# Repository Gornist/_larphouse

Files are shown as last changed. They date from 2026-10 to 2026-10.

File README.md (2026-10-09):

# Модульные игровые дома

Сборно-разборные деревянные дома для ролевых игр (LARP).

- **`step/6/`** — актуальная версия: модульная система на сетке 3,1 м, дома
  3×3, 3×6, 3×9, 6×6. Документация — [`step/6/README.md`](step/6/README.md),
  всё одним файлом для печати — [`step/6/Модульные_дома.pdf`](step/6/Модульные_дома.pdf).
- `step/5/` — предыдущая версия (одиночный дом 3×3), смета с источниками цен —
  `step/5/СТОИМОСТЬ.md`.

## Инструменты

- `tools/grid_house.py` — параметрическая модель v6: STEP, спецификация, смета, инструкция по сборке
- `tools/grid_draw.py` — картинки домов и деталей
- `tools/make_pdf.py` — сборка документации в PDF (pandoc + Chromium)
- `tools/v5_house.py`, `tools/v5_draw.py` — модель и картинки v5 (v6 использует их детали)
- `tools/step_io.py` — запись STEP с русскими названиями

```
pip install build123d scipy pillow
python tools/grid_house.py 6х6 step/6/6х6 step/6/блоки
python tools/grid_draw.py 6х6 step/6/6х6/img
python tools/make_pdf.py step/6 step/6/Модульные_дома.pdf
```

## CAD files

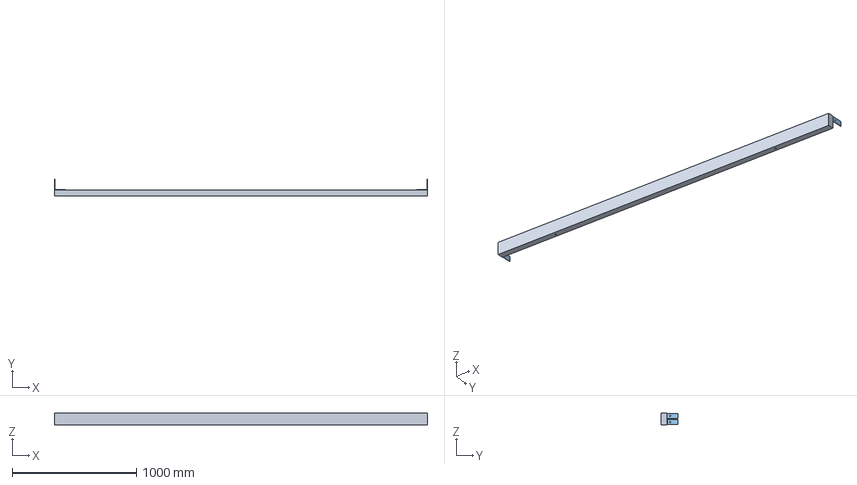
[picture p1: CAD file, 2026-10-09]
step/5/блоки/обвязка_фронтонная.step
3000.0 x 140.0 x 100.0 mm
обвязка_верхняя_ фронтонная_50х100х2996
футорка_М10 x 2
уголок_90х90х40 x 2

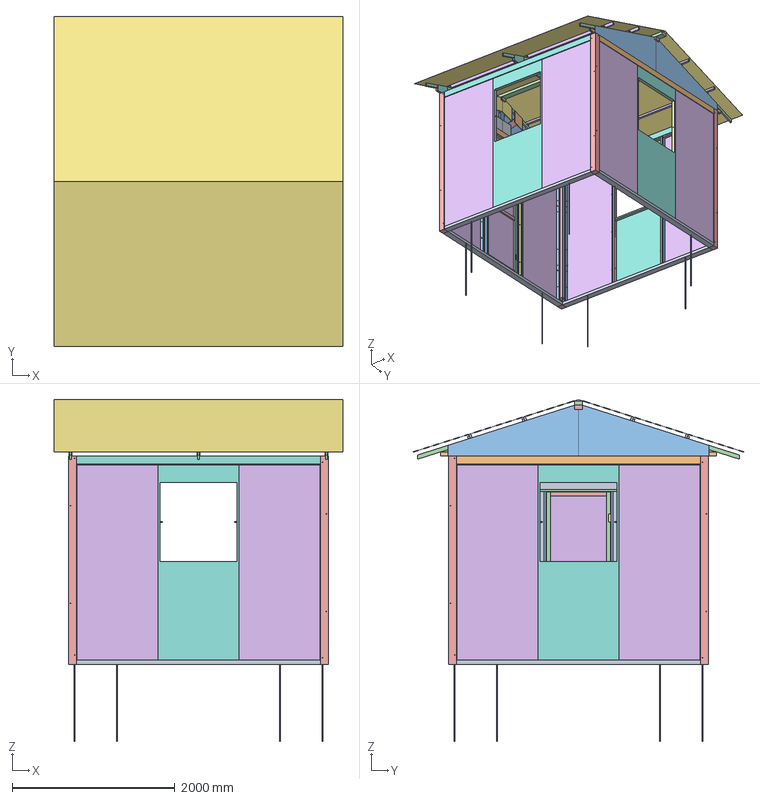
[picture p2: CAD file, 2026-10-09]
step/5/дом_v5_3х3.step
3550.0 x 4060.0 x 4206.2 mm
лежень_50х100х2996 x 4
арматура_12х1000 x 8
уголок_90х90х40 x 16
стойка_угловая_ 100х100х2560 x 4
футорка_М10 x 14
болт_М10х130 x 19
обвязка_верхняя_ карнизная_50х100х2996 x 2
обвязка_верхняя_ фронтонная_50х100х2996 x 2
стойка_щита_25х50х2400 x 24
перемычка_25х50х947 x 31
обшивка_фанера_3мм_ 997х2400 x 12
болт_М10х80 x 38
болт_М10х150 x 16
стойка_двери_25х50х2050 x 2
полотно_стойка_25х50х2040 x 2
полотно_перемычка_ 25х50х690.0 x 3
полотно_фанера_790х2040
петля_100 x 2
ручка
затяжка_25х50х1700 x 6
стойка_фермы_25х50х576 x 6
стропило_25х50х2025 x 6
подкос_25х50х538 x 6
лапка_прогона_25х25х30 x 12
косынка_вершина_ фанера_9 x 8
косынка_пята_фанера_ 9 x 8
косынка_низ_подкоса_ фанера_9 x 8
косынка_верх_ подкоса_фанера_9 x 8
обшивка_фронтона_ фанера_3 x 4
конёк_50х100х3500
бобышка_конька_25х50х100 x 6
прогон_25х50х3500 x 4
тент x 2

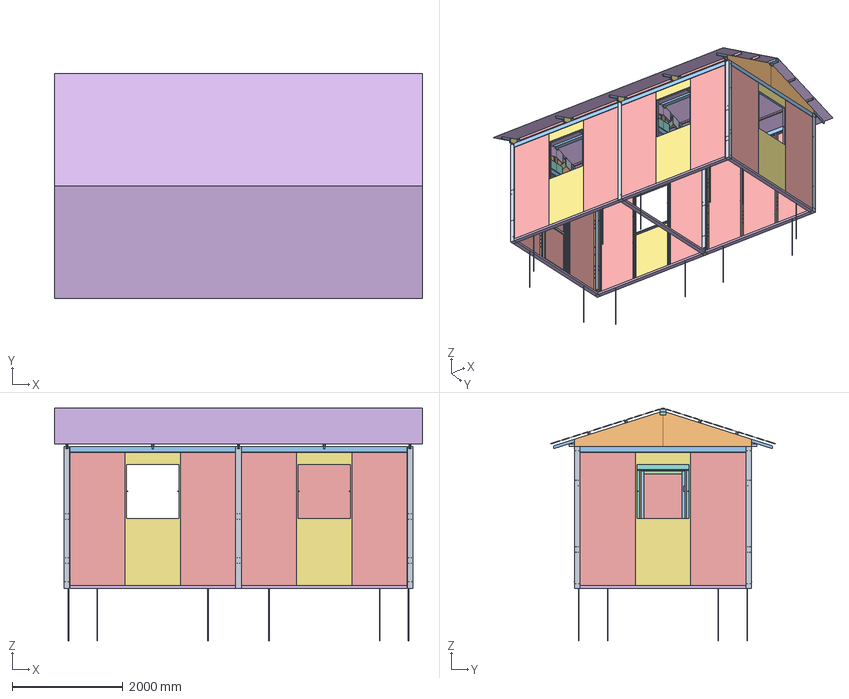
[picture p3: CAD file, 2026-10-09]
step/6/3х6/дом_3х6.step
6650.0 x 4060.0 x 4206.2 mm
стойка_100х100х2560 x 6
футорка_М10 x 48
обвязка_50х100х2996 x 7
уголок_90х90х40 x 28
болт_М10х130 x 29
лежень_50х100х2996 x 7
арматура_12х1000 x 12
стойка_щита_25х50х2400 x 36
перемычка_25х50х947 x 45
обшивка_фанера_3мм_ 997х2400 x 18
болт_М10х80 x 58
болт_М10х150 x 24
стойка_двери_25х50х2050 x 2
полотно_стойка_25х50х2040 x 2
полотно_перемычка_ 25х50х690.0 x 3
полотно_фанера_790х2040
петля_100 x 2
ручка
затяжка_25х50х1700 x 10
стойка_фермы_25х50х576 x 10
стропило_25х50х2025 x 10
подкос_25х50х538 x 10
лапка_прогона_25х25х30 x 20
косынка_фанера_9 x 64
обшивка_фронтона_ ФСФ_3 x 4
конёк_50х100х3300 x 2
бобышка_конька_25х50х100 x 10
прогон_25х50х3300 x 8
тент x 2

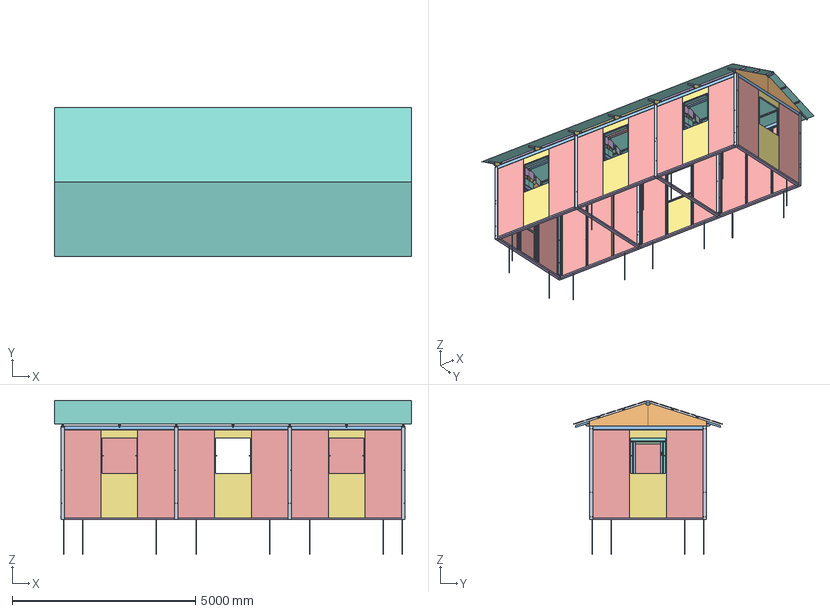
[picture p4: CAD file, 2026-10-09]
step/6/3х9/дом_3х9.step
9750.0 x 4060.0 x 4206.2 mm
стойка_100х100х2560 x 8
футорка_М10 x 68
обвязка_50х100х2996 x 10
уголок_90х90х40 x 40
болт_М10х130 x 39
лежень_50х100х2996 x 10
арматура_12х1000 x 16
стойка_щита_25х50х2400 x 48
перемычка_25х50х947 x 59
обшивка_фанера_3мм_ 997х2400 x 24
болт_М10х80 x 78
болт_М10х150 x 32
стойка_двери_25х50х2050 x 2
полотно_стойка_25х50х2040 x 2
полотно_перемычка_ 25х50х690.0 x 3
полотно_фанера_790х2040
петля_100 x 2
ручка
затяжка_25х50х1700 x 14
стойка_фермы_25х50х576 x 14
стропило_25х50х2025 x 14
подкос_25х50х538 x 14
лапка_прогона_25х25х30 x 28
косынка_фанера_9 x 96
обшивка_фронтона_ ФСФ_3 x 4
конёк_50х100х3300 x 2
бобышка_конька_25х50х100 x 14
конёк_50х100х3100
прогон_25х50х3300 x 8
прогон_25х50х3100 x 4
тент x 2

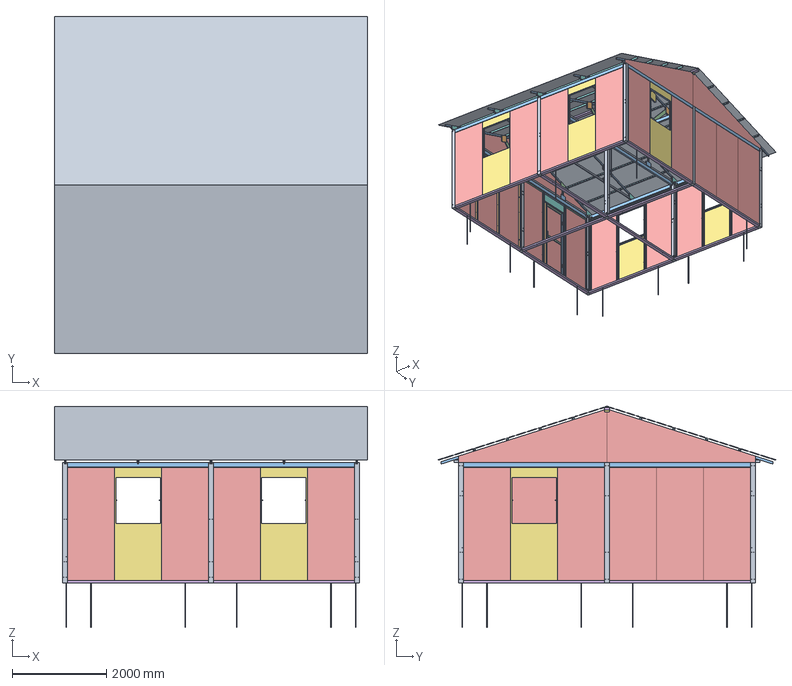
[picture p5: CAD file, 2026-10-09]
step/6/6х6/дом_6х6.step
6650.0 x 7160.0 x 4697.9 mm
стойка_100х100х2560 x 9
футорка_М10 x 81
обвязка_50х100х2996 x 12
уголок_90х90х40 x 48
болт_М10х130 x 41
лежень_50х100х2996 x 12
арматура_12х1000 x 16
стойка_щита_25х50х2400 x 48
перемычка_25х50х947 x 59
обшивка_фанера_3мм_ 997х2400 x 24
болт_М10х80 x 74
болт_М10х150 x 32
стойка_двери_25х50х2050 x 2
полотно_стойка_25х50х2040 x 2
полотно_перемычка_ 25х50х690.0 x 3
полотно_фанера_790х2040
петля_100 x 2
ручка
затяжка_25х50х3250 x 10
стойка_фермы_25х50х1068 x 10
стропило_25х50х3651 x 10
подкос_25х50х1066 x 10
бабка_25х50х420 x 10
лапка_прогона_25х25х30 x 40
косынка_фанера_9 x 96
обшивка_фронтона_ ФСФ_3 x 4
конёк_50х100х3300 x 2
бобышка_конька_25х50х100 x 10
прогон_25х50х3300 x 16
тент x 2

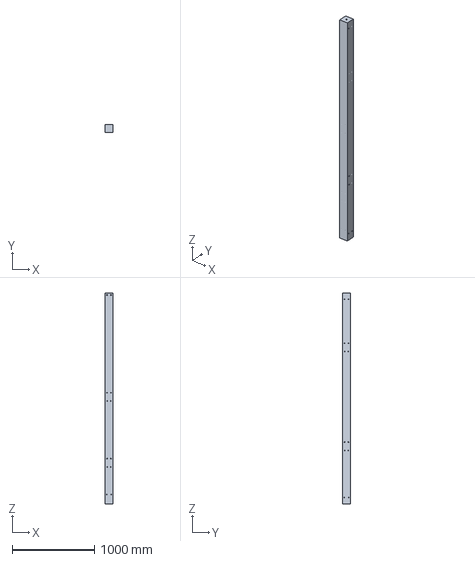
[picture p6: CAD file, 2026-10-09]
step/6/блоки/стойка.step
100.0 x 100.0 x 2560.0 mm
стойка_100х100х2560
футорка_М10

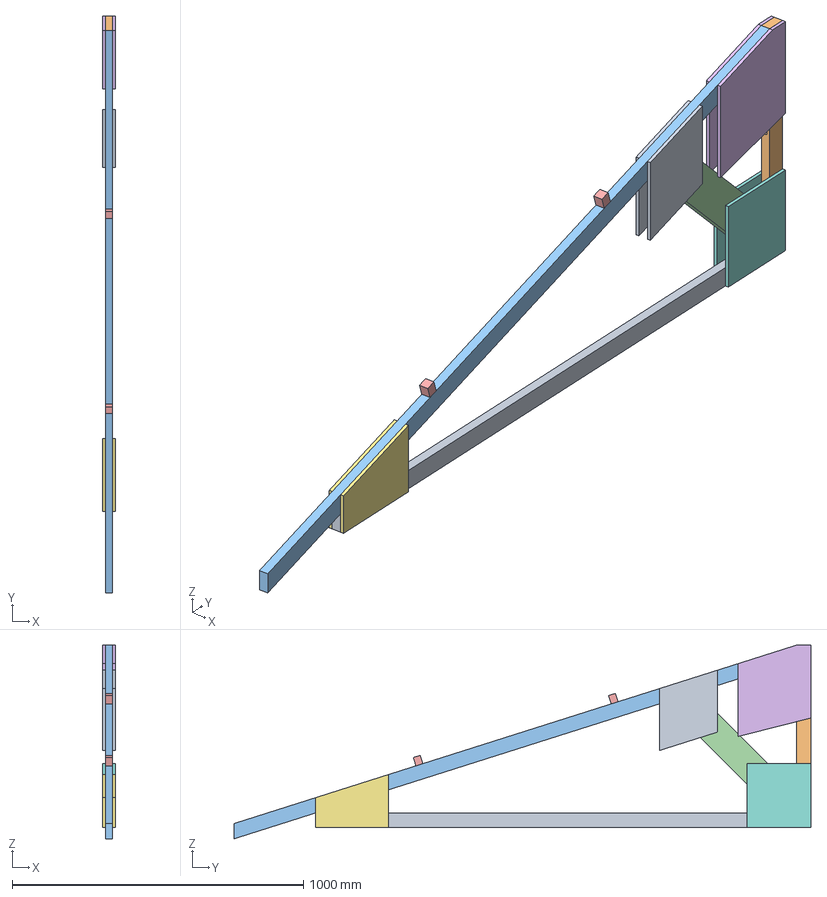
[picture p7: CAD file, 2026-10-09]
step/5/блоки/полуферма_средняя.step
43.0 x 1980.0 x 664.7 mm
затяжка_25х50х1700
стойка_фермы_25х50х576
стропило_25х50х2025
подкос_25х50х538
лапка_прогона_25х25х30 x 2
косынка_вершина_ фанера_9 x 2
косынка_пята_фанера_ 9 x 2
косынка_низ_подкоса_ фанера_9 x 2
косынка_верх_ подкоса_фанера_9 x 2

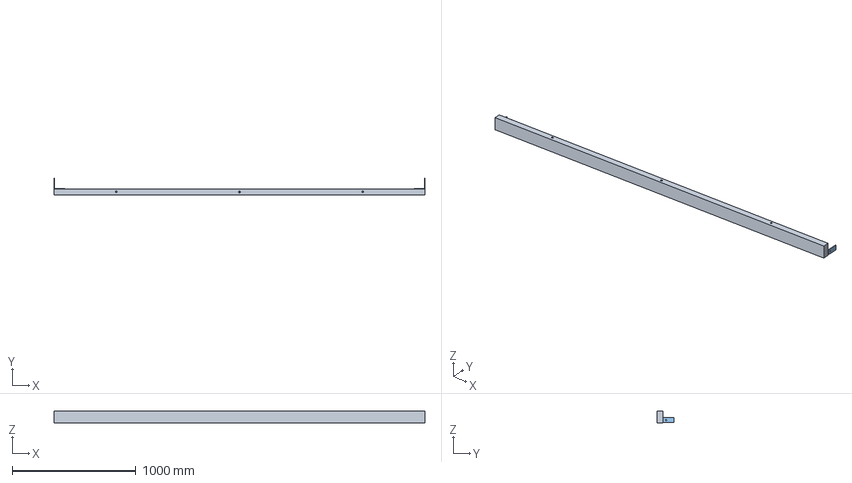
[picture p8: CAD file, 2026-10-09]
step/6/блоки/обвязка.step
3000.0 x 140.0 x 100.0 mm
обвязка_50х100х2996
футорка_М10 x 6
уголок_90х90х40 x 2

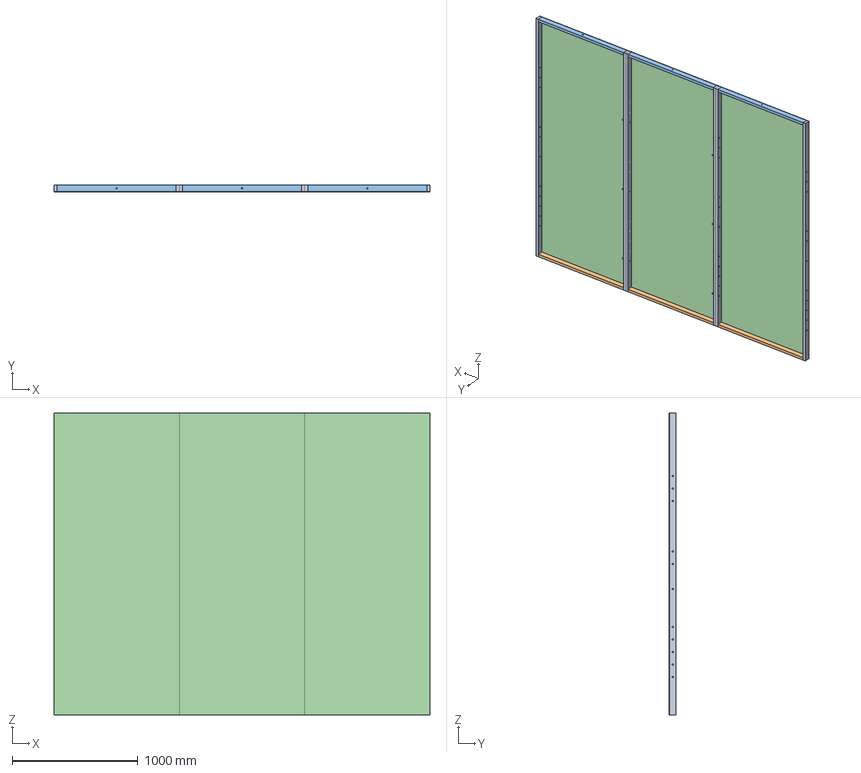
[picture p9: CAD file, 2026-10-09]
step/6/блоки/пролёт_глухой.step
2991.0 x 53.0 x 2400.0 mm
стойка_щита_25х50х2400 x 6
перемычка_25х50х947 x 6
обшивка_фанера_3мм_ 997х2400 x 3
болт_М10х80 x 6

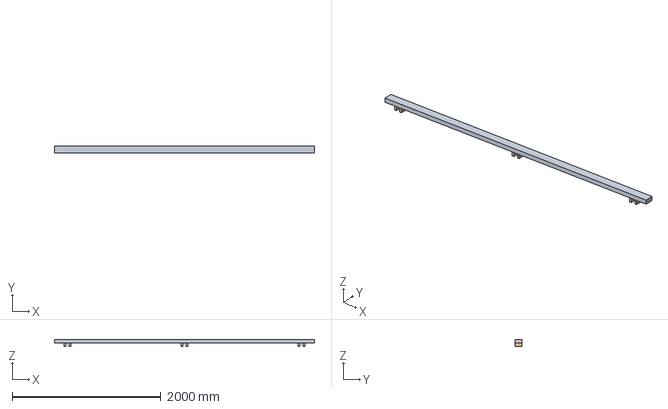
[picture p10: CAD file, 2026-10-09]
step/5/блоки/конёк.step
3500.0 x 100.0 x 100.0 mm
конёк_50х100х3500
бобышка_конька_25х50х100 x 6

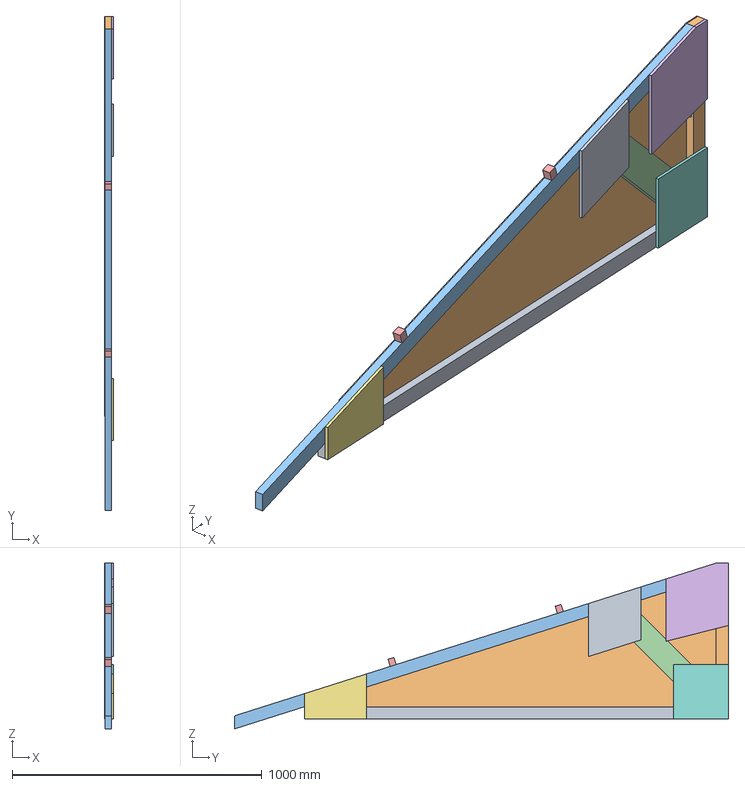
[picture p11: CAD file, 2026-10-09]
step/6/блоки/полуферма_М_фронтон_0.step
37.0 x 1980.0 x 664.7 mm
затяжка_25х50х1700
стойка_фермы_25х50х576
стропило_25х50х2025
подкос_25х50х538
лапка_прогона_25х25х30 x 2
косынка_фанера_9 x 4
обшивка_фронтона_ ФСФ_3

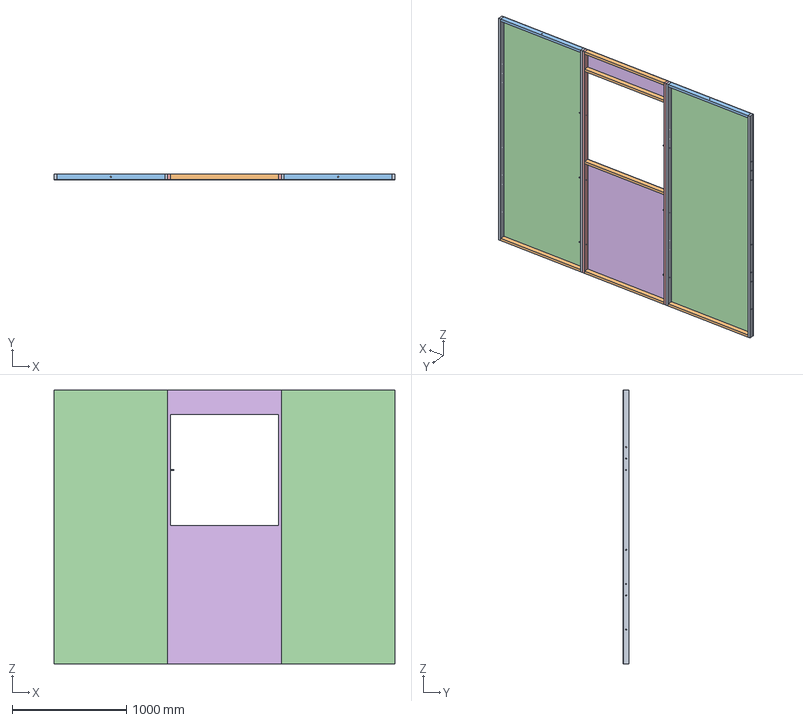
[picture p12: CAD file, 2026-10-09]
step/5/блоки/пролёт_окно.step
2991.0 x 53.0 x 2400.0 mm
стойка_щита_25х50х2400 x 6
перемычка_25х50х947 x 8
обшивка_фанера_3мм_ 997х2400 x 3
болт_М10х80 x 6

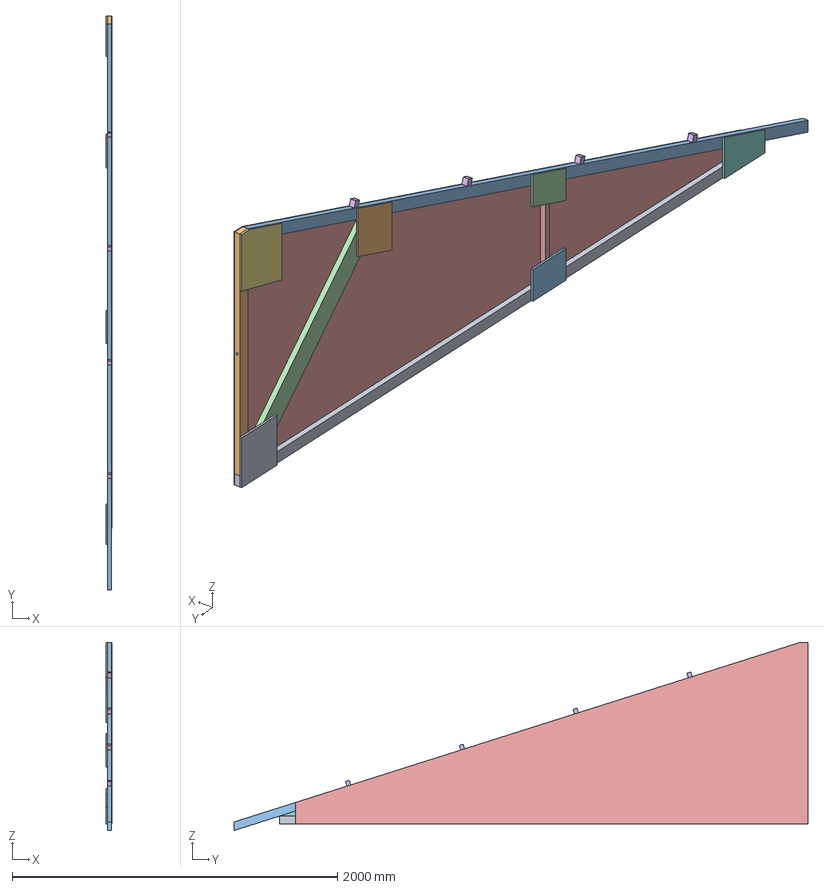
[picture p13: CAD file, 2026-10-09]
step/6/блоки/полуферма_Б_фронтон_25.step
37.0 x 3530.0 x 1156.4 mm
затяжка_25х50х3250
стойка_фермы_25х50х1068
стропило_25х50х3651
подкос_25х50х1066
бабка_25х50х420
лапка_прогона_25х25х30 x 4
косынка_фанера_9 x 6
обшивка_фронтона_ ФСФ_3

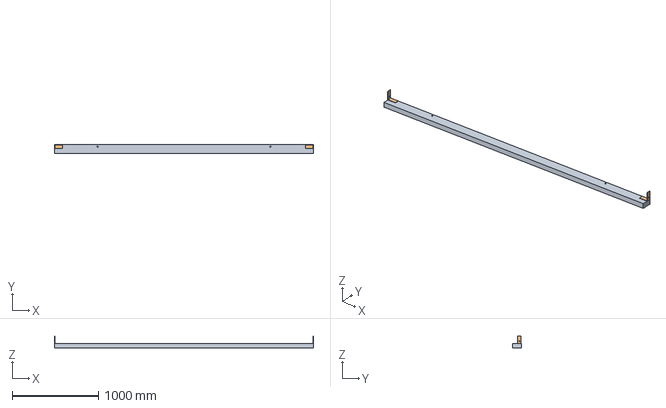
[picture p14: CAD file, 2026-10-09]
step/6/блоки/лежень.step
3000.0 x 100.0 x 140.0 mm
лежень_50х100х2996
уголок_90х90х40 x 2

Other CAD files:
step/6/3х3/дом_3х3.step
step/5/блоки/стойка_угловая.step
step/5/блоки/полуферма_фронтон_25.step
step/5/блоки/полуферма_фронтон_0.step
step/5/блоки/лежень.step
step/5/блоки/обвязка_карнизная.step
step/5/блоки/прогон.step
step/5/блоки/пролёт_дверь.step
step/5/блоки/ригель_карнизный.step
step/5/блоки/ригель_фронтонный.step
step/5/блоки/щит_глухой.step
step/5/блоки/щит_дверь.step
step/5/блоки/щит_окно.step
step/6/блоки/полуферма_Б_средняя.step
step/6/блоки/полуферма_Б_фронтон_0.step
step/6/блоки/полуферма_М_средняя.step
step/6/блоки/полуферма_М_фронтон_25.step
step/6/блоки/пролёт_дверь.step
step/6/блоки/пролёт_окно.step

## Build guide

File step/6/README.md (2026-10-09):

# Модульные игровые дома — документация

Сборно-разборные деревянные дома для ролевых игр. Один набор деталей —
дома любого размера, кратного клетке **3,1 м**. Детали делаются в
мастерской один раз и не разбираются; на площадке всё соединяется
**болтами М10** (большинство — барашками, руками).

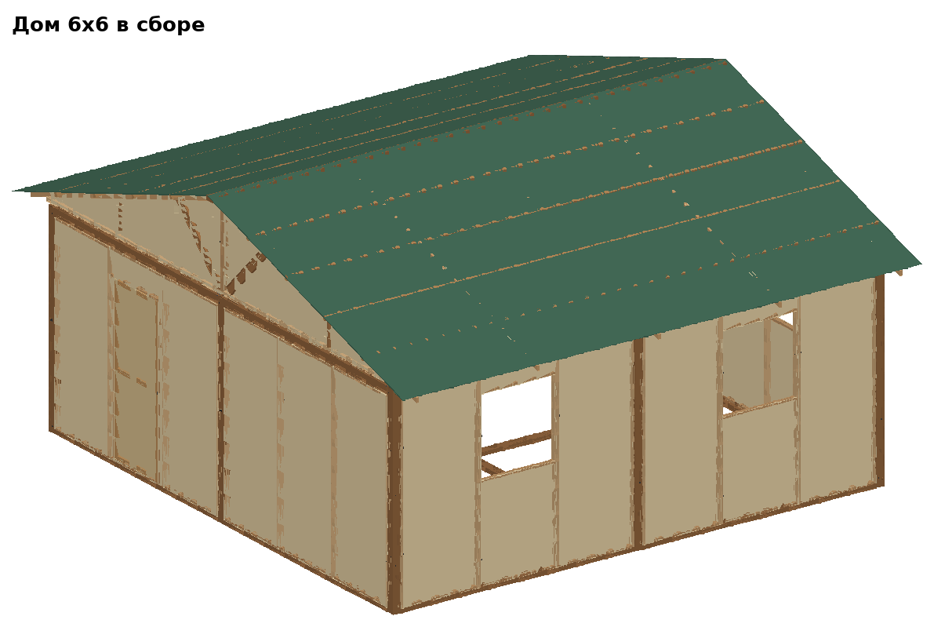
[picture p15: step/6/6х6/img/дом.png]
Дом 6×6


## Документы

| Документ | Что внутри |
|---|---|
| [ДЕТАЛИ.md](ДЕТАЛИ.md) | **Мастерская**: как сделать каждую деталь — щиты, пролёты, стойки, лежни, обвязки, полуфермы, конёк, прогоны |
| [МОНТАЖ.md](МОНТАЖ.md) | **Площадка**: общие правила сборки любого дома, крепёж, инструмент, разборка, перевозка |
| [ЗАКУПКА.md](ЗАКУПКА.md) | Что купить, где, сколько стоит — сводка по всем домам |
| [3х3/СБОРКА.md](3х3/СБОРКА.md) | Сборка дома **3×3** — план, комплект, порядок, болты, время |
| [3х6/СБОРКА.md](3х6/СБОРКА.md) | Сборка дома **3×6** |
| [3х9/СБОРКА.md](3х9/СБОРКА.md) | Сборка дома **3×9** |
| [6х6/СБОРКА.md](6х6/СБОРКА.md) | Сборка дома **6×6** |
| `*/СПЕЦИФИКАЦИЯ_И_СМЕТА.md` | Раскрой, крепёж и смета конкретного дома |
| `*/дом_*.step`, [блоки/](блоки/) | 3D-модели (STEP) — открываются в Fusion 360, FreeCAD, SolidWorks |

## Дома

| Дом | Каркас, м | Высота до конька | Пролётов | Ферм | Масса | Смета* | Монтаж вдвоём** |
|---|---|---|---|---|---|---|---|
| [3×3](3х3/СБОРКА.md) | 3,2 × 3,2 | 3,24 | 4 | 3 малых | 285 кг | ≈ 46 тыс. ₽ | ≈ 1,9 ч |
| [3×6](3х6/СБОРКА.md) | 6,3 × 3,2 | 3,24 | 6 | 5 малых | 450 кг | ≈ 72 тыс. ₽ | ≈ 2,9 ч |
| [3×9](3х9/СБОРКА.md) | 9,4 × 3,2 | 3,24 | 8 | 7 малых | 620 кг | ≈ 98 тыс. ₽ | ≈ 4 ч |
| [6×6](6х6/СБОРКА.md) | 6,3 × 6,3 | 3,73 | 8 | 5 больших | 690 кг | ≈ 108 тыс. ₽ | ≈ 4,1 ч |

\* материалы, средние цены строймагов РФ (октябрь 2026), без запаса;
с запасом 10 % — на 10 % больше. \*\* оценка, вживую не проверена; втроём —
примерно на треть быстрее.

## Как устроена система

```
  ■────────■────────■
  │ пролёт │ пролёт │        ■ — стойка 100×100 в каждом узле сетки
  │        │        │        ─ — лежень внизу + обвязка вверху
  ■────────●────────■        ● — внутренняя стойка
  │        │        │        пролёт — стена из 3 щитов
  │        │        │
  ■────────■────────■        шаг сетки 3100 = стойка 100 + проём 3000
```

1. **Каркас.** В каждом узле сетки — **стойка**, соседние клетки делят
   общие стойки. Между любыми двумя соседними стойками внизу — **лежень**,
   вверху — **обвязка**, оба на стальных уголках и болтах.
2. **Стены.** В проём каркаса по периметру ставится **пролёт** — три
   **щита**, стянутых болтами. Пролёты бывают глухие, с окном, с дверью и
   встают в любой проём. Внутренние проёмы открыты.
3. **Крыша.** Двускатная, конёк вдоль длинной стороны. **Фермы** (каждая из
   двух полуферм) стоят на обвязке через 1,55 м; сверху — **конёк**,
   **прогоны** и **тент**.
   * Дом шириной в 1 клетку (3×3, 3×6, 3×9 …) — **малые** полуфермы.
   * Шириной в 2 клетки (6×6, 6×9 …) — **большие** полуфермы, конёк держит
     средняя линия стоек (в зале — столб).

Стойки, лежни, обвязки, щиты, пролёты и полуфермы **одинаковые для любого
дома**. Например, из двух комплектов 3×3 собирается 3×6: остаются лишними
2 стойки, лежень, обвязка, 2 пролёта и 2 фронтонные фермы, не хватает одной
средней фермы. Конёк и прогоны у длинных домов режутся кусками по клетке
(3300/3100 мм), у 3×3 — один кусок 3500.

## Словарик

| Слово | Что это |
|---|---|
| **Щит** | Рама 997 × 2400 из бруска 25×50 на ребро, снаружи — фанера ФСФ 3 мм. Глухой, с окном, с дверью. |
| **Пролёт** | Три щита на болтах — стена 2991 × 2400 × 53 между двумя стойками. |
| **Стойка** | Брус 100×100×2560 в узле сетки. Все стойки одинаковые. |
| **Лежень** | Брус 50×100×2996 на земле между двумя стойками, на него ставится пролёт. |
| **Обвязка** | Брус 50×100×2996 на ребро между верхами двух стоек, на неё встают фермы. Одна деталь на все места; поперёк конька её ставят перевёрнутой. |
| **Уголок** | Стальной крепёжный уголок KUU 90×90×40 — держит лежень и обвязку на стойке. |
| **Ферма / полуферма** | Треугольник под крышу. Ферма = 2 полуфермы на одном болте. Крайние фермы (фронтонные) зашиты фанерой. |
| **Конёк, прогон** | Брус 50×100 по верху ферм и рейки 25×50 поперёк ферм — под тент. |
| **Косынка** | Фанерная накладка 9 мм на узле фермы (клей + саморезы). |
| **Футорка** | Врезная гайка М10 — втулка с резьбой, вкручивается в дерево. |
| **Барашек** | Гайка М10 с «ушками», крутится рукой. |
| **Клетка** | Квадрат сетки 3,1 × 3,1 м между четырьмя стойками. |

## Модели и генератор

Всё — модели, раскрой, сметы, инструкции по сборке и картинки —
генерируется скриптами из одной параметрической модели:

```
pip install build123d scipy pillow
python tools/grid_house.py 6х6 step/6/6х6 step/6/блоки   # STEP, смета, СБОРКА.md
python tools/grid_draw.py 6х6 step/6/6х6/img              # картинки дома
python tools/grid_draw.py детали step/6/img_детали        # картинки деталей
```

Новый размер — одна строка в `CONFIGS` (`tools/grid_house.py`): число клеток
по X (вдоль конька, любое) и по Y (1 или 2) и что стоит в каждом проёме
периметра. Модели проверены на пересечения деталей и на то, что каждый болт
проходит через нужные детали с запасом под гайку.

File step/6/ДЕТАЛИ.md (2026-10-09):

# Детали — изготовление в мастерской

Все детали делаются один раз и **не разбираются**. Сколько каких деталей
нужно для конкретного дома — в его `СБОРКА.md` и `СПЕЦИФИКАЦИЯ_И_СМЕТА.md`.

## Общие правила

* **Материалы**: брусок 25×50 сухой строганый, брус 100×100, доска/брус
  50×100, фанера **ФСФ 3 мм** 1220×2440 (обшивка) и **ФК 9 мм** (косынки).
* **Соединения внутри деталей** — клей ПВА D3 + саморезы: узлы рам и ферм —
  5×70, косынки и уголки — 4×40, фанера обшивки — 3,5×25 через 150 мм.
* **Отверстия под болты М10 — сверло 11 мм**, под футорки — 14 мм.
  Одинаковые детали сверлить **по кондуктору** (шаблон из доски с
  просверленными отверстиями), иначе детали не будут подходить к любому месту.
* Футорка М10 вкручивается шестигранником (или забивается — усовая).
* **Антисептик** — на все деревянные детали до сборки, особенно лежни и
  торцы. Фанеру ФСФ можно покрасить фасадной краской — не обязательно.
* **Маркировка** краской на каждой детали: тип, «верх», «наружу».

Размеры в мм. Высоты отверстий — **от низа детали**, если не сказано иное.

---

## 1. Щиты

| Глухой | С окном | С дверью |
|---|---|---|
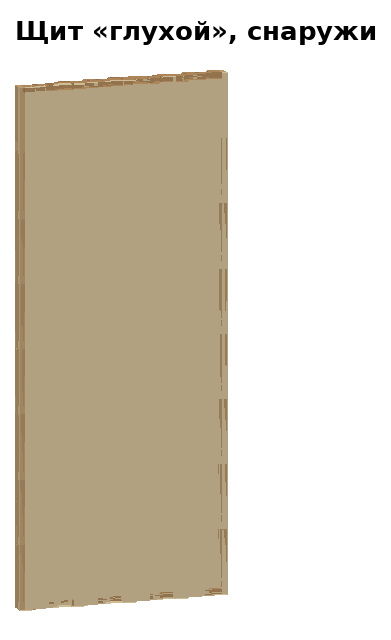
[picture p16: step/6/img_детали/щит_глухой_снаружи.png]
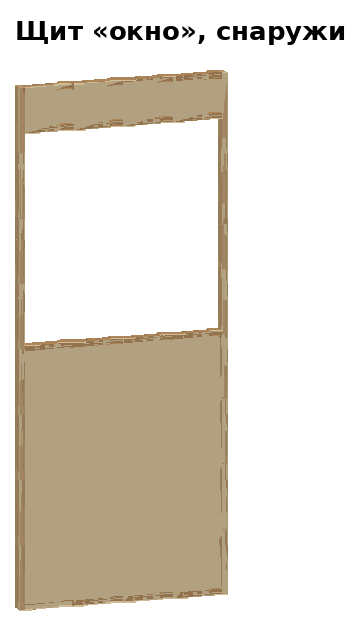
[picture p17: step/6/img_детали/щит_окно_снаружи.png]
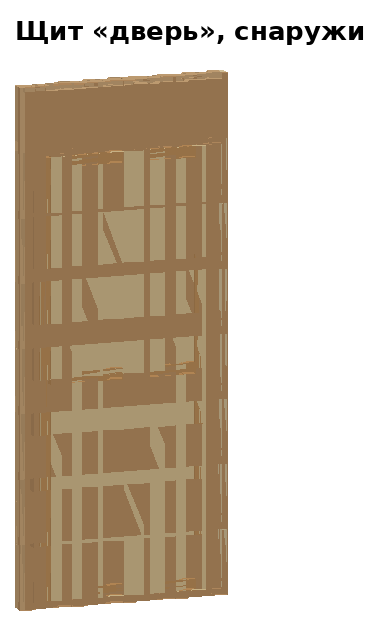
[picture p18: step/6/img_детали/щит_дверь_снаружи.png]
|  |  |  |
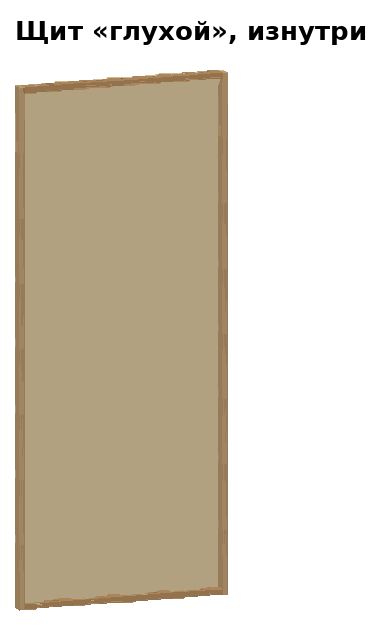
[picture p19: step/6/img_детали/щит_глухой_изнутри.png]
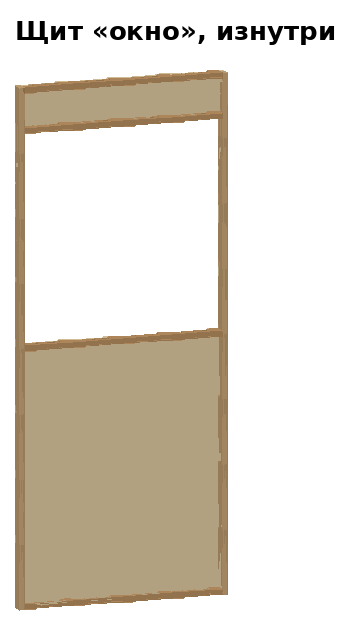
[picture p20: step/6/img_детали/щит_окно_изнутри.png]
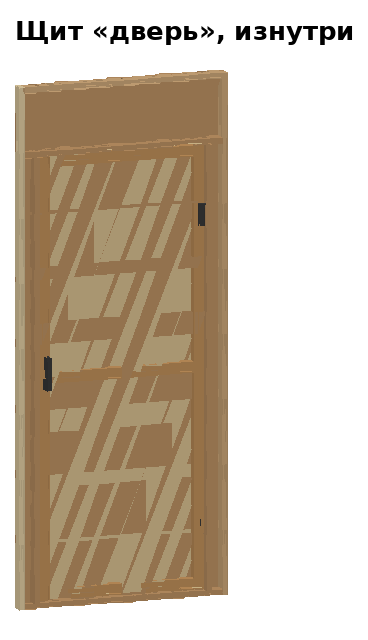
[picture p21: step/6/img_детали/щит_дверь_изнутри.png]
|  |  |  |

**Общее для всех щитов** (997 × 2400 × 50 + фанера 3 мм):
1. Рама: 2 стойки 25×50×2400 + 2 перемычки 25×50×947 (низ и верх),
   брусок **на ребро** (толщина рамы 50). Углы — клей + 2 самореза 5×70.
2. Отверстия 11 мм поперёк обеих стоек, посередине толщины, на высоте
   **300, 1000, 1700** — стяжка щитов в пролёт.
3. Обшивка снаружи — лист ФСФ 3 мм 1220×2440, обрезанный до 997×2400, на
   клей и саморезы 3,5×25 через 150 мм. Фанера держит щит от перекоса —
   диагонали не нужны.

**Глухой** (идёт по краям каждого пролёта) — дополнительно:
* в обеих стойках ещё отверстия на **400, 500, 600, 700, 1200, 1300, 1800,
  1900** — болты к стойкам каркаса (используется 2 из 8, в зависимости от
  места пролёта — поэтому любой пролёт встаёт в любой проём);
* в верхней перемычке посередине — вертикальное отверстие 11 мм (болт к
  обвязке).

**С окном**: ещё 2 перемычки 947 — низ на 1187,5 и 2187,5. Вырез в фанере
947 × 975 (проём от 1212,5 до 2187,5).

**С дверью**: 2 стойки 25×50×2050 (в 73,5 и 898,5 от левого края, от
нижней перемычки), перемычка 947 на высоте 2075. Проём **800 × 2050**,
порог 25. Полотно 790 × 2040: рамка из бруска 25×50 плашмя (2 × 2040 +
3 × 690) + ФСФ 3 мм; 2 петли 100 мм на левую стойку, ручка-скоба, шпингалет.

## 2. Пролёты

| Окно | Глухой | Дверь |
|---|---|---|
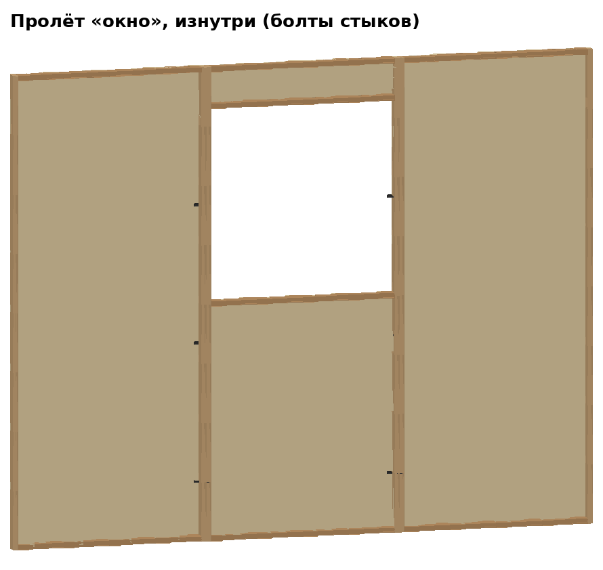
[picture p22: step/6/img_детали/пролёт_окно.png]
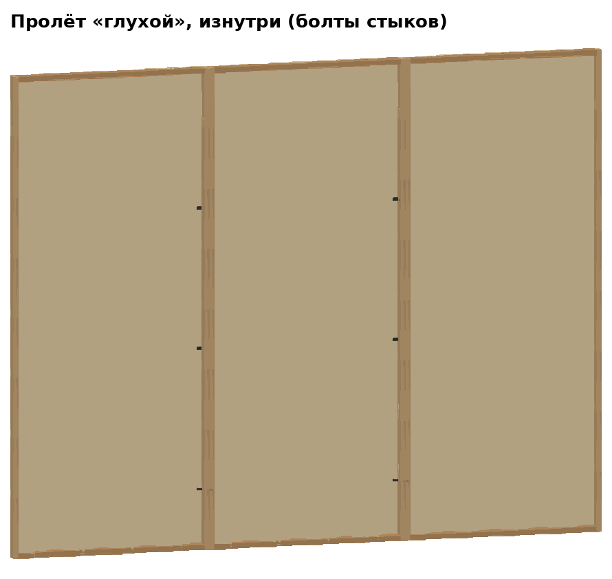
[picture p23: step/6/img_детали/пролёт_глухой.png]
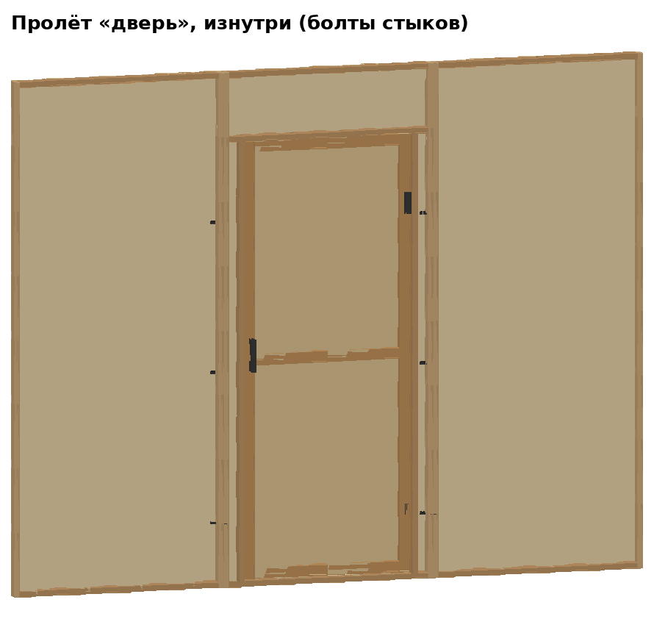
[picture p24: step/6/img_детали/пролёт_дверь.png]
|  |  |  |

Пролёт = **глухой щит + средний щит + глухой щит**, стойки вплотную:

| Пролёт | Средний щит |
|---|---|
| «окно» | с окном |
| «глухой» | глухой |
| «дверь» | с дверью |

На каждом стыке — **3 болта М10×80 с гайкой и шайбами** (высота 300, 1000,
1700), всего 6 на пролёт. Готовый пролёт 2991 × 2400 × 53, масса 25–34 кг.
Если пролёт не влезает в транспорт — везти щитами и стягивать на месте.

## 3. Стойка

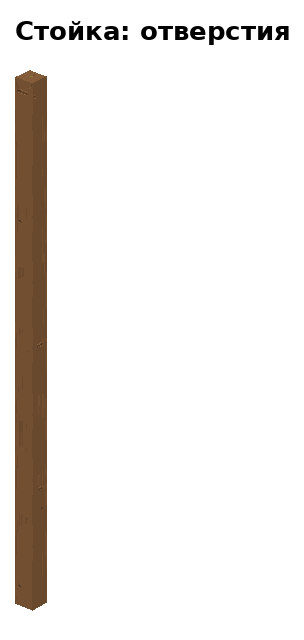
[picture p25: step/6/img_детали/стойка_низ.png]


**Брус 100×100×2560**, все стойки одинаковые — угловые, в середине стены и
в центре. Стойки не поворачиваются: «X» — направление вдоль конька, «Y» —
поперёк; стойку ставят меткой «X» вдоль конька.

Сквозные отверстия 11 мм. Каждое — **парой**, симметрично относительно
середины стойки (на указанном расстоянии от одной грани и от противоположной):

| Назначение | Направление X: высота / от грани | Направление Y: высота / от грани |
|---|---|---|
| Уголок лежня | 80 / 23 и 77 | 115 / 23 и 77 |
| Пролёт, левый край | 650 и 1850 / 28 и 72 | 450 и 1250 / 28 и 72 |
| Пролёт, правый край | 750 и 1950 / 28 и 72 | 550 и 1350 / 28 и 72 |
| Уголок обвязки | 2485 / 25 и 75 | 2535 / 25 и 75 |

Итого 24 отверстия (12 в каждом направлении); разные высоты для X и Y — чтобы
отверстия не пересекались внутри стойки. **Сверлить по кондуктору**: короб из
досок, надеваемый на стойку, с отверстиями-направляющими.

Сверху по центру — отверстие 14 мм глубиной 36, футорка М10 (пята фермы).

## 4. Лежень

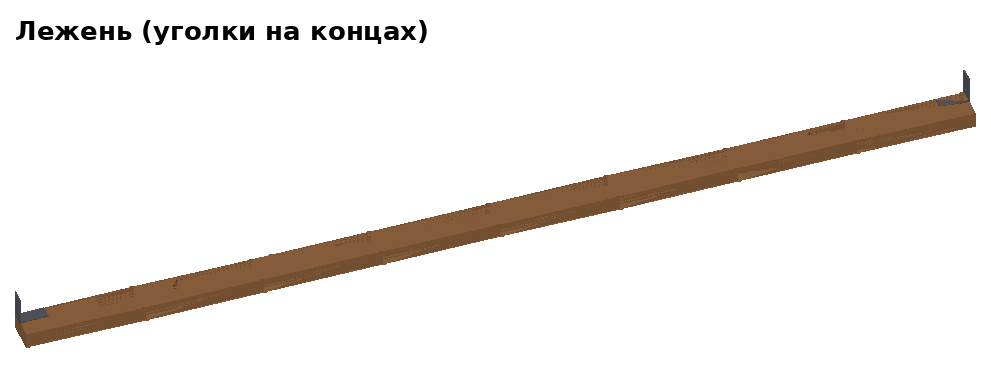
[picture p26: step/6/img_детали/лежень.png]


**Брус 50×100×2996**, кладётся плашмя. Все лежни одинаковые.
* На обоих концах сверху — **уголок KUU 90×90×40**: вертикальная полка
  вровень с торцом лежня (смотрит на стойку), полка по ширине — от 57 до 97
  мм от наружной кромки. Саморезы 4×40.
* В вертикальной полке уголка нужны отверстия на высоте **30 и 65 мм** над
  лежнем (у KUU отверстия есть; если не совпали — досверлить 11 мм).
  Лежень вдоль конька крепится через нижнее (30), поперёк — через верхнее
  (65): так все лежни одинаковые.
* 2 отверстия 14 мм под колья — в 498 мм от концов, в 77 мм от наружной
  кромки (используются у лежней по периметру).

## 5. Обвязка

| Вдоль конька | Поперёк конька (перевёрнута) |
|---|---|
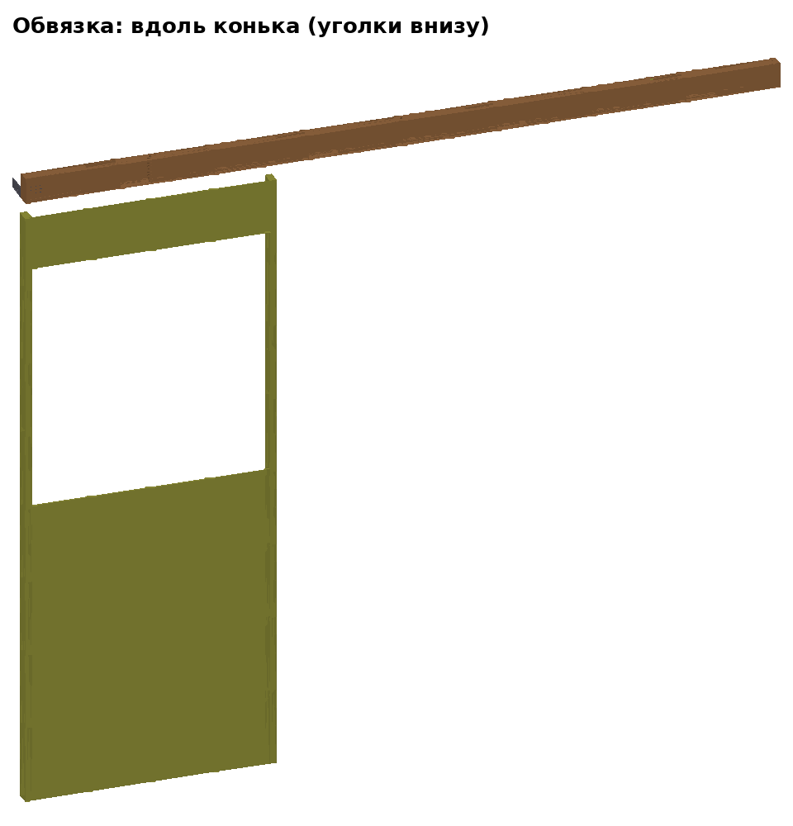
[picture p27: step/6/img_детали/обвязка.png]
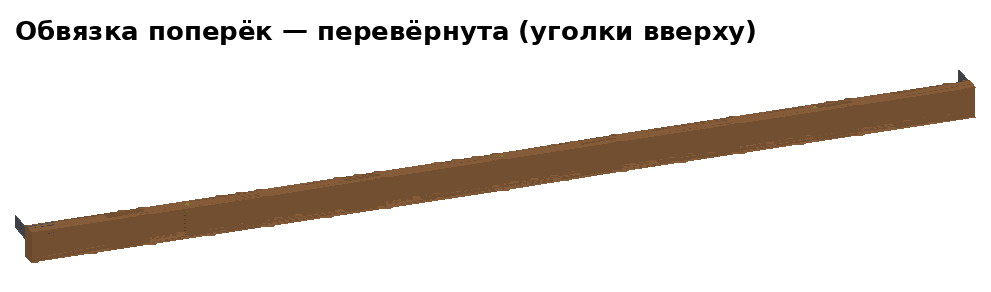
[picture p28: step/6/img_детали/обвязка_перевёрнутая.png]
|  |  |

**Брус 50×100×2996 на ребро**, одна деталь на все места.
* На обоих концах на внутренней грани — **уголок KUU 90×90×40**:
  вертикальная полка вровень с торцом, по высоте — от 5 до 45 мм от нижней
  грани; отверстие уголка — на 25 мм от низа.
* **6 футорок М10**: по три на нижней и верхней грани — в 501, 1498 и 2495
  мм от конца, в 28 мм (крайние) и 25 мм (средняя) от наружной грани.
  Нижние — под болты пролёта, верхняя средняя — под пяту фермы.
* **Вдоль конька** обвязка ставится уголками вниз. **Поперёк конька** —
  переворачивается (уголками вверх): уголки оказываются на высоте 75 мм от
  низа — как раз под отверстия «Y» в стойке, футорки меняются местами.

## 6. Полуфермы

Брусок 25×50 **на ребро**, все детали в одной плоскости. Узлы — **фанерные
косынки 9 мм** на клей и саморезы 4×40: у средних полуферм — с двух сторон,
у фронтонных — с внутренней. На стропиле — **лапки** 25×25×30 под прогоны.

### 6.1 Малые (дома шириной 3 м: 3×3, 3×6, 3×9)

| Средняя | Фронтонная А | Фронтонная Б |
|---|---|---|
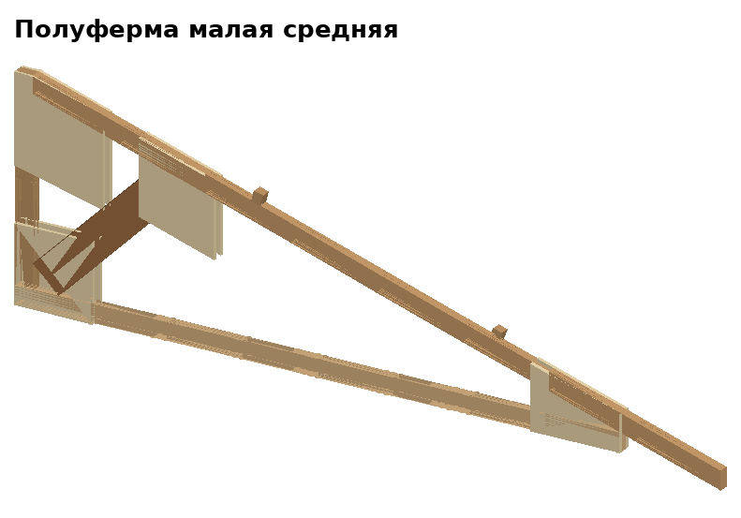
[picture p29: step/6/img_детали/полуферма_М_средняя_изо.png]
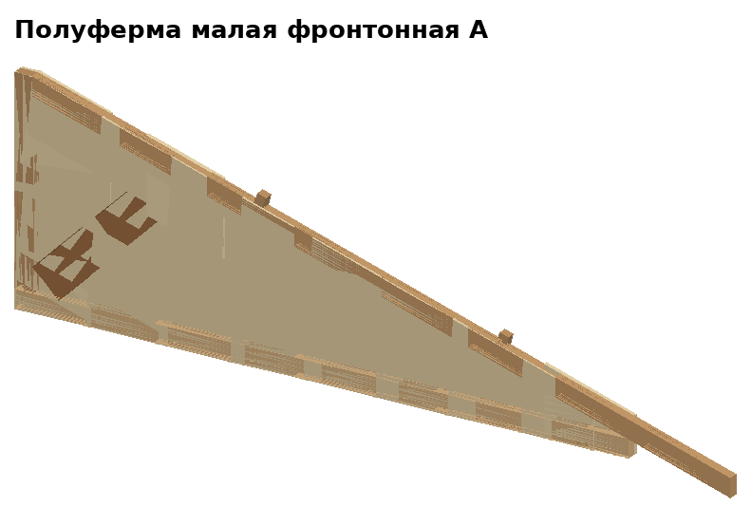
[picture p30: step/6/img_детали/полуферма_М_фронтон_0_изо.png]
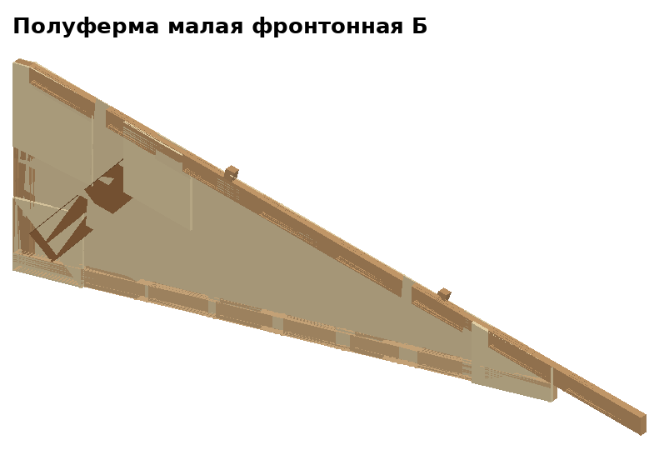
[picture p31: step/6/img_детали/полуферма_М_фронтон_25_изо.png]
|  |  |  |

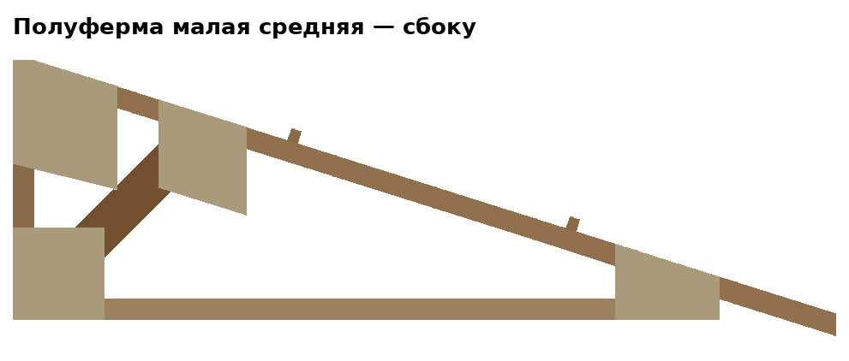
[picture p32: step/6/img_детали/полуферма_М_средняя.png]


| Деталь | Длина | Как стоит |
|---|---|---|
| Затяжка | 1700 | горизонтально |
| Стойка | 576 | вертикально на коньковом конце затяжки |
| Стропило | 2025 | верх — вертикальный рез в стойку; низ — вертикальный рез, свес ≈ 380 за стену |
| Подкос | 538 | из угла затяжка/стойка под 45° до стропила |

* Отверстия 11 мм: в затяжке — вертикальные на **1550 и 1575** от
  конькового конца (пята на стойке / на обвязке); в стойке — поперёк
  посередине (болт пары).
* Лапки — на 650 и 1320 от конька.

### 6.2 Большие (дома шириной 6 м: 6×6, 6×9)

| Средняя | Фронтонная А | Фронтонная Б |
|---|---|---|
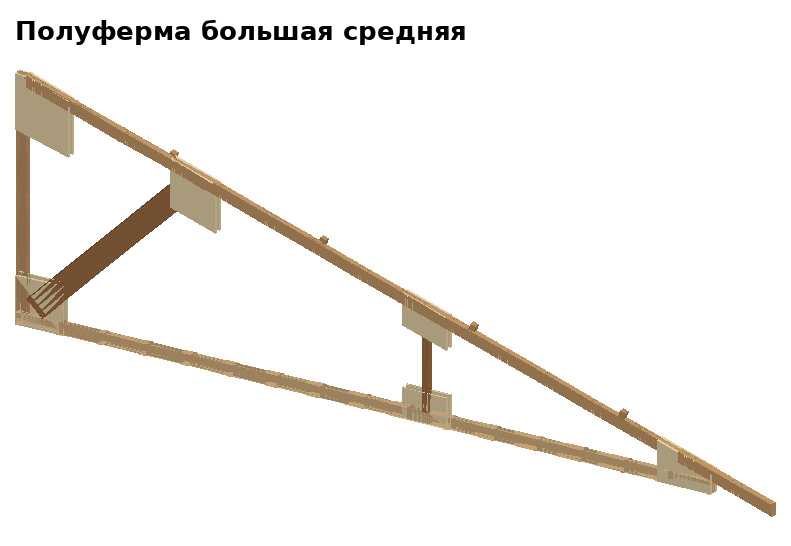
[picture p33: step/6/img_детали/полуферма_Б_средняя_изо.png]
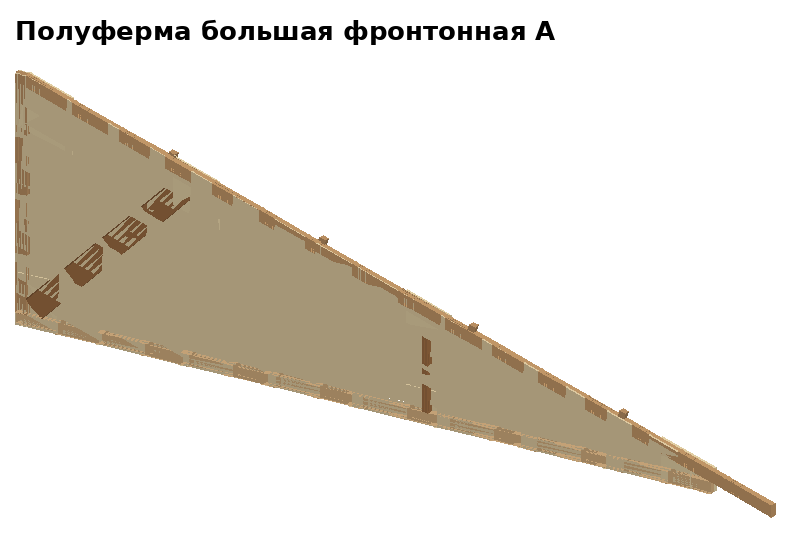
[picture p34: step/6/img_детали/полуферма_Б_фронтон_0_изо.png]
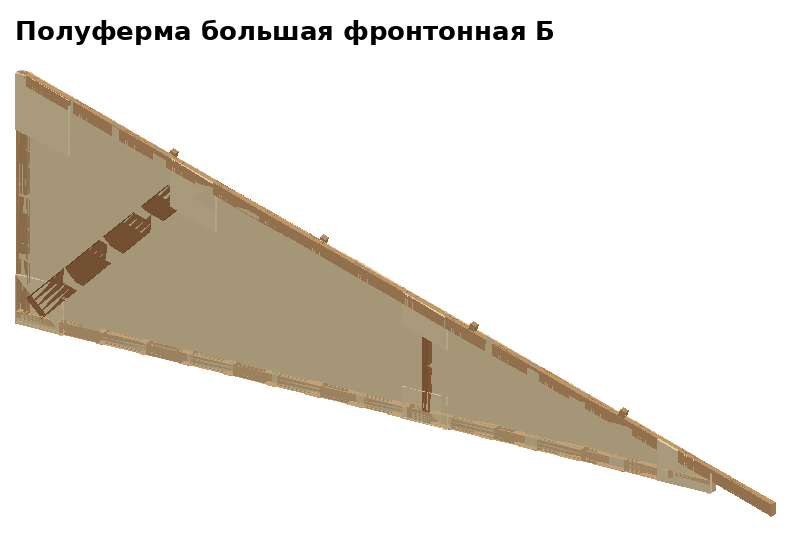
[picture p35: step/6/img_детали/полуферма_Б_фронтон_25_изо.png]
|  |  |  |

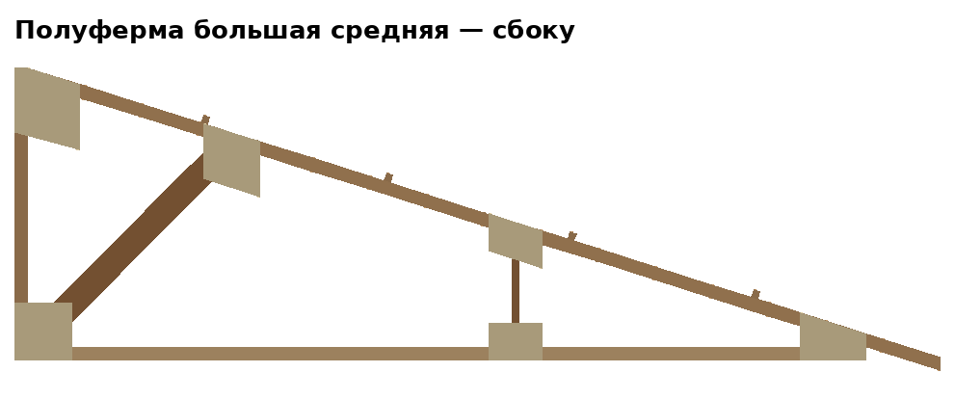
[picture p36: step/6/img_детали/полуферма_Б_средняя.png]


| Деталь | Длина | Как стоит |
|---|---|---|
| Затяжка | 3250 | горизонтально |
| Стойка | 1068 | вертикально на коньковом конце |
| Стропило | 3651 | как у малой, свес ≈ 380 |
| Подкос | 1066 | из угла под 45° до стропила |
| Бабка | 420 | вертикальная распорка на 1900 от конька |

* Отверстия 11 мм в затяжке — на **3100 и 3125** от конькового конца;
  в стойке — поперёк посередине.
* Лапки — на 700, 1400, 2100, 2800 от конька.

### Фронтонные А и Б

Крайние фермы дома **зашиты снаружи фанерой ФСФ 3 мм** (треугольник до
наружной грани стены) — это фронтоны. А и Б — зеркальные: фанера на разных
сторонах. В ферме фронтона всегда пара **А + Б**, фанерой наружу дома.

## 7. Конёк и прогоны

* **Конёк** — брус 50×100 плашмя: у дома 3×3 — один кусок 3500, у длинных —
  кусками по клетке (крайние 3300, средние 3100), стыки — над фермами на
  линиях стоек.
* Снизу у конька — **бобышки** 25×50×100 по обе стороны от каждой фермы
  (просвет 45 мм): конёк ложится на фермы и не сползает.
* **Прогоны** — брусок 25×50 на ребро, такими же кусками; ложатся в лапки
  стропил. 2 на скат у малых ферм, 4 — у больших.

## 8. Кондукторы (сделать один раз)

| Кондуктор | Для чего |
|---|---|
| Короб на стойку 100×100 | 24 отверстия стойки |
| Планка на стойку щита | отверстия 300/1000/1700 (+ 400…1900 у глухих) |
| Планка на обвязку | 6 футорок |
| Шаблон полуфермы на полу (обрезки, прибитые к щиту) | одинаковые полуфермы |

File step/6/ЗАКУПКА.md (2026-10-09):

# Закупка и стоимость

Средние розничные цены строймагов РФ (Лемана ПРО / Леруа, Петрович, Сдвор,
ОБИ, Максидом, Бауцентр, ВсеИнструменты), октябрь 2026, по поисковой выдаче
из разных городов. Источники — в [../5/СТОИМОСТЬ.md](../5/СТОИМОСТЬ.md).
Подробная смета каждого дома — в его `СПЕЦИФИКАЦИЯ_И_СМЕТА.md`.

## Сводка, ₽

| | 3×3 | 3×6 | 3×9 | 6×6 |
|---|---|---|---|---|
| Пиломатериалы | 22 300 | 35 300 | 48 200 | 55 300 |
| Фанера (ФСФ 3 мм + ФК 9 мм) | 6 400 | 9 500 | 12 600 | 13 400 |
| Крепёж (болты, гайки, шайбы, футорки, уголки) | 6 700 | 10 500 | 14 300 | 15 300 |
| Прочее (тент, ремни, колья, саморезы, клей, антисептик, дверь) | 10 200 | 16 400 | 22 600 | 24 000 |
| **Итого** | **≈ 46 000** | **≈ 72 000** | **≈ 98 000** | **≈ 108 000** |
| С запасом 10 % | ≈ 50 000 | ≈ 79 000 | ≈ 108 000 | ≈ 119 000 |
| За м² каркаса | ≈ 4 500 | ≈ 3 600 | ≈ 3 300 | ≈ 2 700 |

Чем больше дом, тем дешевле квадратный метр: стойки и стены по периметру
растут медленнее площади. Самая выгодная по площади — **6×6**.

## Основные позиции

| | 3×3 | 3×6 | 3×9 | 6×6 |
|---|---|---|---|---|
| Брусок 25×50 (3–4 м) | 50 шт | 59 шт | 79 шт | 94 шт |
| Брус/доска 50×100×6000 | 5 | 9 | 13 | 14 |
| Брус 100×100×3000 | 4 | 6 | 8 | 9 |
| Фанера ФСФ 3 мм 1220×2440 | 15 | 21 | 27 | 29 |
| Болты М10 ×80 / ×130 / ×150 (с запасом 10 %) | 42 / 21 / 18 | 64 / 32 / 27 | 86 / 43 / 36 | 82 / 46 / 36 |
| Тент тарпаулин | 4×5 | ≥ 7×5 | ≥ 10×5 | ≥ 7×8 |

Точные количества (в т. ч. болтов, уголков, футорок) — в смете каждого дома.

## Где брать

| Что | Где | Комментарий |
|---|---|---|
| Брусок 25×50 сухой строганый | лесобазы, Петрович/Сдвор (аналоги 20×45, 30×50) | в сетях мало; на лесобазе в ~2 раза дешевле |
| Брус 100×100, доска 50×100 | Петрович, Сдвор, лесобазы | у Леманы дороже в 1,5–2 раза; 6-метровые выгоднее |
| **Фанера ФСФ 3 мм 1220×2440** | **фанерные базы** (Пиломаркет, Доски-Строй и т. п.) | в сетях почти нет; 4/4 — 350–390 ₽; если нет 3 мм — ФСФ 4 мм |
| Фанера ФК 9 мм 1525×1525 | любой строймаг | на косынки ферм |
| Болты, гайки, барашки, шайбы М10 | ВсеИнструменты, ОБИ, Петрович — **упаковками** | поштучно в 2–3 раза дороже |
| Футорки М10 вкручиваемые | крепёжные магазины, ВсеИнструменты | в сетях редко |
| Уголки KUU 90×90×40 | любой строймаг | маркировка «KUU», не «KUL» |
| Арматура Ø12 | строймаг (прутки 2,92 или 5,85 м) | режется на колья по 1 м |
| Тент тарпаулин 180 г/м² | Лемана, автомагазины | для больших домов — 8×10 и подвернуть |

## Экономия

* **Лес с лесобазы** — минус 25–40 % от сметы (пиломатериалы — самая
  большая статья).
* **Крепёж упаковками** по 50–100 шт.
* **Брус 100×100 по 6 м** (2 стойки из одного) — дешевле, чем по 3 м.
* Если делать сразу несколько домов — общий набор кондукторов и оптовая
  закупка фанеры.

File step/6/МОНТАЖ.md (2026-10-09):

# Монтаж — общие правила для любого дома

Порядок одинаковый для всех домов системы. Конкретный дом — план, сколько
чего и сколько болтов — в его `СБОРКА.md`:
[3×3](3х3/СБОРКА.md) · [3×6](3х6/СБОРКА.md) · [3×9](3х9/СБОРКА.md) · [6×6](6х6/СБОРКА.md).

## Люди и инструмент

* **2 человека** (дом 6×6 и большие фермы — лучше 3).
* Ключ на 17 (рожковый + накидной), стремянка 1,5–2 м (2 шт. для ферм),
  кувалда (колья), уровень, рулетка 5 м, шнур.
* Барашки затягиваются рукой; ключ нужен только для болтов в футорки и
  гаек в пролётах.

## Крепёж — все болты М10

| Болт | Где на площадке |
|---|---|
| **М10×130 + барашек** | уголки лежней и обвязок к стойкам (сквозь стойку); пара полуферм в ферму |
| **М10×150 + барашек** | пролёт к стойкам (сквозь стойку в крайнюю стойку пролёта) |
| **М10×80** | пролёт к обвязке (изнутри снизу в футорку); пяты ферм (в футорку стойки или обвязки) |

На каждый болт — увеличенная шайба под головку и под гайку/барашек.
Головка болта — снаружи дома, барашек — внутри.
**Болт в середине стены и в центре** проходит сквозь стойку и держит уголки
с обеих сторон сразу.

## Порядок сборки

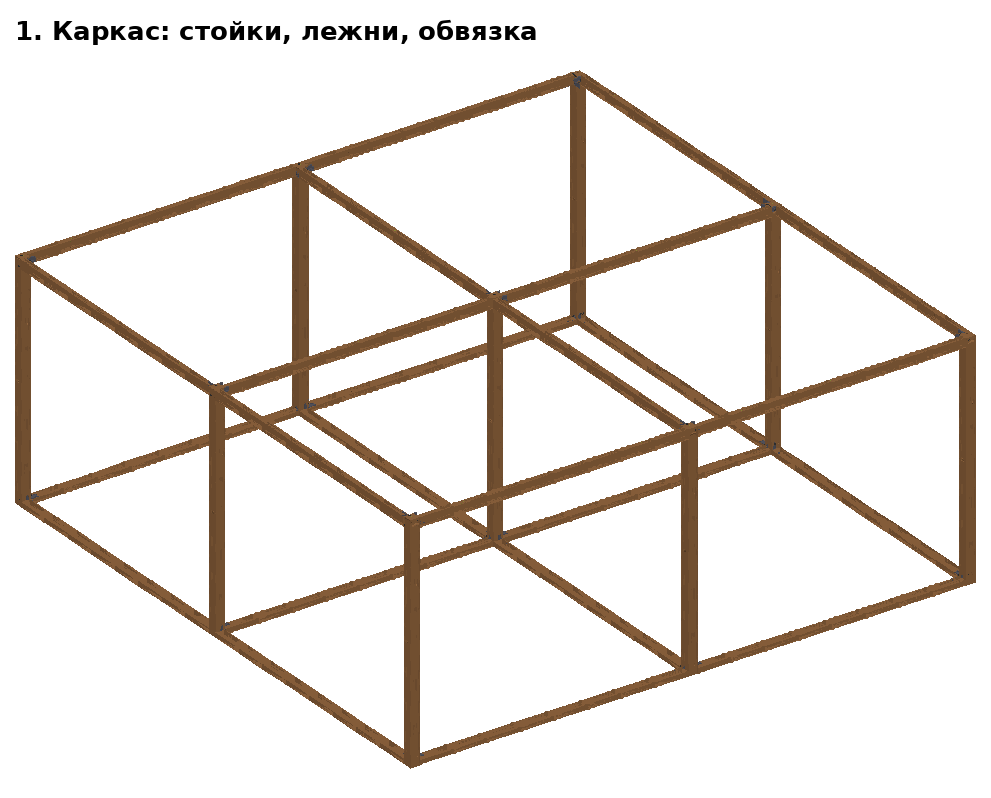
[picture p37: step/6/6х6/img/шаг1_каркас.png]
Каркас


### 1. Разметка и лежни
* Площадка — ровная, без камней. Разложить лежни по плану (`СБОРКА.md`),
  уголками внутрь клеток. Под лежни — подкладки (плитка, обрезки доски),
  выровнять уровнем.

### 2. Стойки
* Начинать **с угла**. Стойка встаёт между концами двух лежней, метка «X»
  — вдоль конька. Болт М10×130 снаружи сквозь стойку в уголок лежня,
  барашек.
* Каждая следующая стойка — по плану. В середине стены и в центре один
  болт держит уголки двух лежней.
* Проверить **диагонали каждой клетки** — около 4525 мм.
* Забить колья (арматура Ø12, 1 м) в отверстия лежней по периметру.

### 3. Верхняя обвязка
* Со стремянки: обвязку — между верхами стоек, вровень с ними, болт
  М10×130 сквозь стойку в уголок на каждый конец.
* **Вдоль конька — уголками вниз, поперёк — перевернуть (уголками вверх).**
  Перепутать нельзя: иначе болт не попадёт в отверстие стойки.
* Пока нет пролётов, каркас «гуляет» — стойки придерживать.

### 4. Пролёты

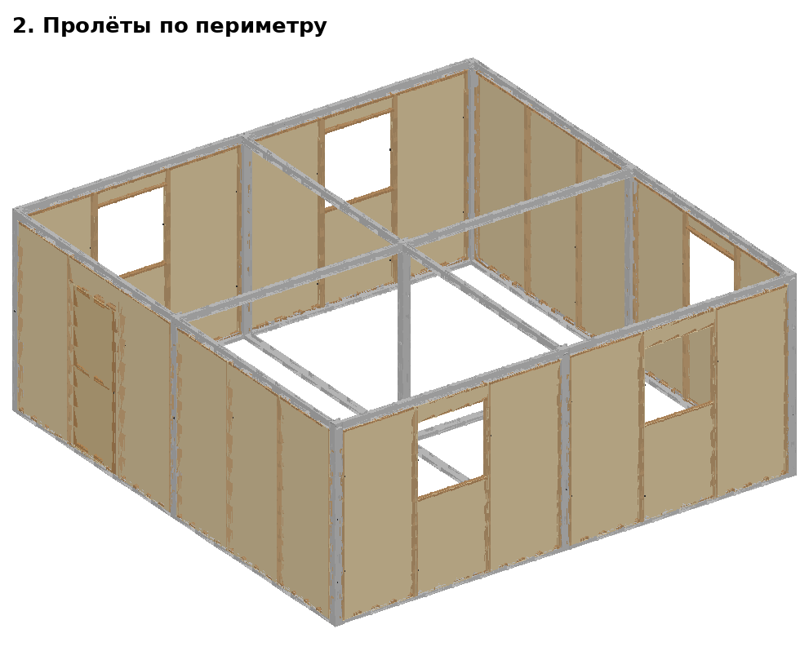
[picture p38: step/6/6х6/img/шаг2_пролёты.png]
Пролёты


* Вдвоём поставить пролёт на лежень между стойками, фанерой наружу
  (заводить можно снаружи или изнутри — до обвязки 10 мм зазор).
* **4 болта М10×150** снаружи сквозь стойки в крайние стойки пролёта,
  барашки изнутри. Высоты разные для разных мест — болт попадёт только в
  своё отверстие.
* **2 болта М10×80** изнутри снизу вверх сквозь верхнюю перемычку пролёта
  в футорки обвязки, ключом.
* После пролётов каркас становится жёстким (держит фанера).

### 5. Фермы

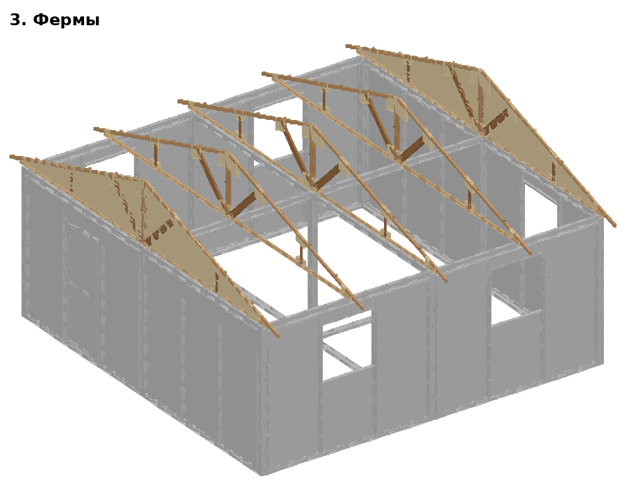
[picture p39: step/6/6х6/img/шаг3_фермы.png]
Фермы


* На земле сложить полуфермы парами стойка к стойке, болт М10×130 с
  барашком. Крайние фермы — **А + Б** фанерой наружу дома, остальные —
  две средние.
* Поднять ферму на обвязку (по человеку на стремянке с каждой стороны;
  большие — втроём). Крайние — над торцами дома, остальные — через 1,55 м
  (над каждой линией стоек и посередине между ними).
* **Пяты** — болт М10×80 сверху сквозь затяжку в футорку: на линии стоек —
  в верх стойки, между ними — в середину обвязки.
* Пока нет конька, ферма может завалиться вдоль дома — придерживать.

### 6. Конёк, прогоны, тент

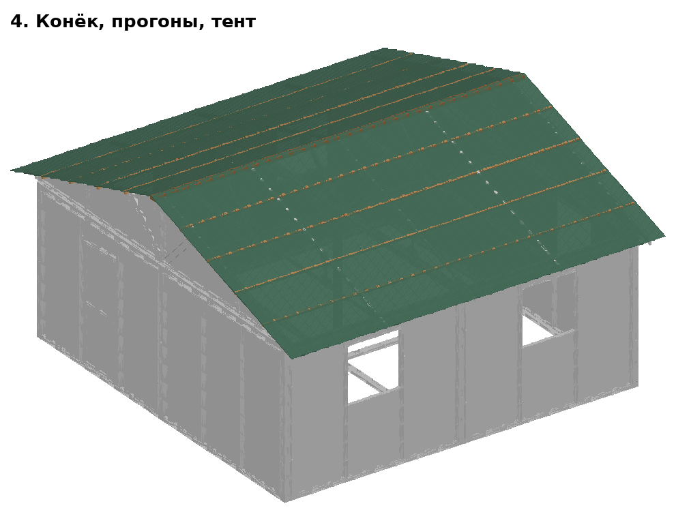
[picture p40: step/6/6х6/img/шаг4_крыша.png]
Крыша


* **Конёк** — сразу после ферм, кусками от фронтона: на верх ферм, бобышки
  по обе стороны фермы, стыки кусков — над фермами.
* **Прогоны** — в лапки стропил.
* **Тент** — через конёк, края привязать за люверсы к лежням/кольям.
  Поверх — **стяжные ремни** через всю крышу (по 2 на клетку вдоль конька),
  концы под лежни, затянуть храповиком. Ремни прижимают тент, конёк и
  прогоны — их ничем больше не крепят.

## Разборка

Обратный порядок: ремни, тент → прогоны, конёк → болты пят, фермы вниз,
разобрать на полуфермы → пролёты (сначала болты к обвязке, потом к
стойкам) → обвязка → стойки → колья → лежни. Болты и барашки — сразу в
ящик по длинам.

## Перевозка

| Деталь | Размер | Масса |
|---|---|---|
| Пролёт | 2991 × 2400 × 53 | 25–34 кг |
| (или щит) | 997 × 2400 × 53 | 8–17 кг |
| Стойка | 100×100×2560 | 13 кг |
| Лежень / обвязка | 50×100×2996 | 8–10 кг |
| Полуферма малая / большая | ≈ 1980×680 / 3530×1170 | 5,5 / 9 кг (ферма — 11 / 19 кг) |
| Конёк, прогоны | до 3500 | до 9 кг |

Пролёты 3 × 2,4 м — Газель с тентом или прицеп; если нет — щитами.

## Безопасность

* На тентовую крышу **не залезать**.
* В сильный ветер (> 15 м/с) — проверить ремни и колья; без кольев и
  ремней дом может сдвинуть ветром.
* Пролёты и фермы поднимать вдвоём, стремянки — на ровном.

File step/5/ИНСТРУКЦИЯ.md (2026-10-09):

# Дом 3×3, версия 5 — инструкция

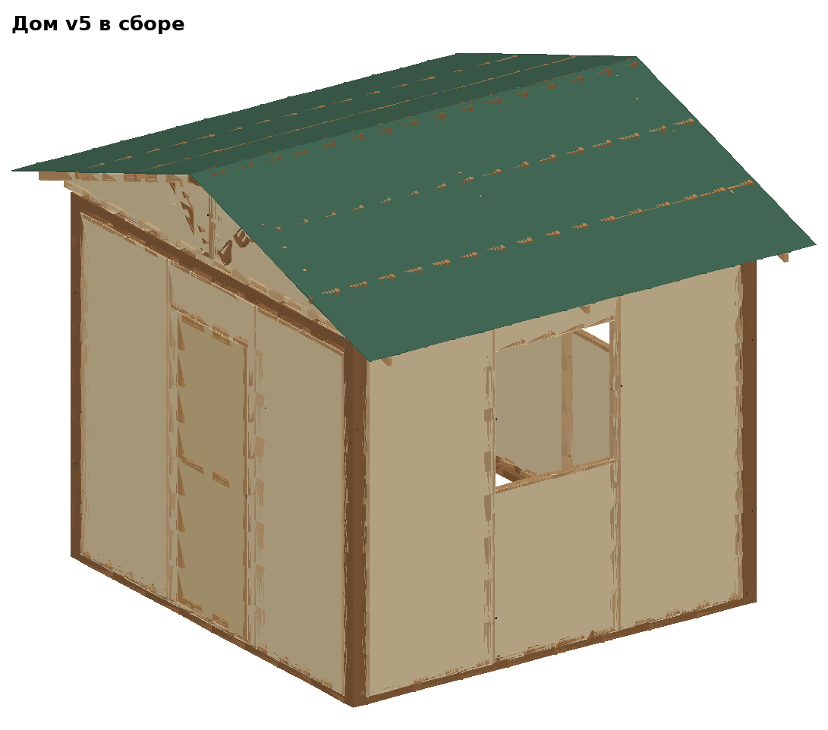
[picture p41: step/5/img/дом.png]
Дом v5


## Как собирается дом — коротко

1. В мастерской сколачиваем **щиты** (12 шт.) и **полуфермы** (6 шт.).
2. Щиты стягиваем болтами по три — получаем **пролёты** (4 стены).
3. На площадке собираем **каркас**: 4 угловые стойки, между ними внизу —
   лежни, вверху — верхняя обвязка. Всё на стальных уголках и болтах.
4. **Ставим пролёты** между стойками и притягиваем болтами.
5. Сверху — **фермы**, **конёк**, **прогоны**, **тент**.

Монтаж — **2 человека, ≈ 1,5 часа**. Весь крепёж — **болты М10** трёх длин
(80, 130, 150 мм) с гайками/барашками, всё из обычного строймага.
Инструмент на площадке: ключ на 17, стремянка, кувалда, уровень, рулетка.

Модель — `дом_v5_3х3.step`, отдельные блоки — `блоки/`, что купить —
[СПЕЦИФИКАЦИЯ.md](СПЕЦИФИКАЦИЯ.md).

## Словарик

| Слово | Что это |
|---|---|
| **Щит** | Рама 997 × 2400 из бруска 25×50, снаружи обшита водостойкой фанерой ФСФ 3 мм. Бывает глухой, с окном, с дверью. |
| **Пролёт** | Три щита, стянутые болтами, — готовая стена 2991 × 2400. |
| **Каркас** | Скелет дома: 4 угловые стойки + лежни внизу + верхняя обвязка вверху. Между стойками — проёмы под пролёты. |
| **Угловая стойка** | Брус 100×100 длиной 2560, стоит в каждом углу дома. |
| **Лежень** | Брус 50×100 длиной 2996, лежит на земле между двумя стойками. На него встаёт пролёт. |
| **Верхняя обвязка** | Такой же брус 50×100×2996, но на ребро и наверху — между верхами стоек. На неё встают фермы. Карнизная — над свесами крыши (стены A и C), фронтонная — под треугольниками крыши (B и D). |
| **Уголок** | Стальной крепёжный уголок 90×90×40 (продаётся в строймаге). Одной полкой прикручен к лежню или обвязке, другой — притягивается болтом к стойке. |
| **Ферма / полуферма** | Треугольная деревянная конструкция под крышу. Ферма = 2 полуфермы, стянутые болтом. Ферм три: две по краям (зашиты фанерой — треугольники фронтонов) и одна посередине. |
| **Конёк** | Брус 50×100 по верху ферм, вдоль всего дома. |
| **Прогон** | Рейка 25×50 поперёк ферм, на ней лежит тент. |
| **Футорка (врезная гайка)** | Втулка с резьбой М10, вкручивается в дерево; в неё вкручивается болт без гайки. Продаётся в отделе крепежа. |
| **Барашек** | Гайка с «ушками», затягивается рукой. |

```
             C (окно) — карнизная
      ■────────────────────■
      │                    │
  D   │                    │  B
(дверь)                    │ (окно)        D и B — фронтонные
      │                    │
      ■────────────────────■
             A (окно) — карнизная         ■ — угловые стойки
```

## Какой болт куда (все М10)

| Болт | Шт. | Где | Чем |
|---|---|---|---|
| М10×80 + гайка | 24 | щиты между собой в пролёте (**в мастерской**) | ключ |
| М10×130 + барашек | 8 | лежень к стойке (сквозь стойку в уголок) | рукой |
| М10×130 + барашек | 8 | верхняя обвязка к стойке (сквозь стойку в уголок) | рукой |
| М10×150 + барашек | 16 | пролёт к стойкам (сквозь стойку в край пролёта) | рукой |
| М10×80 | 8 | пролёт к верхней обвязке (изнутри снизу, в футорку) | ключ |
| М10×130 + барашек | 3 | две полуфермы в ферму | рукой |
| М10×80 | 6 | пяты ферм (в футорки стоек и карнизной обвязки) | ключ |

На каждый болт — увеличенная шайба под головку и под гайку.
**На площадке — 49 болтов**: 35 на барашках (рукой) и 14 в футорки (ключом).

---

## 1. Что везти на площадку

| Что | Шт. | Вес, кг | Размер, мм |
|---|---|---|---|
| Угловая стойка | 4 | 13 | 100×100×2560 |
| Лежень (с уголками) | 4 | 10 | 50×100×2996 |
| Верхняя обвязка карнизная (с уголками) | 2 | 8 | 50×100×2996 |
| Верхняя обвязка фронтонная (с уголками) | 2 | 8 | 50×100×2996 |
| Пролёт «окно» | 3 | 25 | 2991×2400×53 |
| Пролёт «дверь» | 1 | 34 | 2991×2400×53 |
| Полуферма средняя | 2 | 5,4 | ≈ 1980×680 |
| Полуферма фронтонная А / Б | 2 + 2 | 5,5 | ≈ 1980×680 |
| Конёк (с бобышками) | 1 | 9 | 50×100×3500 |
| Прогон | 4 | 2,2 | 25×50×3500 |
| Тент 4×5 м, 2 стяжных ремня, 8 кольев из арматуры | | | |
| Ящик: 49 болтов М10 (+10 %), 35 барашков, шайбы | | | |

Если пролёт 3 × 2,4 м не влезает в машину — везти щиты и стягивать в
пролёты на месте (+5 мин на пролёт).

**Размеры дома:** каркас 3200 × 3200, с крышей 3200 × 4060, высота до
конька 3,25 м, до потолка (низа ферм) 2,56 м. Вес ≈ 285 кг.

---

## 2. Мастерская

Правила:
* все соединения внутри щитов и полуферм — **клей ПВА D3 + саморезы**,
  они не разбираются;
* отверстия под болты — **сверло 11 мм**, под футорки — **14 мм**;
  одинаковые детали сверлить по шаблону (планка с отверстиями), чтобы
  подходили на любое место;
* на каждой детали — **маркировка** краской: что это, «верх», «наружу».

### 2.1 Щиты — 12 шт.

| Глухой ×8 | С окном ×3 | С дверью ×1 |
|---|---|---|
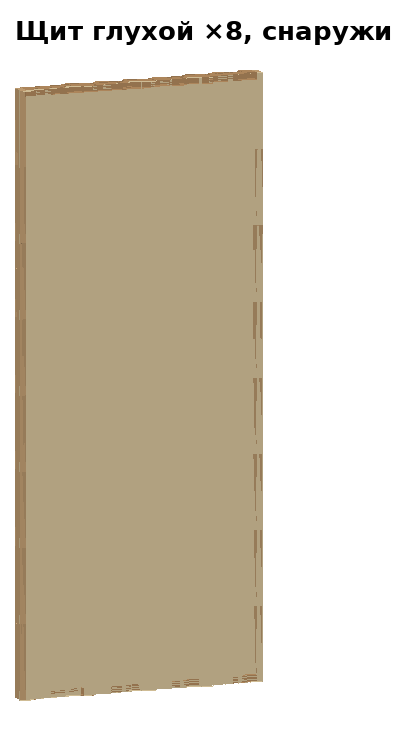
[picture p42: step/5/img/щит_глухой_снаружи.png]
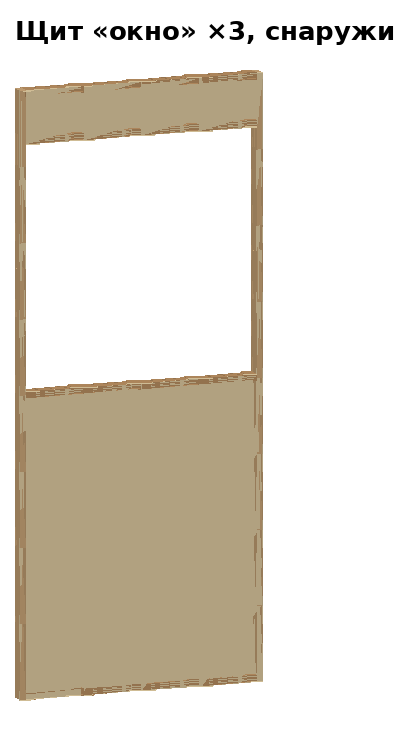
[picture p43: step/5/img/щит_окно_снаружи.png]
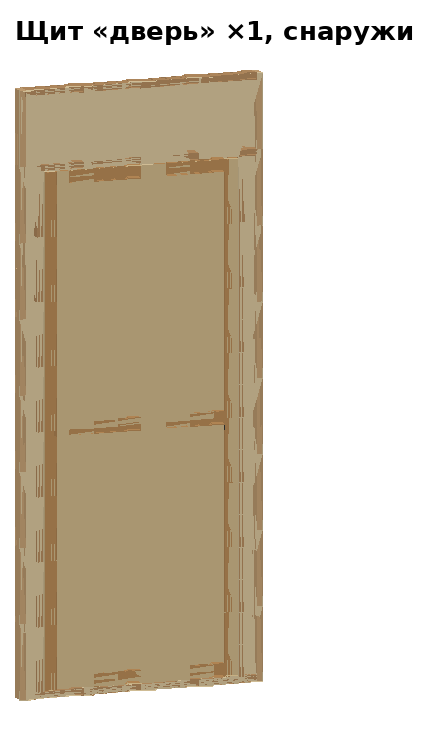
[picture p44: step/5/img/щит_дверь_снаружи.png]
|  |  |  |
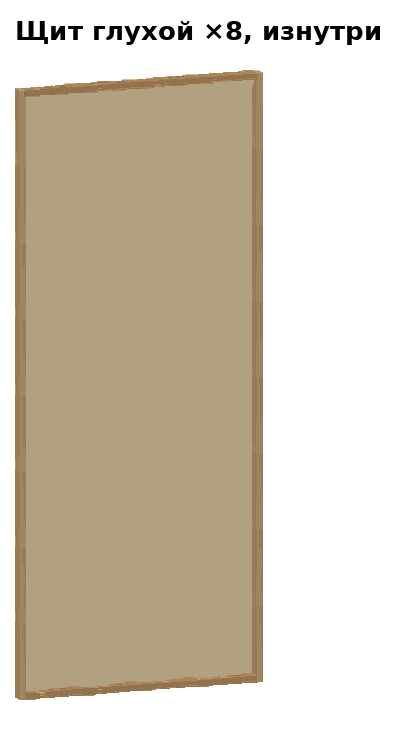
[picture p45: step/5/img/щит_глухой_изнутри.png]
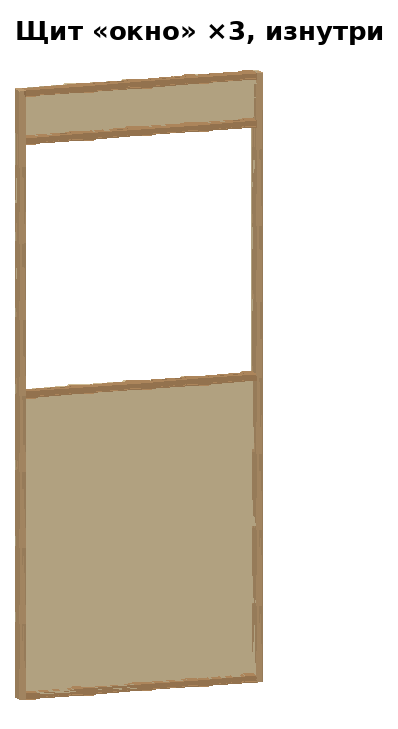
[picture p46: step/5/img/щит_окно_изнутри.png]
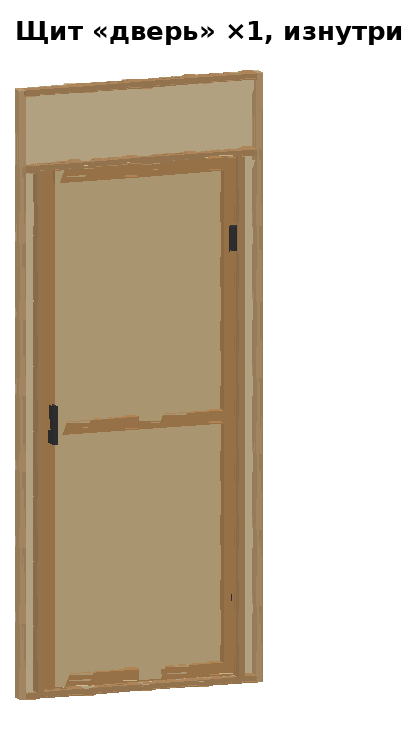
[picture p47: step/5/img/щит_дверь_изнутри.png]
|  |  |  |

1. Рама: 2 стойки 25×50×2400 + 2 перемычки 25×50×947 (низ и верх).
   Брусок стоит **на ребро** — рама толщиной 50.
2. Обшивка снаружи — фанера ФСФ 3 мм: один лист 1220×2440 обрезать до
   997×2400, без стыков. Клей + саморезы 3,5×25 через 150 мм.
3. Отверстия 11 мм поперёк стоек, посередине толщины:
   * во **всех** щитах в обеих стойках — на высоте **300, 1000, 1700**
     (стяжка щитов в пролёт);
   * в **глухих** ещё на **600, 700, 1800, 1900** (болты к угловым стойкам) и
     одно вертикальное отверстие в середине верхней перемычки (болт к
     верхней обвязке).

* **С окном:** ещё 2 перемычки 947 — низ на 1187,5 и 2187,5. Проём в фанере
  947 × 975.
* **С дверью:** 2 стойки 25×50×2050 (в 73,5 и 898,5 от левого края),
  перемычка 947 на высоте 2075. Проём 800 × 2050. Полотно 790 × 2040:
  рамка из бруска 25×50 + фанера 3 мм, 2 петли, ручка, шпингалет.

### 2.2 Пролёты — 4 шт.

| Пролёт с окном, снаружи | Пролёт с дверью, изнутри |
|---|---|
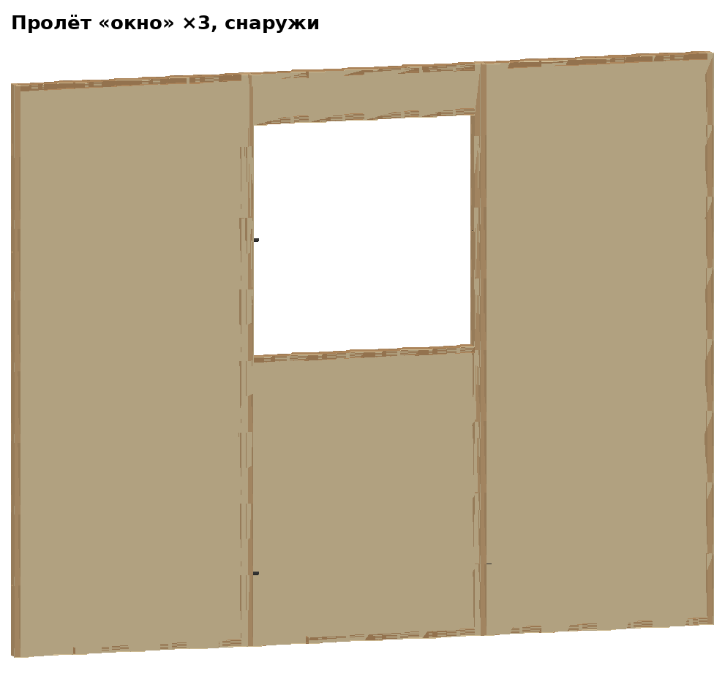
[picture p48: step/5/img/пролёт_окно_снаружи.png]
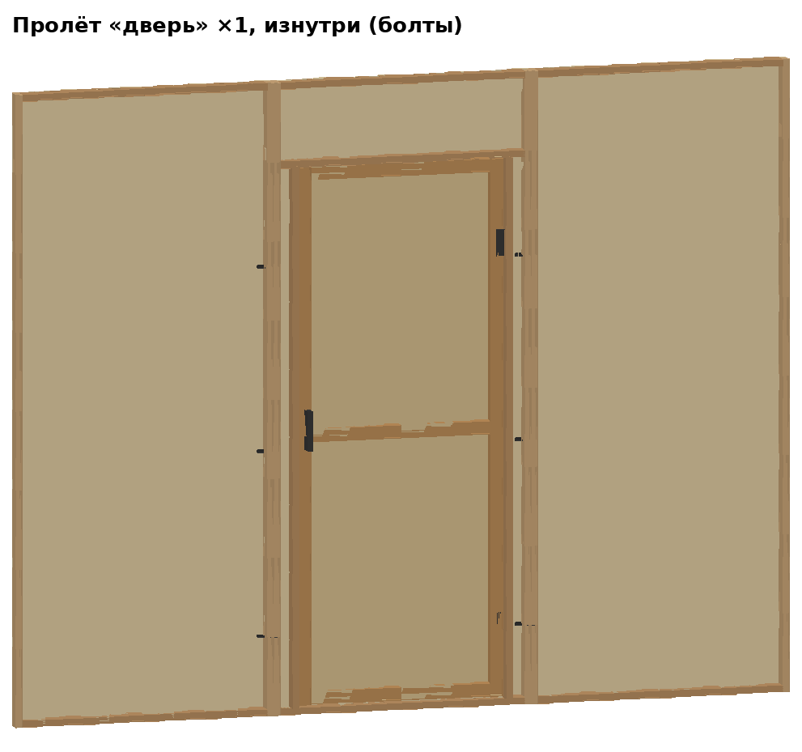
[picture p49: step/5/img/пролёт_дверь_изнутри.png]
|  |  |

Глухой + окно (или дверь) + глухой, стойки вплотную, **3 болта М10×80 с
гайкой на каждый стык**.

### 2.3 Детали каркаса

| Угловая стойка | Лежень | Верхняя обвязка |
|---|---|---|
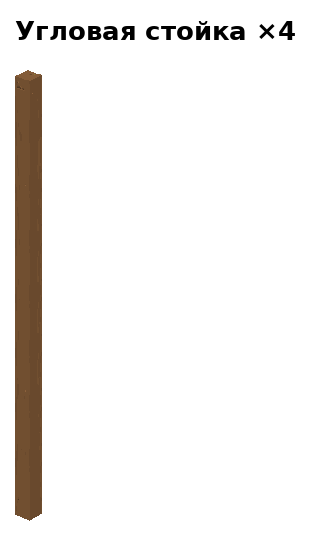
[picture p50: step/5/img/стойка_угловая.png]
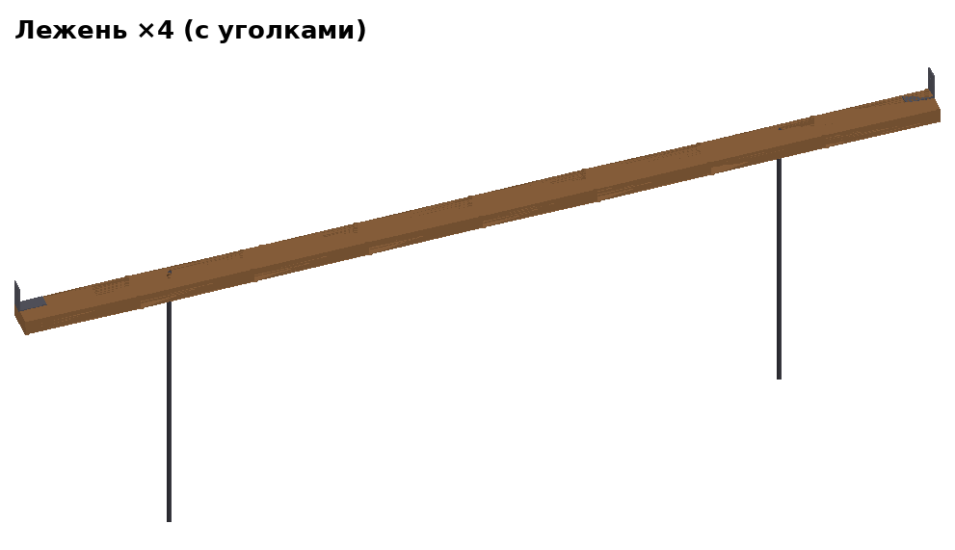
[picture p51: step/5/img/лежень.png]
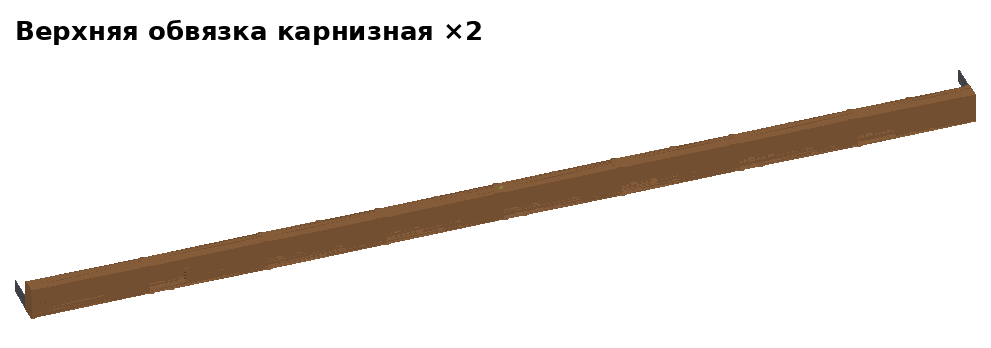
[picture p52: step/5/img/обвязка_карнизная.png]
|  |  |  |

**Угловая стойка 100×100×2560** (4 шт., одинаковые). Две грани смотрят на
улицу (наружные), две — в дом. Сквозные отверстия 11 мм в двух направлениях,
высота — от низа стойки:

| | Направление «А» | Направление «Б» |
|---|---|---|
| Болт уголка лежня (77 от наружной грани) | 80 | 115 |
| Болты пролёта (28 от наружной грани) | 650, 1850 | 750, 1950 |
| Болт уголка обвязки (75 от наружной грани) | 2485 | 2535 |

Сверху — отверстие 14 мм глубиной 36 в 25 мм от обеих наружных граней,
вкрутить футорку (под пяту фермы). Направления «А» и «Б» подписать на
стойке: перепутать нельзя — отверстия не совпадут с уголками.

**Лежни 50×100×2996** (4 шт., одинаковые), плашмя:
* на каждом конце сверху, у внутренней кромки, прикрутить **уголок
  90×90×40** (вертикальная полка — вровень с торцом лежня);
* 2 отверстия 14 мм под колья — в 500 мм от концов, в 77 мм от наружной
  кромки.

**Верхняя обвязка 50×100×2996** (4 шт.), на ребро:
* на концах на внутренней грани — **уголки 90×90×40** (вертикальная полка
  вровень с торцом): на левом конце — внизу, на правом — вверху;
* снизу 2 футорки (в 501 и 2495 мм от левого конца, в 28 мм от наружной
  грани) — под болты пролёта;
* у **карнизных** ещё футорка сверху посередине (1498 от конца, 25 от
  наружной грани) — под пяту средней фермы.

### 2.4 Полуфермы — 6 шт.

| Средняя ×2 | Фронтонная А ×2 | Фронтонная Б ×2 |
|---|---|---|
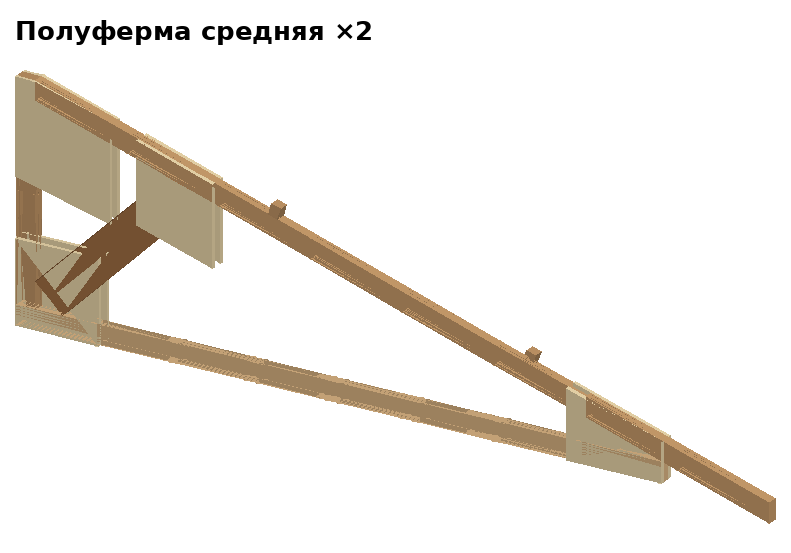
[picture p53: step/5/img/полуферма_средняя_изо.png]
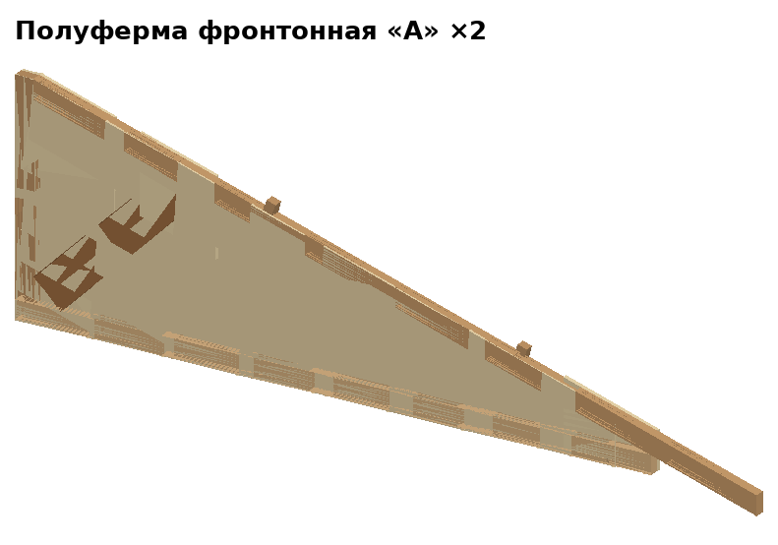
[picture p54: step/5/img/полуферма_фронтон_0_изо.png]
|  |  |  |



Брусок 25×50 на ребро, все детали в одной плоскости:

| Деталь | Длина | Как стоит |
|---|---|---|
| Затяжка (низ) | 1700 | горизонтально; отверстие 11 мм сверху вниз в 1575 от конька |
| Стойка | 576 | вертикально на коньковом конце затяжки; отверстие 11 мм поперёк посередине |
| Стропило | 2025 | от верха стойки вниз через конец затяжки, свес ≈ 380 за стену |
| Подкос | 538 | из угла «затяжка–стойка» под 45° до стропила |

* Все узлы — фанерные **косынки** 9 мм на клей и саморезы: у средней — с двух
  сторон, у фронтонных — с внутренней.
* Фронтонные снаружи зашиты фанерой 3 мм (треугольник до стены). А и Б —
  зеркальные: в ферме фронтона всегда пара А + Б, фанерой наружу.
* На стропиле — 2 лапки 25×25×30 под прогоны (на 650 и 1320 от конька).

**Конёк 50×100×3500**, плашмя. Снизу — 6 бобышек 25×50×100: по две на
каждую ферму, по бокам, просвет между ними 45 мм (на 175, 1750, 3325 от
конца конька). Конёк кладётся сверху на фермы, бобышки не дают ему сползти.

---

## 3. Монтаж на площадке

### Шаг 1. Лежни — 5 мин



Разложить 4 лежня квадратом, уголками внутрь, выровнять подкладками
(плитка, обрезки доски).

### Шаг 2. Угловые стойки — 15 мин



В каждый угол — стойку, между концами двух лежней. Два болта **М10×130**
снаружи сквозь стойку в уголки лежней, изнутри — барашки. Проверить
**диагонали** (около 4525 мм) и забить 8 кольев из арматуры в отверстия
лежней.

### Шаг 3. Верхняя обвязка — 12 мин



Со стремянки: обвязку — между верхами стоек, вровень с их верхом. Болт
**М10×130** снаружи сквозь стойку в уголок обвязки, барашек — по одному на
каждый конец. Карнизные — над стенами A и C, фронтонные — над B и D.
Каркас готов.

### Шаг 4–5. Пролёты — 20 мин

| Как ставится пролёт | Все пролёты на месте |
|---|---|
|  |  |

Каждый пролёт вдвоём:
1. Поставить на лежень между стойками, фанерой наружу (можно заводить и
   снаружи, и изнутри — до обвязки остаётся 10 мм).
2. **4 болта М10×150** снаружи сквозь стойки в крайние стойки пролёта,
   изнутри — барашки.
3. **2 болта М10×80** изнутри снизу вверх сквозь верхнюю перемычку пролёта
   в футорки верхней обвязки.

Пролёт с дверью — в стену D, с окнами — в A, B, C.

### Шаг 6. Фермы — 15 мин



1. На земле сложить полуфермы парами стойка к стойке и стянуть болтом
   М10×130 с барашком: фронтон D = А + Б, середина = 2 средние, фронтон
   B = Б + А (фанерой наружу).
2. Поднять ферму (≈ 12 кг) на обвязку и закрепить пяты болтами **М10×80**
   сквозь затяжку в футорки: у крайних ферм — в верх угловых стоек, у
   средней — в середину карнизных обвязок.

### Шаг 7. Конёк и прогоны — 7 мин



Конёк положить на верх ферм (бобышки по бокам ферм). 4 прогона — в лапки
на стропилах. Ничего не крепится — держит тент и ремни.

### Шаг 8. Тент — 10 мин



Тент — через конёк, края привязать к люверсам/лежням. Поверх — 2 стяжных
ремня через всю крышу, концы — под лежни A и C, затянуть храповиком.

| Этап | Мин |
|---|---|
| Раскладка | 10 |
| Лежни | 5 |
| Стойки, колья | 15 |
| Верхняя обвязка | 12 |
| Пролёты | 20 |
| Фермы | 15 |
| Конёк, прогоны | 7 |
| Тент, ремни | 10 |
| **Итого** | **≈ 95** |

## 4. Разборка — ≈ 45 мин

В обратном порядке: ремни, тент → прогоны, конёк → болты пят, фермы вниз,
разобрать на полуфермы → болты пролётов, пролёты → обвязка → колья,
стойки → лежни.

---

## 5. Что проверить при осмотре

* **Щит 997 мм** — чтобы пролёт (2991) встал между стойками (3000) с
  зазором 4,5 мм с каждой стороны; лежни и обвязка 2996 — зазор 2 мм.
* Каркас становится жёстким, когда стоят пролёты (фанера). До этого стойки
  держат уголки — их лучше придерживать, пока ставится обвязка.
* **Фанера ФСФ 3 мм** (водостойкая, лист 1220×2440) на щитах делает дом
  жёстким без диагоналей (~52 кг на весь дом). Покраска снаружи продлит
  срок службы, но не обязательна. Если 3 мм не найдётся — ФСФ 4 мм, все
  размеры те же. Тоньше 3 мм не стоит: саморезы продавливают лист, он выпучивается
  и пробивается. Если вместо фанеры ткань/баннер — в щиты нужны диагонали.
* **Тент** вместо жёсткой кровли — быстро и не течёт.
* **Пола нет**: при желании щиты пола кладутся на лежни изнутри.

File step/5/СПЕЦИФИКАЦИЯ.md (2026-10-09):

# Дом v5 — спецификация

Сгенерировано `tools/v5_house.py` по модели. Массы — сосна 500 кг/м³, фанера 600 кг/м³.

## Брус (раскрой)

| Сечение | Длина, мм | Шт. | Пог. м |
|---|---|---|---|
| 100×100 | 2560 | 4 | 10.24 |
| 25×50 | 3500 | 4 | 14.00 |
| 25×50 | 2400 | 24 | 57.60 |
| 25×50 | 2050 | 2 | 4.10 |
| 25×50 | 2040 | 2 | 4.08 |
| 25×50 | 2025 | 6 | 12.15 |
| 25×50 | 1700 | 6 | 10.20 |
| 25×50 | 947 | 31 | 29.36 |
| 25×50 | 690 | 3 | 2.07 |
| 25×50 | 576 | 6 | 3.46 |
| 25×50 | 538 | 6 | 3.23 |
| 25×50 | 100 | 6 | 0.60 |
| 25×50 | 50 | 12 | 0.60 |
| 50×100 | 3500 | 1 | 3.50 |
| 50×100 | 2996 | 8 | 23.97 |

**Итого:** 100×100 — 10.2 пог. м, 25×50 — 141.4 пог. м, 50×100 — 27.5 пог. м

Лапки прогонов 25×25×30 — из обрезков (строка «25×50 × 50»).

## Фанера

* ФСФ 3 мм 4/4 (водостойкая), лист 1220×2440 — 15 листов: 12 щитов 997×2400 (лист целиком, без стыков), дверное полотно, 2 листа на 4 половины фронтонов (≈1604×610, по 2 на лист). Если 3 мм нет — ФСФ 4 мм, размеры те же.
* 9 мм — косынки ферм, 32 шт. (≈ 1 лист 1220×2440).

## Фурнитура

| Позиция | Шт. |
|---|---|
| Арматура Ø12 А500С, пруток 1 м (кол) | 8 |
| Болт М10×130 (DIN 933, оцинк.) | 19 |
| Болт М10×150 (DIN 933, оцинк.) | 16 |
| Болт М10×80 (DIN 933, оцинк.) | 38 |
| Гайка М10 | 24 |
| Гайка врезная (футорка) М10 | 14 |
| Гайка-барашек М10 | 35 |
| Петля карточная 100 мм | 2 |
| Ремень стяжной с храповиком 6 м (через крышу к лежням) | 2 |
| Ручка-скоба дверная | 1 |
| Тент тарпаулин 4×5 м с люверсами | 1 |
| Уголок крепёжный усиленный 90×90×40 | 16 |
| Шайба М10 увеличенная (DIN 9021) | 132 |
| Шпингалет накладной | 1 |

Весь крепёж — одного диаметра М10, разной длины; ключ на 17 (или 16 — по стандарту болта). Взять запас 10%.

Для мастерской: клей ПВА D3, саморезы 3,5×25 (обшивка), 4×40 (косынки, рейки), 5×70 (узлы рам), антисептик; сверло по дереву Ø11 (под болты) и Ø14 (под футорки).

## Массы блоков

| Блок | Шт. | Масса, кг |
|---|---|---|
| лежень | 4 | 9.6 |
| стойка_угловая | 4 | 12.8 |
| обвязка_карнизная | 2 | 7.8 |
| пролёт_окно | 3 | 25.2 |
| обвязка_фронтонная | 2 | 7.8 |
| пролёт_дверь | 1 | 33.8 |
| щит_глухой | 8 | 8.5 |
| щит_окно | 3 | 8.0 |
| щит_дверь | 1 | 16.5 |
| полуферма_фронтон_0 | 2 | 5.5 |
| полуферма_фронтон_25 | 2 | 5.5 |
| полуферма_средняя | 2 | 5.4 |
| конёк | 1 | 9.1 |
| прогон | 4 | 2.2 |

**Масса дома без тента: ≈ 285 кг.**

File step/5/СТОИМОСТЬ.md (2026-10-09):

# Дом v5 — смета материалов

Цены — средние розничные по строймагам РФ (Леруа/Лемана ПРО, Петрович,
Сдвор, ОБИ, Максидом, Бауцентр, ВсеИнструменты), собраны в октябре 2026
по поисковой выдаче, из разных городов. Колонка «лесобаза» — тот же лес,
купленный на лесобазе. **≈** — оценка: точного товара в сетях не нашлось.

## Итог

| | Строймаг | Лес с лесобазы |
|---|---|---|
| Пиломатериалы | 22 300 | 12 700 |
| Фанера (ФСФ 3 мм ×15 + ФК 9 мм ×1) | 6 400 | 6 400 |
| Крепёж | 6 200 | 6 200 |
| Прочее (тент, ремни, саморезы, клей, антисептик, дверная фурнитура) | 10 100 | 10 100 |
| **Итого** | **≈ 45 000 ₽** | **≈ 35 500 ₽** |
| С запасом 10 % на брак и обрезки | ≈ 49 500 ₽ | ≈ 39 000 ₽ |

Не входит: покраска (по желанию), подкладки под лежни,
инструмент, доставка.

## Позиции

| Позиция | Кол-во | Цена, ₽ | Сумма, ₽ | Лесобаза, ₽ |
|---|---|---|---|---|
| Брусок 25×50×3000 сухой строганый | 46 шт | ≈ 250 | 11 500 | 120 → 5 520 |
| Брусок 25×50×4000 (прогоны) | 4 шт | ≈ 333 | 1 332 | 143 → 572 |
| Брус 100×100×3000 (стойки) | 4 шт | 1 180 | 4 720 | 963 → 3 852 |
| Доска 50×100×6000 (лежни, обвязка, конёк) | 5 шт | 955 | 4 775 | ≈ 560 → 2 800 |
| Фанера ФСФ 3 мм 1220×2440, 4/4 | 15 листов | ≈ 370 | 5 550 | |
| Фанера ФК 9 мм 1525×1525 (косынки) | 1 лист | 885 | 885 | |
| Болт М10×80 DIN 933 | 42 | 28 | 1 176 | |
| Болт М10×130 | 21 | 57 | 1 197 | |
| Болт М10×150 | 18 | 54 | 972 | |
| Гайка М10 | 26 | 6,6 | 172 | |
| Гайка-барашек М10 | 39 | 17 | 663 | |
| Шайба М10 увеличенная DIN 9021 | 145 | 4,6 | 667 | |
| Футорка М10 вкручиваемая | 16 | ≈ 35 | 560 | |
| Уголок усиленный KUU 90×90×40 | 18 | 46 | 828 | |
| Арматура Ø12 (8 кольев по 1 м) | 8 м | 80 | 640 | |
| Ремень стяжной с храповиком 6 м | 2 | 510 | 1 020 | |
| Тент тарпаулин 4×5 м, 180 г/м² | 1 | 1 930 | 1 930 | |
| Петля карточная 100 мм | 2 | 160 | 320 | |
| Ручка-скоба | 1 | 140 | 140 | |
| Шпингалет накладной | 1 | 93 | 93 | |
| Саморезы 3,5×25 | 2 кг | 320 | 640 | |
| Саморезы 4×40 | 2 уп. × 200 | 240 | 480 | |
| Саморезы 5×70 | 2 уп. × 200 | 420 | 840 | |
| Клей ПВА D3 (Kleiberit 303) | 3 × 0,5 кг | 760 | 2 280 | |
| Антисептик Сенеж 5 л (брус) | 2 | 850 | 1 700 | |

Количество в магазинных размерах — по раскрою из модели с запасом на пропил:
брусок 25×50 — 46 шт по 3 м + 4 по 4 м; доска 50×100 — 5 шт по 6 м (по две
детали 2996 с одной доски + конёк); брус 100×100 — 4 шт по 3 м
(дешевле: 2 шт по 6 м у Петровича, ≈ 1 700 за штуку). Метизы — +10 %.

## Что важно знать

* **Фанера — ФСФ 3 мм 1220×2440** (водостойкая): щит 997×2400 выходит из
  одного листа, без стыков и лишних перемычек. В сетях её почти нет — берут
  на фанерных базах: сорт 4/4 — 350–390 ₽, 3/4 шлифованная — 720–810 ₽.
  Если 3 мм не найдётся — **ФСФ 4 мм** (4/4 ≈ 500–690 ₽, +2–4 тыс. на дом),
  все размеры те же. ФК 3 мм в сетях продаётся только 1525×1525 — она
  потребовала бы стыков и боится дождя.
* Брусок 25×50 **сухой строганый** в сетях почти не продаётся — цена по
  аналогам (20×45 и 30×50 у Петровича/Сдвора). Нестроганый дешевле
  (≈ 145 в сети), но кривее — щиты будут неровными.
* Пиломатериалы в разных сетях отличаются в 1,5–2 раза (Лемана дороже,
  Петрович и Сдвор дешевле). Больше всего экономит лес с лесобазы.

## Источники

Пиломатериалы: [Петрович — сухой брусок](https://petrovich.ru/catalog/160888532/suhoy-brusok/),
[Сдвор — брусок сухой](https://sdvor.com/surgut/category/brusok-suhoj-5776),
[Лемана — рейки](https://lemanapro.ru/catalogue/reyki/),
[Карет-Строй24](https://karet-stroy24.ru/catalog/pilomaterialy/bruski/bruski-strogannye/brusok-sukhoy-strogannyy-25kh50kh3000-mm-khvoya-sort-av/),
[Стройпилторг](https://stroypilomaterialy.ru/brusok-strogannyj-25-50-3000.php),
[ЭКО 25×50×4000](https://ecowood27.ru/katalog/bruski-i-ryeyki/yel-bruski-i-reyki/brusok-25kh50kh4000-mm-el-prof-ant/),
[Лемана брус 100×100](https://kursk.lemanapro.ru/product/brus-nestroganyy-100x100x3000-mm-hvoya-82017667/),
[ОБИ брус 100×100](https://obi.ru/products/brus-konstrukcionnyj-100h100h3000-mm-sort-av-hvoja-5729295),
[НИКС брус 100×100](https://npfniks.ru/brus_strogannyj_suhoj_100_100_3000.php),
[Петрович брус](https://petrovich.ru/catalog/1293/),
[Лемана доска 50×100×6000](https://lemanapro.ru/product/doska-nestroganaya-50x100x6000-mm-hvoya-fgis-lk-81947449/),
[Сдвор доска 50×100×6000](https://sdvor.com/perm/product/doska-obreznaja-50h100h6000-mm-sort-1-3-hvoja-estestvennoj-vlazhnosti-217632),
[Петрович доска 100×50](https://ekaterinburg.petrovich.ru/catalog/95761838/doski-100-50/),
[доска 50×100×3000 сухая](https://pilomaterialy-moskva.ru/doska_suhaja_50-100-3000.php).

Фанера: [Сдвор ФК 3 мм](https://www.sdvor.com/moscow/product/fanera-fk-3-mm-1525h1525-mm-sort-44-neshlifovannaja-25123),
[Тимберия ФК 3 мм](https://spb.timberia.ru/catalog/fanera/fk/3-mm/1525kh1525-mm/),
[МосСтройЛес](https://www.mosstroyles.ru/catalog/fanera/fanera-tolshchina/3mm/),
[ФСФ 3 мм — Доски-Строй](https://doski-stroy.ru/fanera-3-fsf-44-1220x2440),
[ФСФ 3 мм — Пиломаркет](https://www.pilomarket.ru/products/fanera-fsf-3-mm-1220h2440/),
[ФСФ 3 мм — Фанера-Даром](https://www.fanera-darom.ru/fanera.php?fID=4041),
[ФСФ 4 мм — ЭДКМ](https://www.edkm.ru/fanera-4-mm-2440x1220/),
[ФСФ 4 мм — Свеза/Стройпровайдер](https://stroyprovider.ru/fanera/4mm_1220x2440mm_mn-25/),
[ФСФ 4 мм — Пиломаркет](https://www.pilomarket.ru/products/fanera-fsf-4-mm-1220h2440/),
[Сдвор ФК 9 мм](https://sdvor.com/surgut/product/fanera-fk-9-mm-1525h1525-mm-sort-44-neshlifovannaja-2373),
[Лемана ФК 10 мм](https://lemanapro.ru/product/fanera-10-mm-neshlifovannaya-1525x1525-mm-fk-sort-4-4-2325-m-12750175/).

Крепёж: [ОБИ болт М10×80](https://obi.ru/products/bolt-din-933-strojbat-shestigrannyj-m10h80-mm-2-sht-3046208),
[Бауцентр болт М10×80](https://baucenter.ru/product/bolt-s-shestigrannoy-golovkoy-otsinkovannyy-din933-m10kh80-mm-2-sht-ctg-29320-29321-32393-720006223/),
[ВсеИнструменты болты 130](https://www.vseinstrumenti.ru/tag-page/bolty-dlinoj-130-mm-20910/),
[ВсеИнструменты болты 150](https://www.vseinstrumenti.ru/tag-page/bolty-dlinoj-150-mm-20912/),
[ОБИ гайки М10](https://www.obi.ru/metricheskii-krepezh/gaika-ocinkovannaya-din-934-m10-50-shtuk/p/3057965),
[ОБИ барашек М10](https://obi.ru/products/gajka-din-315-strojbat-barashkovaja-m10-3047560),
[Лемана барашки](https://ufa.lemanapro.ru/product/gayka-barashkovaya-m10-din-315-stal-ocinkovannaya-8-sht-89404030/),
[Петрович шайбы](https://petrovich.ru/product/132377/),
[ВсеИнструменты шайбы DIN 9021](https://www.vseinstrumenti.ru/tag-page/shajby-m10-din-9021-17083/),
[ОБИ уголок KUU 90×90×40](https://obi.ru/products/ugolok-krepezhnyj-usilennyj-kuu-tech-krep-90h90h40-mm-3437480),
[Максидом уголки](https://www.maxidom.ru/catalog/ugolki/1001009648/),
[Петрович уголки](https://petrovich.ru/catalog/9956/metallicheskie-krepezhnye-ugolki-dlya-brusa/),
[ВсеИнструменты резьбовые втулки](https://www.vseinstrumenti.ru/tag-page/vtulka-rezbovaya-m10-1339583/).

Прочее: [Лемана арматура 12](https://lemanapro.ru/catalogue/armatura/metallicheskaya-12-mm/),
[ОБИ арматура](https://obi.ru/products/armatura-stalnaja-konstruktivnaja-d12-mm-a500s-2-92-m-4150983),
[Петрович ремни](https://moscow.petrovich.ru/catalog/21364/),
[ВсеИнструменты ремни](https://www.vseinstrumenti.ru/tag-page/styazhnye-remni-25-mm-17392/),
[Лемана тарпаулин](https://lemanapro.ru/catalogue/tenty-stroitelnye/tarpaulin/),
[Петрович петли](https://petrovich.ru/catalog/247045940/petli-dvernye-kartochnyj/),
[ВсеИнструменты ручки-скобы](https://www.vseinstrumenti.ru/category/ruchki-skoby-dlya-dverej-6664/),
[Петрович шпингалеты](https://petrovich.ru/catalog/1592/shpingalety/),
[Лемана саморезы 3,5×25](https://tver.lemanapro.ru/product/samorezy-po-derevu-i-gipsokartonu-35x25-mm-1-kg-18121505/),
[Лемана саморезы 4×40](https://lemanapro.ru/product/samorezy-universalnye-standers-4x40-mm-cvet-zheltyy-200-sht-15414142/),
[ВсеИнструменты саморезы 5×70](https://www.vseinstrumenti.ru/krepezh/metizy/samorezy/5-70/),
[ВсеИнструменты Kleiberit 303](https://www.vseinstrumenti.ru/product/klej-kleiberit-303-0-5-kg-klb0002-0-5-1922784/),
[ОБИ Неомид 440](https://www.obi.ru/antiseptiki-dlya-dereva/antiseptik-neomid-440eco-dlya-naruzhnykh-rabot-5-l/p/2926996),
[Сенеж Био 5 л](https://m-delivery.ru/product/antiseptik_senezh_bio_5_l_art13748/).

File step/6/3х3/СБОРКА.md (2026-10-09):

# Сборка дома 3х3

Дом 3х3

Каркас 3.2 × 3.2 м, высота до конька 3.24 м. Сетка 1 × 1 клеток. Общие правила и описание каждой детали — [../МОНТАЖ.md](../МОНТАЖ.md) и [../ДЕТАЛИ.md](../ДЕТАЛИ.md). Что купить и сколько стоит — [СПЕЦИФИКАЦИЯ_И_СМЕТА.md](СПЕЦИФИКАЦИЯ_И_СМЕТА.md).

## План

Вид сверху, север — сверху, конёк — вдоль длинной стороны (слева направо). ■ — стойка; О — пролёт с окном, Г — глухой, Д — с дверью, · — открытый проём.

```
■─────О─────■
│           │
Д           О
│           │
■─────О─────■
```

## Комплект

| Что | Шт. |
|---|---|
| Стойки | 4 |
| Лежни | 4 |
| Верхние обвязки | 4 (вдоль конька — 2, поперёк — 2, перевёрнутые) |
| Пролёты | 3 × «окно», 1 × «дверь» |
| Фермы (малые) | 3: 2 фронтонные (А+Б), 1 средних |
| Конёк / прогоны | 1 / 4 куск. |

## Порядок

1. **Лежни и стойки.** Разложить 4 лежней по плану (уголками внутрь клеток), выровнять подкладками. Ставить стойки от угла: каждая — между концами лежней, болты М10×130 сквозь стойку в уголки (8 шт.). Диагонали каждой клетки равны (≈ 4525). Колья — в лежни по периметру.

   

2. **Верхняя обвязка.** 2 обвязок вдоль конька — уголками вниз; 2 поперёк — перевернуть (уголками вверх). Болт М10×130 сквозь стойку на каждый конец (8 шт.; в середине стены и в центре один болт держит два уголка).
3. **Пролёты** (3 × «окно», 1 × «дверь») — по плану: на лежень между стойками, 4 болта М10×150 сквозь стойки (барашки изнутри) + 2 болта М10×80 изнутри снизу в футорки обвязки.

   

4. **Фермы** (3 шт.): пары полуферм на земле, болт М10×130 с барашком. Крайние — над торцами (фанерой наружу), остальные через 1,55 м. Пяты — болтами М10×80 в футорки: на линиях стоек — в верх стоек, между ними — в середину обвязок.

   

5. **Конёк** (1 куск.) на верх ферм — бобышками по бокам; **прогоны** (4 куск.) — в лапки стропил; **тент** через конёк, края к люверсам/лежням; **ремни** (2 шт.) через крышу под лежни.

   

## Болты на площадке

| Болт | Где | Шт. |
|---|---|---|
| М10×130 | уголки обвязок (верх стоек) | 8 |
| М10×130 | фермы | 3 |
| М10×80 | фермы | 6 |
| М10×130 | уголки лежней (низ стоек) | 8 |
| М10×150 | пролёты к стойкам и обвязке | 16 |
| М10×80 | пролёты к стойкам и обвязке | 8 |
| | **всего** | **49** |

## Время (2 человека, оценка)

| Этап | Мин |
|---|---|
| Раскладка, разметка | 10 |
| Лежни | 12 |
| Стойки (+ колья) | 17 |
| Верхняя обвязка | 16 |
| Пролёты | 24 |
| Фермы | 15 |
| Конёк, прогоны | 6 |
| Тент, ремни | 13 |
| **Итого** | **≈ 113 (1.9 ч)** |

Время — оценка по нормам на операцию, вживую не проверено. Втроём — примерно на треть быстрее.

## Разборка

Обратный порядок: ремни, тент → прогоны, конёк → фермы (разобрать на полуфермы) → пролёты → обвязка → стойки → колья, лежни.

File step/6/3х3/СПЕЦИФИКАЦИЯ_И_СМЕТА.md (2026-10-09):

# Дом 3х3 — спецификация и смета

Габарит каркаса 3.2 × 3.2 м, высота до конька 3.24 м. Сгенерировано `tools/grid_house.py`. Цены — средние по строймагам РФ, октябрь 2026 (см. `step/5/СТОИМОСТЬ.md`), ≈ — оценка.

## Блоки

| Блок | Шт. |
|---|---|
| стойка | 4 |
| лежень | 4 |
| обвязка | 4 |
| пролёт окно | 3 |
| пролёт дверь | 1 |
| ферма | 3 |
| конёк | 1 |
| прогон | 4 |

## Смета

| Позиция | Кол-во | Цена, ₽ | Сумма, ₽ |
|---|---|---|---|
| Брус/брусок 25×50×3000 | 46 шт | ≈ 250 | 11 500 |
| Брус/брусок 25×50×4000 | 4 шт | ≈ 333 | 1 332 |
| Брус/брусок 50×100×6000 | 5 шт | 955 | 4 775 |
| Брус/брусок 100×100×3000 | 4 шт | 1180 | 4 720 |
| Фанера ФСФ 3 мм 1220×2440 | 15 листов | ≈ 370 | 5 550 |
| Фанера ФК 9 мм 1525×1525 (косынки) | 1 | 885 | 885 |
| Арматура Ø12 (кол 1 м) | 8 м | 80 | 640 |
| Болт М10×130 | 21 шт | 57 | 1 197 |
| Болт М10×150 | 18 шт | 54 | 972 |
| Болт М10×80 | 42 шт | 28 | 1 176 |
| Гайка М10 | 27 шт | 6.6 | 178 |
| Гайка врезная (футорка) М10 | 31 шт | 35 | 1 085 |
| Гайка-барашек М10 | 39 шт | 17 | 663 |
| Петля карточная 100 мм | 2 шт | 160 | 320 |
| Ремень стяжной с храповиком 6 м | 2 шт | 510 | 1 020 |
| Ручка-скоба дверная | 1 шт | 140 | 140 |
| Тент тарпаулин ≥ 4×5 м | 1 | ≈ 1 930 | 1 930 |
| Уголок крепёжный усиленный KUU 90×90×40 | 16 шт | 46 | 736 |
| Шайба М10 увеличенная | 146 шт | 4.6 | 672 |
| Шпингалет накладной | 1 шт | 93 | 93 |
| Саморезы, клей D3, антисептик | | ≈ | 6 081 |

| Группа | ₽ |
|---|---|
| Пиломатериалы | 22 327 |
| Фанера | 6 435 |
| Прочее | 10 224 |
| Крепёж | 6 679 |
| **Итого** | **≈ 45 665** |
| С запасом 10 % | ≈ 50 231 |

Метизы — с запасом 10 %. Пиломатериал — в магазинных длинах, раскрой из модели с пропилом 4 мм.

## Раскрой

| Сечение | Длина, мм | Шт. |
|---|---|---|
| 100×100 | 2560 | 4 |
| 25×50 | 3500 | 4 |
| 25×50 | 2400 | 24 |
| 25×50 | 2050 | 2 |
| 25×50 | 2040 | 2 |
| 25×50 | 2025 | 6 |
| 25×50 | 1700 | 6 |
| 25×50 | 947 | 31 |
| 25×50 | 690 | 3 |
| 25×50 | 576 | 6 |
| 25×50 | 538 | 6 |
| 25×50 | 100 | 6 |
| 25×50 | 50 | 12 |
| 50×100 | 3500 | 1 |
| 50×100 | 2996 | 8 |

Масса без тента ≈ 285 кг.

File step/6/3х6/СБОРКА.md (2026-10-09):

# Сборка дома 3х6

Дом 3х6

Каркас 6.3 × 3.2 м, высота до конька 3.24 м. Сетка 2 × 1 клеток. Общие правила и описание каждой детали — [../МОНТАЖ.md](../МОНТАЖ.md) и [../ДЕТАЛИ.md](../ДЕТАЛИ.md). Что купить и сколько стоит — [СПЕЦИФИКАЦИЯ_И_СМЕТА.md](СПЕЦИФИКАЦИЯ_И_СМЕТА.md).

## План

Вид сверху, север — сверху, конёк — вдоль длинной стороны (слева направо). ■ — стойка; О — пролёт с окном, Г — глухой, Д — с дверью, · — открытый проём.

```
■─────О─────■─────Г─────■
│           │           │
Д           ·           О
│           │           │
■─────О─────■─────О─────■
```

## Комплект

| Что | Шт. |
|---|---|
| Стойки | 6 |
| Лежни | 7 |
| Верхние обвязки | 7 (вдоль конька — 4, поперёк — 3, перевёрнутые) |
| Пролёты | 4 × «окно», 1 × «глухой», 1 × «дверь» |
| Фермы (малые) | 5: 2 фронтонные (А+Б), 3 средних |
| Конёк / прогоны | 2 / 8 куск. |

## Порядок

1. **Лежни и стойки.** Разложить 7 лежней по плану (уголками внутрь клеток), выровнять подкладками. Ставить стойки от угла: каждая — между концами лежней, болты М10×130 сквозь стойку в уголки (12 шт.). Диагонали каждой клетки равны (≈ 4525). Колья — в лежни по периметру.

   

2. **Верхняя обвязка.** 4 обвязок вдоль конька — уголками вниз; 3 поперёк — перевернуть (уголками вверх). Болт М10×130 сквозь стойку на каждый конец (12 шт.; в середине стены и в центре один болт держит два уголка).
3. **Пролёты** (4 × «окно», 1 × «глухой», 1 × «дверь») — по плану: на лежень между стойками, 4 болта М10×150 сквозь стойки (барашки изнутри) + 2 болта М10×80 изнутри снизу в футорки обвязки.

   

4. **Фермы** (5 шт.): пары полуферм на земле, болт М10×130 с барашком. Крайние — над торцами (фанерой наружу), остальные через 1,55 м. Пяты — болтами М10×80 в футорки: на линиях стоек — в верх стоек, между ними — в середину обвязок.

   

5. **Конёк** (2 куск.) на верх ферм — бобышками по бокам; **прогоны** (8 куск.) — в лапки стропил; **тент** через конёк, края к люверсам/лежням; **ремни** (4 шт.) через крышу под лежни.

   

## Болты на площадке

| Болт | Где | Шт. |
|---|---|---|
| М10×130 | уголки обвязок (верх стоек) | 12 |
| М10×130 | фермы | 5 |
| М10×80 | фермы | 10 |
| М10×130 | уголки лежней (низ стоек) | 12 |
| М10×150 | пролёты к стойкам и обвязке | 24 |
| М10×80 | пролёты к стойкам и обвязке | 12 |
| | **всего** | **75** |

## Время (2 человека, оценка)

| Этап | Мин |
|---|---|
| Раскладка, разметка | 10 |
| Лежни | 21 |
| Стойки (+ колья) | 23 |
| Верхняя обвязка | 28 |
| Пролёты | 36 |
| Фермы | 25 |
| Конёк, прогоны | 12 |
| Тент, ремни | 21 |
| **Итого** | **≈ 176 (2.9 ч)** |

Время — оценка по нормам на операцию, вживую не проверено. Втроём — примерно на треть быстрее.

## Разборка

Обратный порядок: ремни, тент → прогоны, конёк → фермы (разобрать на полуфермы) → пролёты → обвязка → стойки → колья, лежни.

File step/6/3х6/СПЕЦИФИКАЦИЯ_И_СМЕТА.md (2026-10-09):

# Дом 3х6 — спецификация и смета

Габарит каркаса 6.3 × 3.2 м, высота до конька 3.24 м. Сгенерировано `tools/grid_house.py`. Цены — средние по строймагам РФ, октябрь 2026 (см. `step/5/СТОИМОСТЬ.md`), ≈ — оценка.

## Блоки

| Блок | Шт. |
|---|---|
| стойка | 6 |
| лежень | 7 |
| обвязка | 7 |
| пролёт окно | 4 |
| пролёт глухой | 1 |
| пролёт дверь | 1 |
| ферма | 5 |
| конёк | 2 |
| прогон | 8 |

## Смета

| Позиция | Кол-во | Цена, ₽ | Сумма, ₽ |
|---|---|---|---|
| Брус/брусок 25×50×4000 | 59 шт | ≈ 333 | 19 647 |
| Брус/брусок 50×100×6000 | 9 шт | 955 | 8 595 |
| Брус/брусок 100×100×3000 | 6 шт | 1180 | 7 080 |
| Фанера ФСФ 3 мм 1220×2440 | 21 листов | ≈ 370 | 7 770 |
| Фанера ФК 9 мм 1525×1525 (косынки) | 2 | 885 | 1 770 |
| Арматура Ø12 (кол 1 м) | 12 м | 80 | 960 |
| Болт М10×130 | 32 шт | 57 | 1 824 |
| Болт М10×150 | 27 шт | 54 | 1 458 |
| Болт М10×80 | 64 шт | 28 | 1 792 |
| Гайка М10 | 40 шт | 6.6 | 264 |
| Гайка врезная (футорка) М10 | 53 шт | 35 | 1 855 |
| Гайка-барашек М10 | 59 шт | 17 | 1 003 |
| Петля карточная 100 мм | 2 шт | 160 | 320 |
| Ремень стяжной с храповиком 6 м | 4 шт | 510 | 2 040 |
| Ручка-скоба дверная | 1 шт | 140 | 140 |
| Тент тарпаулин ≥ 7×5 м | 1 | ≈ 3 378 | 3 378 |
| Уголок крепёжный усиленный KUU 90×90×40 | 28 шт | 46 | 1 288 |
| Шайба М10 увеличенная | 221 шт | 4.6 | 1 017 |
| Шпингалет накладной | 1 шт | 93 | 93 |
| Саморезы, клей D3, антисептик | | ≈ | 9 503 |

| Группа | ₽ |
|---|---|
| Пиломатериалы | 35 322 |
| Фанера | 9 540 |
| Прочее | 16 433 |
| Крепёж | 10 501 |
| **Итого** | **≈ 71 796** |
| С запасом 10 % | ≈ 78 975 |

Метизы — с запасом 10 %. Пиломатериал — в магазинных длинах, раскрой из модели с пропилом 4 мм.

## Раскрой

| Сечение | Длина, мм | Шт. |
|---|---|---|
| 100×100 | 2560 | 6 |
| 25×50 | 3300 | 8 |
| 25×50 | 2400 | 36 |
| 25×50 | 2050 | 2 |
| 25×50 | 2040 | 2 |
| 25×50 | 2025 | 10 |
| 25×50 | 1700 | 10 |
| 25×50 | 947 | 45 |
| 25×50 | 690 | 3 |
| 25×50 | 576 | 10 |
| 25×50 | 538 | 10 |
| 25×50 | 100 | 10 |
| 25×50 | 50 | 20 |
| 50×100 | 3300 | 2 |
| 50×100 | 2996 | 14 |

Масса без тента ≈ 451 кг.

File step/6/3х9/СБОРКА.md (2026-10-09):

# Сборка дома 3х9

Дом 3х9

Каркас 9.4 × 3.2 м, высота до конька 3.24 м. Сетка 3 × 1 клеток. Общие правила и описание каждой детали — [../МОНТАЖ.md](../МОНТАЖ.md) и [../ДЕТАЛИ.md](../ДЕТАЛИ.md). Что купить и сколько стоит — [СПЕЦИФИКАЦИЯ_И_СМЕТА.md](СПЕЦИФИКАЦИЯ_И_СМЕТА.md).

## План

Вид сверху, север — сверху, конёк — вдоль длинной стороны (слева направо). ■ — стойка; О — пролёт с окном, Г — глухой, Д — с дверью, · — открытый проём.

```
■─────Г─────■─────О─────■─────Г─────■
│           │           │           │
Д           ·           ·           О
│           │           │           │
■─────О─────■─────О─────■─────О─────■
```

## Комплект

| Что | Шт. |
|---|---|
| Стойки | 8 |
| Лежни | 10 |
| Верхние обвязки | 10 (вдоль конька — 6, поперёк — 4, перевёрнутые) |
| Пролёты | 5 × «окно», 2 × «глухой», 1 × «дверь» |
| Фермы (малые) | 7: 2 фронтонные (А+Б), 5 средних |
| Конёк / прогоны | 3 / 12 куск. |

## Порядок

1. **Лежни и стойки.** Разложить 10 лежней по плану (уголками внутрь клеток), выровнять подкладками. Ставить стойки от угла: каждая — между концами лежней, болты М10×130 сквозь стойку в уголки (16 шт.). Диагонали каждой клетки равны (≈ 4525). Колья — в лежни по периметру.

   

2. **Верхняя обвязка.** 6 обвязок вдоль конька — уголками вниз; 4 поперёк — перевернуть (уголками вверх). Болт М10×130 сквозь стойку на каждый конец (16 шт.; в середине стены и в центре один болт держит два уголка).
3. **Пролёты** (5 × «окно», 2 × «глухой», 1 × «дверь») — по плану: на лежень между стойками, 4 болта М10×150 сквозь стойки (барашки изнутри) + 2 болта М10×80 изнутри снизу в футорки обвязки.

   

4. **Фермы** (7 шт.): пары полуферм на земле, болт М10×130 с барашком. Крайние — над торцами (фанерой наружу), остальные через 1,55 м. Пяты — болтами М10×80 в футорки: на линиях стоек — в верх стоек, между ними — в середину обвязок.

   

5. **Конёк** (3 куск.) на верх ферм — бобышками по бокам; **прогоны** (12 куск.) — в лапки стропил; **тент** через конёк, края к люверсам/лежням; **ремни** (6 шт.) через крышу под лежни.

   

## Болты на площадке

| Болт | Где | Шт. |
|---|---|---|
| М10×130 | уголки обвязок (верх стоек) | 16 |
| М10×130 | фермы | 7 |
| М10×80 | фермы | 14 |
| М10×130 | уголки лежней (низ стоек) | 16 |
| М10×150 | пролёты к стойкам и обвязке | 32 |
| М10×80 | пролёты к стойкам и обвязке | 16 |
| | **всего** | **101** |

## Время (2 человека, оценка)

| Этап | Мин |
|---|---|
| Раскладка, разметка | 10 |
| Лежни | 30 |
| Стойки (+ колья) | 29 |
| Верхняя обвязка | 40 |
| Пролёты | 48 |
| Фермы | 35 |
| Конёк, прогоны | 18 |
| Тент, ремни | 29 |
| **Итого** | **≈ 239 (4.0 ч)** |

Время — оценка по нормам на операцию, вживую не проверено. Втроём — примерно на треть быстрее.

## Разборка

Обратный порядок: ремни, тент → прогоны, конёк → фермы (разобрать на полуфермы) → пролёты → обвязка → стойки → колья, лежни.

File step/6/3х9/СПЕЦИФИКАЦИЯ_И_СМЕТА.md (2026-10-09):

# Дом 3х9 — спецификация и смета

Габарит каркаса 9.4 × 3.2 м, высота до конька 3.24 м. Сгенерировано `tools/grid_house.py`. Цены — средние по строймагам РФ, октябрь 2026 (см. `step/5/СТОИМОСТЬ.md`), ≈ — оценка.

## Блоки

| Блок | Шт. |
|---|---|
| стойка | 8 |
| лежень | 10 |
| обвязка | 10 |
| пролёт окно | 5 |
| пролёт глухой | 2 |
| пролёт дверь | 1 |
| ферма | 7 |
| конёк | 3 |
| прогон | 12 |

## Смета

| Позиция | Кол-во | Цена, ₽ | Сумма, ₽ |
|---|---|---|---|
| Брус/брусок 25×50×4000 | 79 шт | ≈ 333 | 26 307 |
| Брус/брусок 50×100×6000 | 13 шт | 955 | 12 415 |
| Брус/брусок 100×100×3000 | 8 шт | 1180 | 9 440 |
| Фанера ФСФ 3 мм 1220×2440 | 27 листов | ≈ 370 | 9 990 |
| Фанера ФК 9 мм 1525×1525 (косынки) | 3 | 885 | 2 655 |
| Арматура Ø12 (кол 1 м) | 16 м | 80 | 1 280 |
| Болт М10×130 | 43 шт | 57 | 2 451 |
| Болт М10×150 | 36 шт | 54 | 1 944 |
| Болт М10×80 | 86 шт | 28 | 2 408 |
| Гайка М10 | 53 шт | 6.6 | 350 |
| Гайка врезная (футорка) М10 | 75 шт | 35 | 2 625 |
| Гайка-барашек М10 | 79 шт | 17 | 1 343 |
| Петля карточная 100 мм | 2 шт | 160 | 320 |
| Ремень стяжной с храповиком 6 м | 6 шт | 510 | 3 060 |
| Ручка-скоба дверная | 1 шт | 140 | 140 |
| Тент тарпаулин ≥ 10×5 м | 1 | ≈ 4 825 | 4 825 |
| Уголок крепёжный усиленный KUU 90×90×40 | 40 шт | 46 | 1 840 |
| Шайба М10 увеличенная | 295 шт | 4.6 | 1 357 |
| Шпингалет накладной | 1 шт | 93 | 93 |
| Саморезы, клей D3, антисептик | | ≈ | 12 924 |

| Группа | ₽ |
|---|---|
| Пиломатериалы | 48 162 |
| Фанера | 12 645 |
| Прочее | 22 642 |
| Крепёж | 14 318 |
| **Итого** | **≈ 97 767** |
| С запасом 10 % | ≈ 107 544 |

Метизы — с запасом 10 %. Пиломатериал — в магазинных длинах, раскрой из модели с пропилом 4 мм.

## Раскрой

| Сечение | Длина, мм | Шт. |
|---|---|---|
| 100×100 | 2560 | 8 |
| 25×50 | 3300 | 8 |
| 25×50 | 3100 | 4 |
| 25×50 | 2400 | 48 |
| 25×50 | 2050 | 2 |
| 25×50 | 2040 | 2 |
| 25×50 | 2025 | 14 |
| 25×50 | 1700 | 14 |
| 25×50 | 947 | 59 |
| 25×50 | 690 | 3 |
| 25×50 | 576 | 14 |
| 25×50 | 538 | 14 |
| 25×50 | 100 | 14 |
| 25×50 | 50 | 28 |
| 50×100 | 3300 | 2 |
| 50×100 | 3100 | 1 |
| 50×100 | 2996 | 20 |

Масса без тента ≈ 617 кг.

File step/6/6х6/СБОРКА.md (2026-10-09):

# Сборка дома 6х6

Дом 6х6

Каркас 6.3 × 6.3 м, высота до конька 3.73 м. Сетка 2 × 2 клеток. Общие правила и описание каждой детали — [../МОНТАЖ.md](../МОНТАЖ.md) и [../ДЕТАЛИ.md](../ДЕТАЛИ.md). Что купить и сколько стоит — [СПЕЦИФИКАЦИЯ_И_СМЕТА.md](СПЕЦИФИКАЦИЯ_И_СМЕТА.md).

## План

Вид сверху, север — сверху, конёк — вдоль длинной стороны (слева направо). ■ — стойка; О — пролёт с окном, Г — глухой, Д — с дверью, · — открытый проём.

```
■─────О─────■─────О─────■
│           │           │
Д           ·           Г
│           │           │
■─────·─────■─────·─────■
│           │           │
Г           ·           О
│           │           │
■─────О─────■─────О─────■
```

## Комплект

| Что | Шт. |
|---|---|
| Стойки | 9 |
| Лежни | 12 |
| Верхние обвязки | 12 (вдоль конька — 6, поперёк — 6, перевёрнутые) |
| Пролёты | 5 × «окно», 2 × «глухой», 1 × «дверь» |
| Фермы (большие) | 5: 2 фронтонные (А+Б), 3 средних |
| Конёк / прогоны | 2 / 16 куск. |

## Порядок

1. **Лежни и стойки.** Разложить 12 лежней по плану (уголками внутрь клеток), выровнять подкладками. Ставить стойки от угла: каждая — между концами лежней, болты М10×130 сквозь стойку в уголки (18 шт.). Диагонали каждой клетки равны (≈ 4525). Колья — в лежни по периметру.

   

2. **Верхняя обвязка.** 6 обвязок вдоль конька — уголками вниз; 6 поперёк — перевернуть (уголками вверх). Болт М10×130 сквозь стойку на каждый конец (18 шт.; в середине стены и в центре один болт держит два уголка).
3. **Пролёты** (5 × «окно», 2 × «глухой», 1 × «дверь») — по плану: на лежень между стойками, 4 болта М10×150 сквозь стойки (барашки изнутри) + 2 болта М10×80 изнутри снизу в футорки обвязки.

   

4. **Фермы** (5 шт.): пары полуферм на земле, болт М10×130 с барашком. Крайние — над торцами (фанерой наружу), остальные через 1,55 м. Пяты — болтами М10×80 в футорки: на линиях стоек — в верх стоек, между ними — в середину обвязок. Большие фермы поднимать втроём; средняя линия стоек держит их под коньком.

   

5. **Конёк** (2 куск.) на верх ферм — бобышками по бокам; **прогоны** (16 куск.) — в лапки стропил; **тент** через конёк, края к люверсам/лежням; **ремни** (4 шт.) через крышу под лежни.

   

## Болты на площадке

| Болт | Где | Шт. |
|---|---|---|
| М10×130 | уголки обвязок (верх стоек) | 18 |
| М10×130 | фермы | 5 |
| М10×80 | фермы | 10 |
| М10×130 | уголки лежней (низ стоек) | 18 |
| М10×150 | пролёты к стойкам и обвязке | 32 |
| М10×80 | пролёты к стойкам и обвязке | 16 |
| | **всего** | **99** |

## Время (2 человека, оценка)

| Этап | Мин |
|---|---|
| Раскладка, разметка | 10 |
| Лежни | 36 |
| Стойки (+ колья) | 32 |
| Верхняя обвязка | 48 |
| Пролёты | 48 |
| Фермы | 40 |
| Конёк, прогоны | 12 |
| Тент, ремни | 21 |
| **Итого** | **≈ 247 (4.1 ч)** |

Время — оценка по нормам на операцию, вживую не проверено. Втроём — примерно на треть быстрее.

## Разборка

Обратный порядок: ремни, тент → прогоны, конёк → фермы (разобрать на полуфермы) → пролёты → обвязка → стойки → колья, лежни.

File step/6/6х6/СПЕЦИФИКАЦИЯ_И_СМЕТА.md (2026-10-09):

# Дом 6х6 — спецификация и смета

Габарит каркаса 6.3 × 6.3 м, высота до конька 3.73 м. Сгенерировано `tools/grid_house.py`. Цены — средние по строймагам РФ, октябрь 2026 (см. `step/5/СТОИМОСТЬ.md`), ≈ — оценка.

## Блоки

| Блок | Шт. |
|---|---|
| стойка | 9 |
| лежень | 12 |
| обвязка | 12 |
| пролёт окно | 5 |
| пролёт глухой | 2 |
| пролёт дверь | 1 |
| ферма | 5 |
| конёк | 2 |
| прогон | 16 |

## Смета

| Позиция | Кол-во | Цена, ₽ | Сумма, ₽ |
|---|---|---|---|
| Брус/брусок 25×50×4000 | 94 шт | ≈ 333 | 31 302 |
| Брус/брусок 50×100×6000 | 14 шт | 955 | 13 370 |
| Брус/брусок 100×100×3000 | 9 шт | 1180 | 10 620 |
| Фанера ФСФ 3 мм 1220×2440 | 29 листов | ≈ 370 | 10 730 |
| Фанера ФК 9 мм 1525×1525 (косынки) | 3 | 885 | 2 655 |
| Арматура Ø12 (кол 1 м) | 16 м | 80 | 1 280 |
| Болт М10×130 | 46 шт | 57 | 2 622 |
| Болт М10×150 | 36 шт | 54 | 1 944 |
| Болт М10×80 | 82 шт | 28 | 2 296 |
| Гайка М10 | 53 шт | 6.6 | 350 |
| Гайка врезная (футорка) М10 | 90 шт | 35 | 3 150 |
| Гайка-барашек М10 | 81 шт | 17 | 1 377 |
| Петля карточная 100 мм | 2 шт | 160 | 320 |
| Ремень стяжной с храповиком 6 м | 4 шт | 510 | 2 040 |
| Ручка-скоба дверная | 1 шт | 140 | 140 |
| Тент тарпаулин ≥ 7×8 м | 1 | ≈ 5 404 | 5 404 |
| Уголок крепёжный усиленный KUU 90×90×40 | 48 шт | 46 | 2 208 |
| Шайба М10 увеличенная | 295 шт | 4.6 | 1 357 |
| Шпингалет накладной | 1 шт | 93 | 93 |
| Саморезы, клей D3, антисептик | | ≈ | 14 705 |

| Группа | ₽ |
|---|---|
| Пиломатериалы | 55 292 |
| Фанера | 13 385 |
| Прочее | 23 982 |
| Крепёж | 15 304 |
| **Итого** | **≈ 107 962** |
| С запасом 10 % | ≈ 118 759 |

Метизы — с запасом 10 %. Пиломатериал — в магазинных длинах, раскрой из модели с пропилом 4 мм.

## Раскрой

| Сечение | Длина, мм | Шт. |
|---|---|---|
| 100×100 | 2560 | 9 |
| 25×50 | 3651 | 10 |
| 25×50 | 3300 | 16 |
| 25×50 | 3250 | 10 |
| 25×50 | 2400 | 48 |
| 25×50 | 2050 | 2 |
| 25×50 | 2040 | 2 |
| 25×50 | 1068 | 10 |
| 25×50 | 1066 | 10 |
| 25×50 | 947 | 59 |
| 25×50 | 690 | 3 |
| 25×50 | 420 | 10 |
| 25×50 | 100 | 10 |
| 25×50 | 50 | 40 |
| 50×100 | 3300 | 2 |
| 50×100 | 2996 | 24 |

Масса без тента ≈ 686 кг.

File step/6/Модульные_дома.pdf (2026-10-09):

# Модульные игровые дома

Документация: детали, монтаж, сборка домов 3×3, 3×6, 3×9, 6×6,

## закупка


# Модульные игровые дома — документация

Сборно-разборные деревянные дома для ролевых игр. Один набор деталей — дома любого размера, кратного клетке 3,1 м. Детали делаются в мастерской один раз и не разбираются; на площадке всё соединяется болтами М10 (большинство — барашками, руками).


## Документы

Документ | Что внутри
ДЕТАЛИ.md | Мастерская: как сделать каждую деталь — щиты, пролёты, стойки, лежни, обвязки, полуфермы, конёк, прогоны
МОНТАЖ.md | Площадка: общие правила сборки любого дома, крепёж, инструмент, разборка, перевозка
ЗАКУПКА.md | Что купить, где, сколько стоит — сводка по всем домам
3х3/СБОРКА.md | Сборка дома 3×3 — план, комплект, порядок, болты, время
3х6/СБОРКА.md | Сборка дома 3×6
3х9/СБОРКА.md | Сборка дома 3×9
6х6/СБОРКА.md | Сборка дома 6×6
*/ СПЕЦИФИКАЦИЯ_И_СМЕТА.md | Раскрой, крепёж и смета конкретного дома
*/дом_*.step, блоки/ | 3D-модели (STEP) — открываются в Fusion 360, FreeCAD, SolidWorks

## Дома

Дом | Каркас, м | Высота до конька | Пролётов | Ферм | Масса | Смета* | Монтаж вдвоём**
3×3 | 3,2 × 3,2 | 3,24 | 4 | 3 малых | 285 кг | ≈ 46 тыс. ₽ | ≈ 1,9 ч
3×6 | 6,3 × 3,2 | 3,24 | 6 | 5 малых | 450 кг | ≈ 72 тыс. ₽ | ≈ 2,9 ч
3×9 | 9,4 × 3,2 | 3,24 | 8 | 7 малых | 620 кг | ≈ 98 тыс. ₽ | ≈ 4 ч
6×6 | 6,3 × 6,3 | 3,73 | 8 | 5 больших | 690 кг | ≈ 108 тыс. ₽ | ≈ 4,1 ч

* материалы, средние цены строймагов РФ (октябрь 2026), без запаса; с запасом 10 % — на 10 % больше. ** оценка, вживую не проверена; втроём — примерно на треть быстрее.

## Как устроена система

■────────■────────■
│ пролёт │ пролёт │ | ■ — стойка 100×100 в каждом узле сетки
│ | │ | │ | ─ — лежень внизу + обвязка вверху
■────────●────────■ | ● — внутренняя стойка
│ | │ | │ | пролёт — стена из 3 щитов
│ | │ | │
■────────■────────■ | шаг сетки 3100 = стойка 100 + проём 3000
1. Каркас. В каждом узле сетки — стойка, соседние клетки делят общие стойки. Между любыми двумя соседними стойками внизу — лежень, вверху — обвязка, оба на стальных уголках и болтах.
2. Стены. В проём каркаса по периметру ставится пролёт — три щита, стянутых болтами. Пролёты бывают глухие, с окном, с дверью и встают в любой проём. Внутренние проёмы
| открыты.
3. Крыша. Двускатная, конёк вдоль длинной стороны. Фермы (каждая из двух полуферм) стоят на обвязке через 1,55 м; сверху — конёк, прогоны и тент.
Дом шириной в 1 клетку (3×3, 3×6, 3×9 …) — малые полуфермы.
Шириной в 2 клетки (6×6, 6×9 …) — большие полуфермы, конёк держит средняя линия стоек (в зале — столб).

Стойки, лежни, обвязки, щиты, пролёты и полуфермы одинаковые для любого дома. Например, из двух комплектов 3×3 собирается 3×6: остаются лишними 2 стойки, лежень, обвязка, 2 пролёта и 2 фронтонные фермы, не хватает одной средней фермы. Конёк и прогоны у длинных домов режутся кусками по клетке (3300/3100 мм), у 3×3 — один кусок 3500.

## Словарик

Слово | Что это
Щит | Рама 997 × 2400 из бруска 25×50 на ребро, снаружи — фанера ФСФ 3 мм. Глухой, с окном, с дверью.
Пролёт | Три щита на болтах — стена 2991 × 2400 × 53 между двумя стойками.
Стойка | Брус 100×100×2560 в узле сетки. Все стойки одинаковые.
Лежень | Брус 50×100×2996 на земле между двумя стойками, на него ставится пролёт.
Обвязка | Брус 50×100×2996 на ребро между верхами двух стоек, на неё встают фермы. Одна деталь на все места; поперёк конька её ставят перевёрнутой.
Уголок | Стальной крепёжный уголок KUU 90×90×40 — держит лежень и обвязку на стойке.
Ферма / полуферма | Треугольник под крышу. Ферма = 2 полуфермы на одном болте. Крайние фермы (фронтонные) зашиты фанерой.
Конёк, прогон | Брус 50×100 по верху ферм и рейки 25×50 поперёк ферм — под тент.
Косынка | Фанерная накладка 9 мм на узле фермы (клей + саморезы).
Футорка | Врезная гайка М10 — втулка с резьбой, вкручивается в дерево.
Барашек | Гайка М10 с «ушками», крутится рукой.
Клетка | Квадрат сетки 3,1 × 3,1 м между четырьмя стойками.

## Модели и генератор

Всё — модели, раскрой, сметы, инструкции по сборке и картинки — генерируется скриптами из одной параметрической модели:

pip install build123d scipy pillow
python tools/grid_house.py 6х6 step/6/6х6 step/6/блоки | # STEP, смета, СБОРКА.md
python tools/grid_draw.py 6х6 step/6/6х6/img | # картинки дома
python tools/grid_draw.py детали step/6/img_детали | # картинки деталей

Новый размер — одна строка в CONFIGS (tools/grid_house.py): число клеток по X (вдоль конька, любое) и по Y (1 или 2) и что стоит в каждом проёме периметра. Модели проверены на пересечения деталей и на то, что каждый болт проходит через нужные детали с запасом под гайку.

# Детали — изготовление в мастерской

Все детали делаются один раз и не разбираются. Сколько каких деталей нужно для конкретного дома — в его СБОРКА.md и СПЕЦИФИКАЦИЯ_И_СМЕТА.md.

## Общие правила

Материалы: брусок 25×50 сухой строганый, брус 100×100, доска/брус 50×100, фанера ФСФ 3 мм 1220×2440 (обшивка) и ФК 9 мм (косынки).
Соединения внутри деталей — клей ПВА D3 + саморезы: узлы рам и ферм — 5×70, косынки и уголки — 4×40, фанера обшивки — 3,5×25 через 150 мм.
Отверстия под болты М10 — сверло 11 мм, под футорки — 14 мм. Одинаковые детали сверлить по кондуктору (шаблон из доски с просверленными отверстиями), иначе детали не будут подходить к любому месту.
Футорка М10 вкручивается шестигранником (или забивается — усовая).
Антисептик — на все деревянные детали до сборки, особенно лежни и торцы. Фанеру ФСФ можно покрасить фасадной краской — не обязательно.
Маркировка краской на каждой детали: тип, «верх», «наружу».

Размеры в мм. Высоты отверстий — от низа детали, если не сказано иное.

## 1. Щиты

Глухой | С окном | С дверью

Общее для всех щитов (997 × 2400 × 50 + фанера 3 мм):

1. Рама: 2 стойки 25×50×2400 + 2 перемычки 25×50×947 (низ и верх), брусок на ребро (толщина рамы 50). Углы — клей + 2 самореза 5×70.
2. Отверстия 11 мм поперёк обеих стоек, посередине толщины, на высоте 300, 1000, 1700 — стяжка щитов в пролёт.
3. Обшивка снаружи — лист ФСФ 3 мм 1220×2440, обрезанный до 997×2400, на клей и саморезы 3,5×25 через 150 мм. Фанера держит щит от перекоса — диагонали не нужны.

Глухой (идёт по краям каждого пролёта) — дополнительно:

в обеих стойках ещё отверстия на 400, 500, 600, 700, 1200, 1300, 1800, 1900 — болты к стойкам каркаса (используется 2 из 8, в зависимости от места пролёта — поэтому любой пролёт встаёт в любой проём);
в верхней перемычке посередине — вертикальное отверстие 11 мм (болт к обвязке).

С окном: ещё 2 перемычки 947 — низ на 1187,5 и 2187,5. Вырез в фанере 947 × 975 (проём от 1212,5 до 2187,5).

С дверью: 2 стойки 25×50×2050 (в 73,5 и 898,5 от левого края, от нижней перемычки), перемычка 947 на высоте 2075. Проём 800 × 2050, порог 25. Полотно 790 × 2040: рамка из бруска 25×50 плашмя (2 × 2040 + 3 × 690) + ФСФ 3 мм; 2 петли 100 мм на левую стойку, ручка-скоба, шпингалет.

## 2. Пролёты

Окно | Глухой | Дверь

Пролёт = глухой щит + средний щит + глухой щит, стойки вплотную:

Пролёт | Средний щит
«окно» | с окном
«глухой» | глухой
«дверь» | с дверью

На каждом стыке — 3 болта М10×80 с гайкой и шайбами (высота 300, 1000, 1700), всего 6 на пролёт. Готовый пролёт 2991 × 2400 × 53, масса 25–34 кг. Если пролёт не влезает в транспорт — везти щитами и стягивать на месте.

## 3. Стойка


Брус 100×100×2560, все стойки одинаковые — угловые, в середине стены и в центре. Стойки не поворачиваются: «X» — направление вдоль конька, «Y» — поперёк; стойку ставят меткой «X» вдоль конька.

Сквозные отверстия 11 мм. Каждое — парой, симметрично относительно середины стойки (на указанном расстоянии от одной грани и от противоположной):

Назначение | Направление X: высота / от грани | Направление Y: высота / от грани
Уголок лежня | 80 / 23 и 77 | 115 / 23 и 77
Пролёт, левый край | 650 и 1850 / 28 и 72 | 450 и 1250 / 28 и 72
Пролёт, правый край | 750 и 1950 / 28 и 72 | 550 и 1350 / 28 и 72
Уголок обвязки | 2485 / 25 и 75 | 2535 / 25 и 75

Итого 24 отверстия (12 в каждом направлении); разные высоты для X и Y — чтобы отверстия не пересекались внутри стойки. Сверлить по кондуктору: короб из досок, надеваемый на стойку, с отверстиями-направляющими.

Сверху по центру — отверстие 14 мм глубиной 36, футорка М10 (пята фермы).

## 4. Лежень


Брус 50×100×2996, кладётся плашмя. Все лежни одинаковые.

На обоих концах сверху — уголок KUU 90×90×40: вертикальная полка вровень с торцом лежня (смотрит на стойку), полка по ширине — от 57 до 97 мм от наружной кромки. Саморезы 4×40.
В вертикальной полке уголка нужны отверстия на высоте 30 и 65 мм над лежнем (у KUU отверстия есть; если не совпали — досверлить 11 мм). Лежень вдоль конька крепится через нижнее (30), поперёк — через верхнее (65): так все лежни одинаковые.
2 отверстия 14 мм под колья — в 498 мм от концов, в 77 мм от наружной кромки (используются у лежней по периметру).

## 5. Обвязка

Вдоль конька | Поперёк конька (перевёрнута)


Брус 50×100×2996 на ребро, одна деталь на все места.

На обоих концах на внутренней грани — уголок KUU 90×90×40: вертикальная полка вровень с торцом, по высоте — от 5 до 45 мм от нижней грани; отверстие уголка — на 25 мм от низа.

### 6 футорок М10: по три на нижней и верхней грани — в 501, 1498 и 2495 мм от конца, в

28 мм (крайние) и 25 мм (средняя) от наружной грани. Нижние — под болты пролёта, верхняя средняя — под пяту фермы.
Вдоль конька обвязка ставится уголками вниз. Поперёк конька — переворачивается (уголками вверх): уголки оказываются на высоте 75 мм от низа — как раз под отверстия «Y» в стойке, футорки меняются местами.

## 6. Полуфермы


Брусок 25×50 на ребро, все детали в одной плоскости. Узлы — фанерные косынки 9 мм на клей и саморезы 4×40: у средних полуферм — с двух сторон, у фронтонных — с внутренней. На стропиле — лапки 25×25×30 под прогоны.

### 6.1 Малые (дома шириной 3 м: 3×3, 3×6, 3×9)

Средняя | Фронтонная А | Фронтонная Б
Деталь | Длина | Как стоит
Затяжка | 1700 | горизонтально
Стойка | 576 | вертикально на коньковом конце затяжки
Стропило | 2025 | верх — вертикальный рез в стойку; низ — вертикальный рез, свес ≈ 380 за стену
Подкос | 538 | из угла затяжка/стойка под 45° до стропила

Отверстия 11 мм: в затяжке — вертикальные на 1550 и 1575 от конькового конца (пята на стойке / на обвязке); в стойке — поперёк посередине (болт пары).
Лапки — на 650 и 1320 от конька.

### 6.2 Большие (дома шириной 6 м: 6×6, 6×9)

Средняя | Фронтонная А | Фронтонная Б


Деталь | Длина | Как стоит
Затяжка | 3250 | горизонтально
Стойка | 1068 | вертикально на коньковом конце
Стропило | 3651 | как у малой, свес ≈ 380
Подкос | 1066 | из угла под 45° до стропила
Бабка | 420 | вертикальная распорка на 1900 от конька

Отверстия 11 мм в затяжке — на 3100 и 3125 от конькового конца; в стойке — поперёк посередине.
Лапки — на 700, 1400, 2100, 2800 от конька.

### Фронтонные А и Б

Крайние фермы дома зашиты снаружи фанерой ФСФ 3 мм (треугольник до наружной грани стены) — это фронтоны. А и Б — зеркальные: фанера на разных сторонах. В ферме фронтона всегда пара А + Б, фанерой наружу дома.

## 7. Конёк и прогоны

Конёк — брус 50×100 плашмя: у дома 3×3 — один кусок 3500, у длинных — кусками по клетке (крайние 3300, средние 3100), стыки — над фермами на линиях стоек.
Снизу у конька — бобышки 25×50×100 по обе стороны от каждой фермы (просвет 45 мм): конёк ложится на фермы и не сползает.

Прогоны — брусок 25×50 на ребро, такими же кусками; ложатся в лапки стропил. 2 на скат у малых ферм, 4 — у больших.

## 8. Кондукторы (сделать один раз)

Кондуктор | Для чего
Короб на стойку 100×100 | 24 отверстия стойки
Планка на стойку щита | отверстия 300/1000/1700 (+ 400…1900 у глухих)
Планка на обвязку | 6 футорок
Шаблон полуфермы на полу (обрезки, прибитые к щиту) | одинаковые полуфермы

# Монтаж — общие правила для любого дома

Порядок одинаковый для всех домов системы. Конкретный дом — план, сколько чего и сколько болтов — в его СБОРКА.md: 3×3 · 3×6 · 3×9 · 6×6.

## Люди и инструмент

2 человека (дом 6×6 и большие фермы — лучше 3).
Ключ на 17 (рожковый + накидной), стремянка 1,5–2 м (2 шт. для ферм), кувалда (колья), уровень, рулетка 5 м, шнур.
Барашки затягиваются рукой; ключ нужен только для болтов в футорки и гаек в пролётах.

## Крепёж — все болты М10

Болт | Где на площадке
М10×130 + барашек | уголки лежней и обвязок к стойкам (сквозь стойку); пара полуферм в ферму
М10×150 + барашек | пролёт к стойкам (сквозь стойку в крайнюю стойку пролёта)
М10×80 | пролёт к обвязке (изнутри снизу в футорку); пяты ферм (в футорку стойки или обвязки)

На каждый болт — увеличенная шайба под головку и под гайку/барашек. Головка болта — снаружи дома, барашек — внутри. Болт в середине стены и в центре проходит сквозь стойку и держит уголки с обеих сторон сразу.

## Порядок сборки


### 1. Разметка и лежни

Площадка — ровная, без камней. Разложить лежни по плану (СБОРКА.md), уголками внутрь клеток. Под лежни — подкладки (плитка, обрезки доски), выровнять уровнем.

### 2. Стойки

Начинать с угла. Стойка встаёт между концами двух лежней, метка «X» — вдоль конька. Болт М10×130 снаружи сквозь стойку в уголок лежня, барашек.
Каждая следующая стойка — по плану. В середине стены и в центре один болт держит уголки двух лежней.
Проверить диагонали каждой клетки — около 4525 мм.
Забить колья (арматура Ø12, 1 м) в отверстия лежней по периметру.

### 3. Верхняя обвязка

Со стремянки: обвязку — между верхами стоек, вровень с ними, болт М10×130 сквозь стойку в уголок на каждый конец.
Вдоль конька — уголками вниз, поперёк — перевернуть (уголками вверх). Перепутать нельзя: иначе болт не попадёт в отверстие стойки.
Пока нет пролётов, каркас «гуляет» — стойки придерживать.

### 4. Пролёты


Вдвоём поставить пролёт на лежень между стойками, фанерой наружу (заводить можно снаружи или изнутри — до обвязки 10 мм зазор).
4 болта М10×150 снаружи сквозь стойки в крайние стойки пролёта, барашки изнутри. Высоты разные для разных мест — болт попадёт только в своё отверстие.

### 2 болта М10×80 изнутри снизу вверх сквозь верхнюю перемычку пролёта в футорки

обвязки, ключом.
После пролётов каркас становится жёстким (держит фанера).

### 5. Фермы


На земле сложить полуфермы парами стойка к стойке, болт М10×130 с барашком. Крайние фермы — А + Б фанерой наружу дома, остальные — две средние.
Поднять ферму на обвязку (по человеку на стремянке с каждой стороны; большие — втроём). Крайние — над торцами дома, остальные — через 1,55 м (над каждой линией стоек и посередине между ними).
Пяты — болт М10×80 сверху сквозь затяжку в футорку: на линии стоек — в верх стойки, между ними — в середину обвязки.
Пока нет конька, ферма может завалиться вдоль дома — придерживать.

### 6. Конёк, прогоны, тент


Конёк — сразу после ферм, кусками от фронтона: на верх ферм, бобышки по обе стороны фермы, стыки кусков — над фермами.
Прогоны — в лапки стропил.
Тент — через конёк, края привязать за люверсы к лежням/кольям. Поверх — стяжные ремни через всю крышу (по 2 на клетку вдоль конька), концы под лежни, затянуть храповиком. Ремни прижимают тент, конёк и прогоны — их ничем больше не крепят.

## Разборка

Обратный порядок: ремни, тент → прогоны, конёк → болты пят, фермы вниз, разобрать на полуфермы → пролёты (сначала болты к обвязке, потом к стойкам) → обвязка → стойки → колья → лежни. Болты и барашки — сразу в ящик по длинам.

## Перевозка

Деталь | Размер | Масса
Пролёт | 2991 × 2400 × 53 | 25–34 кг
(или щит) | 997 × 2400 × 53 | 8–17 кг
Стойка | 100×100×2560 | 13 кг
Лежень / обвязка | 50×100×2996 | 8–10 кг
Полуферма малая / большая | ≈ 1980×680 / 3530×1170 | 5,5 / 9 кг (ферма — 11 / 19 кг)
Конёк, прогоны | до 3500 | до 9 кг

Пролёты 3 × 2,4 м — Газель с тентом или прицеп; если нет — щитами.

## Безопасность

На тентовую крышу не залезать.
В сильный ветер (> 15 м/с) — проверить ремни и колья; без кольев и ремней дом может сдвинуть ветром.
Пролёты и фермы поднимать вдвоём, стремянки — на ровном.

# Сборка дома 3х3


Каркас 3.2 × 3.2 м, высота до конька 3.24 м. Сетка 1 × 1 клеток. Общие правила и описание каждой детали — ../МОНТАЖ.md и ../ДЕТАЛИ.md. Что купить и сколько стоит — СПЕЦИФИКАЦИЯ_И_СМЕТА.md.

## План

Вид сверху, север — сверху, конёк — вдоль длинной стороны (слева направо). ■ — стойка; О — пролёт с окном, Г — глухой, Д — с дверью, · — открытый проём.

■─────О─────■
│ | │
Д | О
│ | │
■─────О─────■

## Комплект

Что | Шт.
Стойки | 4
Лежни | 4
Верхние обвязки | 4 (вдоль конька — 2, поперёк — 2, перевёрнутые)
Пролёты | 3 × «окно», 1 × «дверь»
Фермы (малые) | 3: 2 фронтонные (А+Б), 1 средних
Конёк / прогоны | 1 / 4 куск.

## Порядок

1. Лежни и стойки. Разложить 4 лежней по плану (уголками внутрь клеток), выровнять подкладками. Ставить стойки от угла: каждая — между концами лежней, болты М10×130 сквозь стойку в уголки (8 шт.). Диагонали каждой клетки равны (≈ 4525). Колья — в лежни по периметру.


2. Верхняя обвязка. 2 обвязок вдоль конька — уголками вниз; 2 поперёк — перевернуть (уголками вверх). Болт М10×130 сквозь стойку на каждый конец (8 шт.; в середине стены и в центре один болт держит два уголка).
3. Пролёты (3 × «окно», 1 × «дверь») — по плану: на лежень между стойками, 4 болта М10×150 сквозь стойки (барашки изнутри) + 2 болта М10×80 изнутри снизу в футорки обвязки.

4. Фермы (3 шт.): пары полуферм на земле, болт М10×130 с барашком. Крайние — над торцами (фанерой наружу), остальные через 1,55 м. Пяты — болтами М10×80 в футорки: на линиях стоек — в верх стоек, между ними — в середину обвязок.

5. Конёк (1 куск.) на верх ферм — бобышками по бокам; прогоны (4 куск.) — в лапки стропил; тент через конёк, края к люверсам/лежням; ремни (2 шт.) через крышу под лежни.


## Болты на площадке

Болт | Где | Шт.
М10×130 | уголки обвязок (верх стоек) | 8
М10×130 | фермы | 3
М10×80 | фермы | 6
М10×130 | уголки лежней (низ стоек) | 8
М10×150 | пролёты к стойкам и обвязке | 16
М10×80 | пролёты к стойкам и обвязке | 8
| всего | 49

## Время (2 человека, оценка)

Этап | Мин
Раскладка, разметка | 10
Лежни | 12
Стойки (+ колья) | 17
Верхняя обвязка | 16
Пролёты | 24
Фермы | 15
Конёк, прогоны | 6
Тент, ремни | 13
Итого | ≈ 113 (1.9 ч)

Время — оценка по нормам на операцию, вживую не проверено. Втроём — примерно на треть быстрее.

## Разборка

Обратный порядок: ремни, тент → прогоны, конёк → фермы (разобрать на полуфермы) → пролёты → обвязка → стойки → колья, лежни.

# Сборка дома 3х6


Каркас 6.3 × 3.2 м, высота до конька 3.24 м. Сетка 2 × 1 клеток. Общие правила и описание каждой детали — ../МОНТАЖ.md и ../ДЕТАЛИ.md. Что купить и сколько стоит — СПЕЦИФИКАЦИЯ_И_СМЕТА.md.

## План

Вид сверху, север — сверху, конёк — вдоль длинной стороны (слева направо). ■ — стойка; О — пролёт с окном, Г — глухой, Д — с дверью, · — открытый проём.

■─────О─────■─────Г─────■
│ | │ | │
Д | · | О
│ | │ | │
■─────О─────■─────О─────■

## Комплект

Что | Шт.
Стойки | 6
Лежни | 7
Верхние обвязки | 7 (вдоль конька — 4, поперёк — 3, перевёрнутые)
Пролёты | 4 × «окно», 1 × «глухой», 1 × «дверь»
Фермы (малые) | 5: 2 фронтонные (А+Б), 3 средних
Конёк / прогоны | 2 / 8 куск.

## Порядок

1. Лежни и стойки. Разложить 7 лежней по плану (уголками внутрь клеток), выровнять подкладками. Ставить стойки от угла: каждая — между концами лежней, болты М10×130 сквозь стойку в уголки (12 шт.). Диагонали каждой клетки равны (≈ 4525). Колья — в лежни по периметру.


2. Верхняя обвязка. 4 обвязок вдоль конька — уголками вниз; 3 поперёк — перевернуть (уголками вверх). Болт М10×130 сквозь стойку на каждый конец (12 шт.; в середине стены и в центре один болт держит два уголка).
3. Пролёты (4 × «окно», 1 × «глухой», 1 × «дверь») — по плану: на лежень между стойками, 4 болта М10×150 сквозь стойки (барашки изнутри) + 2 болта М10×80 изнутри снизу в футорки обвязки.


4. Фермы (5 шт.): пары полуферм на земле, болт М10×130 с барашком. Крайние — над торцами (фанерой наружу), остальные через 1,55 м. Пяты — болтами М10×80 в футорки: на линиях стоек — в верх стоек, между ними — в середину обвязок.

5. Конёк (2 куск.) на верх ферм — бобышками по бокам; прогоны (8 куск.) — в лапки стропил; тент через конёк, края к люверсам/лежням; ремни (4 шт.) через крышу под лежни.


## Болты на площадке

Болт | Где | Шт.
М10×130 | уголки обвязок (верх стоек) | 12
М10×130 | фермы | 5
М10×80 | фермы | 10
М10×130 | уголки лежней (низ стоек) | 12
М10×150 | пролёты к стойкам и обвязке | 24
М10×80 | пролёты к стойкам и обвязке | 12
| всего | 75

## Время (2 человека, оценка)

Этап | Мин
Раскладка, разметка | 10
Лежни | 21
Стойки (+ колья) | 23
Верхняя обвязка | 28
Пролёты | 36
Фермы | 25
Конёк, прогоны | 12
Тент, ремни | 21
Итого | ≈ 176 (2.9 ч)

Время — оценка по нормам на операцию, вживую не проверено. Втроём — примерно на треть быстрее.

## Разборка

Обратный порядок: ремни, тент → прогоны, конёк → фермы (разобрать на полуфермы) → пролёты → обвязка → стойки → колья, лежни.

# Сборка дома 3х9


Каркас 9.4 × 3.2 м, высота до конька 3.24 м. Сетка 3 × 1 клеток. Общие правила и описание каждой детали — ../МОНТАЖ.md и ../ДЕТАЛИ.md. Что купить и сколько стоит — СПЕЦИФИКАЦИЯ_И_СМЕТА.md.

## План

Вид сверху, север — сверху, конёк — вдоль длинной стороны (слева направо). ■ — стойка; О — пролёт с окном, Г — глухой, Д — с дверью, · — открытый проём.

■─────Г─────■─────О─────■─────Г─────■
│ | │ | │ | │
Д | · | · | О
│ | │ | │ | │
■─────О─────■─────О─────■─────О─────■

## Комплект

Что | Шт.
Стойки | 8
Лежни | 10
Верхние обвязки | 10 (вдоль конька — 6, поперёк — 4, перевёрнутые)
Пролёты | 5 × «окно», 2 × «глухой», 1 × «дверь»
Фермы (малые) | 7: 2 фронтонные (А+Б), 5 средних
Конёк / прогоны | 3 / 12 куск.

## Порядок

1. Лежни и стойки. Разложить 10 лежней по плану (уголками внутрь клеток), выровнять подкладками. Ставить стойки от угла: каждая — между концами лежней, болты М10×130 сквозь стойку в уголки (16 шт.). Диагонали каждой клетки равны (≈ 4525). Колья — в лежни по периметру.


2. Верхняя обвязка. 6 обвязок вдоль конька — уголками вниз; 4 поперёк — перевернуть (уголками вверх). Болт М10×130 сквозь стойку на каждый конец (16 шт.; в середине стены и в центре один болт держит два уголка).
3. Пролёты (5 × «окно», 2 × «глухой», 1 × «дверь») — по плану: на лежень между стойками, 4 болта М10×150 сквозь стойки (барашки изнутри) + 2 болта М10×80 изнутри снизу в футорки обвязки.


4. Фермы (7 шт.): пары полуферм на земле, болт М10×130 с барашком. Крайние — над торцами (фанерой наружу), остальные через 1,55 м. Пяты — болтами М10×80 в футорки: на линиях стоек — в верх стоек, между ними — в середину обвязок.

5. Конёк (3 куск.) на верх ферм — бобышками по бокам; прогоны (12 куск.) — в лапки стропил; тент через конёк, края к люверсам/лежням; ремни (6 шт.) через крышу под лежни.

## Болты на площадке

Болт | Где | Шт.
М10×130 | уголки обвязок (верх стоек) | 16
М10×130 | фермы | 7
М10×80 | фермы | 14
М10×130 | уголки лежней (низ стоек) | 16
М10×150 | пролёты к стойкам и обвязке | 32
М10×80 | пролёты к стойкам и обвязке | 16
| всего | 101

## Время (2 человека, оценка)

Этап | Мин
Раскладка, разметка | 10
Лежни | 30
Стойки (+ колья) | 29
Верхняя обвязка | 40
Пролёты | 48
Фермы | 35
Конёк, прогоны | 18
Тент, ремни | 29
Итого | ≈ 239 (4.0 ч)

Время — оценка по нормам на операцию, вживую не проверено. Втроём — примерно на треть быстрее.

## Разборка

Обратный порядок: ремни, тент → прогоны, конёк → фермы (разобрать на полуфермы) → пролёты → обвязка → стойки → колья, лежни.

# Сборка дома 6х6


Каркас 6.3 × 6.3 м, высота до конька 3.73 м. Сетка 2 × 2 клеток. Общие правила и описание каждой детали — ../МОНТАЖ.md и ../ДЕТАЛИ.md. Что купить и сколько стоит — СПЕЦИФИКАЦИЯ_И_СМЕТА.md.

## План

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

■─────О─────■─────О─────■
│ | │ | │
Д | · | Г
│ | │ | │
■─────·─────■─────·─────■
│ | │ | │
Г | · | О
│ | │ | │
■─────О─────■─────О─────■

## Комплект

Что | Шт.
Стойки | 9
Лежни | 12
Верхние обвязки | 12 (вдоль конька — 6, поперёк — 6, перевёрнутые)
Пролёты | 5 × «окно», 2 × «глухой», 1 × «дверь»
Фермы (большие) | 5: 2 фронтонные (А+Б), 3 средних
Конёк / прогоны | 2 / 16 куск.

## Порядок

1. Лежни и стойки. Разложить 12 лежней по плану (уголками внутрь клеток), выровнять подкладками. Ставить стойки от угла: каждая — между концами лежней, болты М10×130 сквозь стойку в уголки (18 шт.). Диагонали каждой клетки равны (≈ 4525). Колья — в лежни по периметру.


2. Верхняя обвязка. 6 обвязок вдоль конька — уголками вниз; 6 поперёк — перевернуть (уголками вверх). Болт М10×130 сквозь стойку на каждый конец (18 шт.; в середине стены и в центре один болт держит два уголка).
3. Пролёты (5 × «окно», 2 × «глухой», 1 × «дверь») — по плану: на лежень между стойками, 4 болта М10×150 сквозь стойки (барашки изнутри) + 2 болта М10×80 изнутри снизу в футорки обвязки.

4. Фермы (5 шт.): пары полуферм на земле, болт М10×130 с барашком. Крайние — над торцами (фанерой наружу), остальные через 1,55 м. Пяты — болтами М10×80 в футорки: на линиях стоек — в верх стоек, между ними — в середину обвязок. Большие фермы поднимать втроём; средняя линия стоек держит их под коньком.


5. Конёк (2 куск.) на верх ферм — бобышками по бокам; прогоны (16 куск.) — в лапки стропил; тент через конёк, края к люверсам/лежням; ремни (4 шт.) через крышу под лежни.

## Болты на площадке

Болт | Где | Шт.
М10×130 | уголки обвязок (верх стоек) | 18
М10×130 | фермы | 5
М10×80 | фермы | 10
М10×130 | уголки лежней (низ стоек) | 18
М10×150 | пролёты к стойкам и обвязке | 32
М10×80 | пролёты к стойкам и обвязке | 16
| всего | 99

## Время (2 человека, оценка)

Этап | Мин
Раскладка, разметка | 10
Лежни | 36
Стойки (+ колья) | 32
Верхняя обвязка | 48
Пролёты | 48
Фермы | 40
Конёк, прогоны | 12
Тент, ремни | 21
Итого | ≈ 247 (4.1 ч)

Время — оценка по нормам на операцию, вживую не проверено. Втроём — примерно на треть быстрее.

## Разборка

Обратный порядок: ремни, тент → прогоны, конёк → фермы (разобрать на полуфермы) → пролёты → обвязка → стойки → колья, лежни.

# Закупка и стоимость

Средние розничные цены строймагов РФ (Лемана ПРО / Леруа, Петрович, Сдвор, ОБИ, Максидом, Бауцентр, ВсеИнструменты), октябрь 2026, по поисковой выдаче из разных городов. Источники — в ../5/СТОИМОСТЬ.md. Подробная смета каждого дома — в его СПЕЦИФИКАЦИЯ_И_СМЕТА.md.

## Сводка, ₽

| 3×3 | 3×6 | 3×9 | 6×6
Пиломатериалы | 22 300 | 35 300 | 48 200 | 55 300
Фанера (ФСФ 3 мм + ФК 9 мм) | 6 400 | 9 500 | 12 600 | 13 400
Крепёж (болты, гайки, шайбы, футорки, уголки) | 6 700 | 10 500 | 14 300 | 15 300
Прочее (тент, ремни, колья, саморезы, клей, антисептик, дверь) | 10 200 | 16 400 | 22 600 | 24 000
Итого | ≈ 46 000 | ≈ 72 000 | ≈ 98 000 | ≈ 108 000
С запасом 10 % | ≈ 50 000 | ≈ 79 000 | ≈ 108 000 | ≈ 119 000
За м² каркаса | ≈ 4 500 | ≈ 3 600 | ≈ 3 300 | ≈ 2 700

Чем больше дом, тем дешевле квадратный метр: стойки и стены по периметру растут медленнее площади. Самая выгодная по площади — 6×6.

## Основные позиции

| 3×3 | 3×6 | 3×9 | 6×6
Брусок 25×50 (3–4 м) | 50 шт | 59 шт | 79 шт | 94 шт
Брус/доска 50×100×6000 | 5 | 9 | 13 | 14
Брус 100×100×3000 | 4 | 6 | 8 | 9
Фанера ФСФ 3 мм 1220×2440 | 15 | 21 | 27 | 29
Болты М10 ×80 / ×130 / ×150 (с запасом 10 %) | 42 / 21 / 18 | 64 / 32 / 27 | 86 / 43 / 36 | 82 / 46 / 36
Тент тарпаулин | 4×5 | ≥ 7×5 | ≥ 10×5 | ≥ 7×8

Точные количества (в т. ч. болтов, уголков, футорок) — в смете каждого дома.

## Где брать

Что | Где | Комментарий
Брусок 25×50 сухой строганый | лесобазы, Петрович/Сдвор (аналоги 20×45, 30×50) | в сетях мало; на лесобазе в ~2 раза дешевле
Брус 100×100, доска 50×100 | Петрович, Сдвор, лесобазы | у Леманы дороже в 1,5–2 раза; 6-метровые выгоднее
Фанера ФСФ 3 мм 1220×2440 | фанерные базы (Пиломаркет, Доски-Строй и т. п.) | в сетях почти нет; 4/4 — 350–390 ₽; если нет 3 мм — ФСФ 4 мм
Фанера ФК 9 мм 1525×1525 | любой строймаг | на косынки ферм
Болты, гайки, барашки, шайбы М10 | ВсеИнструменты, ОБИ, Петрович — упаковками | поштучно в 2–3 раза дороже
Футорки М10 вкручиваемые | крепёжные магазины, ВсеИнструменты | в сетях редко
Уголки KUU 90×90×40 | любой строймаг | маркировка «KUU», не «KUL»
Арматура Ø12 | строймаг (прутки 2,92 или 5,85 м) | режется на колья по 1 м
Тент тарпаулин 180 г/ м² | Лемана, автомагазины | для больших домов — 8×10 и подвернуть

## Экономия

Лес с лесобазы — минус 25–40 % от сметы (пиломатериалы — самая большая статья). Крепёж упаковками по 50–100 шт.
Брус 100×100 по 6 м (2 стойки из одного) — дешевле, чем по 3 м.
Если делать сразу несколько домов — общий набор кондукторов и оптовая закупка фанеры.

# Дом 3х3 — спецификация и смета

Габарит каркаса 3.2 × 3.2 м, высота до конька 3.24 м. Сгенерировано tools/grid_house.py. Цены — средние по строймагам РФ, октябрь 2026 (см. step/5/СТОИМОСТЬ.md), ≈ — оценка.

## Блоки

Блок | Шт.
стойка | 4
лежень | 4
обвязка | 4
пролёт окно | 3
пролёт дверь | 1
ферма | 3
конёк | 1
прогон | 4

## Смета

Позиция | Кол-во | Цена, ₽ | Сумма, ₽
Брус/брусок 25×50×3000 | 46 шт | ≈ 250 | 11 500
Брус/брусок 25×50×4000 | 4 шт | ≈ 333 | 1 332
Брус/брусок 50×100×6000 | 5 шт | 955 | 4 775
Брус/брусок 100×100×3000 | 4 шт | 1180 | 4 720
Фанера ФСФ 3 мм 1220×2440 | 15 листов | ≈ 370 | 5 550
Фанера ФК 9 мм 1525×1525 (косынки) | 1 | 885 | 885
Арматура Ø12 (кол 1 м) | 8 м | 80 | 640
Болт М10×130 | 21 шт | 57 | 1 197
Болт М10×150 | 18 шт | 54 | 972
Болт М10×80 | 42 шт | 28 | 1 176
Гайка М10 | 27 шт | 6.6 | 178
Гайка врезная (футорка) М10 | 31 шт | 35 | 1 085
Гайка-барашек М10 | 39 шт | 17 | 663
Петля карточная 100 мм | 2 шт | 160 | 320
Ремень стяжной с храповиком 6 м | 2 шт | 510 | 1 020
Ручка-скоба дверная | 1 шт | 140 | 140
Тент тарпаулин ≥ 4×5 м | 1 | ≈ 1 930 | 1 930
Уголок крепёжный усиленный KUU 90×90×40 | 16 шт | 46 | 736
Шайба М10 увеличенная | 146 шт | 4.6 | 672
Шпингалет накладной | 1 шт | 93 | 93
Саморезы, клей D3, антисептик | | ≈ | 6 081
Группа | ₽
Пиломатериалы | 22 327
Фанера | 6 435
Прочее | 10 224
Крепёж | 6 679
Итого | ≈ 45 665
С запасом 10 % | ≈ 50 231

Метизы — с запасом 10 %. Пиломатериал — в магазинных длинах, раскрой из модели с пропилом 4 мм.

## Раскрой

Сечение | Длина, мм | Шт.
100×100 | 2560 | 4
25×50 | 3500 | 4
25×50 | 2400 | 24
25×50 | 2050 | 2
25×50 | 2040 | 2
25×50 | 2025 | 6
25×50 | 1700 | 6
25×50 | 947 | 31
25×50 | 690 | 3
25×50 | 576 | 6
25×50 | 538 | 6
25×50 | 100 | 6
25×50 | 50 | 12
50×100 | 3500 | 1
50×100 | 2996 | 8

Масса без тента ≈ 285 кг.

# Дом 3х6 — спецификация и смета

Габарит каркаса 6.3 × 3.2 м, высота до конька 3.24 м. Сгенерировано tools/grid_house.py. Цены — средние по строймагам РФ, октябрь 2026 (см. step/5/СТОИМОСТЬ.md), ≈ — оценка.

## Блоки

Блок | Шт.
стойка | 6
лежень | 7
обвязка | 7
пролёт окно | 4
пролёт глухой | 1
пролёт дверь | 1
ферма | 5
конёк | 2
прогон | 8

## Смета

Позиция | Кол-во | Цена, ₽ | Сумма, ₽
Брус/брусок 25×50×4000 | 59 шт | ≈ 333 | 19 647
Брус/брусок 50×100×6000 | 9 шт | 955 | 8 595
Брус/брусок 100×100×3000 | 6 шт | 1180 | 7 080
Фанера ФСФ 3 мм 1220×2440 | 21 листов | ≈ 370 | 7 770
Фанера ФК 9 мм 1525×1525 (косынки) | 2 | 885 | 1 770
Арматура Ø12 (кол 1 м) | 12 м | 80 | 960
Болт М10×130 | 32 шт | 57 | 1 824
Болт М10×150 | 27 шт | 54 | 1 458
Болт М10×80 | 64 шт | 28 | 1 792
Гайка М10 | 40 шт | 6.6 | 264
Гайка врезная (футорка) М10 | 53 шт | 35 | 1 855
Гайка-барашек М10 | 59 шт | 17 | 1 003
Петля карточная 100 мм | 2 шт | 160 | 320
Ремень стяжной с храповиком 6 м | 4 шт | 510 | 2 040
Ручка-скоба дверная | 1 шт | 140 | 140
Тент тарпаулин ≥ 7×5 м | 1 | ≈ 3 378 | 3 378
Уголок крепёжный усиленный KUU 90×90×40 | 28 шт | 46 | 1 288
Шайба М10 увеличенная | 221 шт | 4.6 | 1 017
Шпингалет накладной | 1 шт | 93 | 93
Саморезы, клей D3, антисептик | | ≈ | 9 503
Группа | ₽
Пиломатериалы | 35 322
Фанера | 9 540
Прочее | 16 433
Крепёж | 10 501
Итого | ≈ 71 796
С запасом 10 % | ≈ 78 975

Метизы — с запасом 10 %. Пиломатериал — в магазинных длинах, раскрой из модели с пропилом 4 мм.

## Раскрой

Сечение | Длина, мм | Шт.
100×100 | 2560 | 6
25×50 | 3300 | 8
25×50 | 2400 | 36
25×50 | 2050 | 2
25×50 | 2040 | 2
25×50 | 2025 | 10
25×50 | 1700 | 10
25×50 | 947 | 45
25×50 | 690 | 3
25×50 | 576 | 10
25×50 | 538 | 10
25×50 | 100 | 10
25×50 | 50 | 20
50×100 | 3300 | 2
50×100 | 2996 | 14

Масса без тента ≈ 451 кг.

# Дом 3х9 — спецификация и смета

Габарит каркаса 9.4 × 3.2 м, высота до конька 3.24 м. Сгенерировано tools/grid_house.py. Цены — средние по строймагам РФ, октябрь 2026 (см. step/5/СТОИМОСТЬ.md), ≈ — оценка.

## Блоки

Блок | Шт.
стойка | 8
лежень | 10
обвязка | 10
пролёт окно | 5
пролёт глухой | 2
пролёт дверь | 1
ферма | 7
конёк | 3
прогон | 12

## Смета

Позиция | Кол-во | Цена, ₽ | Сумма, ₽
Брус/брусок 25×50×4000 | 79 шт | ≈ 333 | 26 307
Брус/брусок 50×100×6000 | 13 шт | 955 | 12 415
Брус/брусок 100×100×3000 | 8 шт | 1180 | 9 440
Фанера ФСФ 3 мм 1220×2440 | 27 листов | ≈ 370 | 9 990
Фанера ФК 9 мм 1525×1525 (косынки) | 3 | 885 | 2 655
Арматура Ø12 (кол 1 м) | 16 м | 80 | 1 280
Болт М10×130 | 43 шт | 57 | 2 451
Болт М10×150 | 36 шт | 54 | 1 944
Болт М10×80 | 86 шт | 28 | 2 408
Гайка М10 | 53 шт | 6.6 | 350
Гайка врезная (футорка) М10 | 75 шт | 35 | 2 625
Гайка-барашек М10 | 79 шт | 17 | 1 343
Петля карточная 100 мм | 2 шт | 160 | 320
Ремень стяжной с храповиком 6 м | 6 шт | 510 | 3 060
Ручка-скоба дверная | 1 шт | 140 | 140
Тент тарпаулин ≥ 10×5 м | 1 | ≈ 4 825 | 4 825
Уголок крепёжный усиленный KUU 90×90×40 | 40 шт | 46 | 1 840
Шайба М10 увеличенная | 295 шт | 4.6 | 1 357
Шпингалет накладной | 1 шт | 93 | 93
Саморезы, клей D3, антисептик | | ≈ | 12 924
Группа | ₽
Пиломатериалы | 48 162
Фанера | 12 645
Прочее | 22 642
Крепёж | 14 318
Итого | ≈ 97 767
С запасом 10 % | ≈ 107 544

Метизы — с запасом 10 %. Пиломатериал — в магазинных длинах, раскрой из модели с пропилом 4 мм.

## Раскрой

Сечение | Длина, мм | Шт.
100×100 | 2560 | 8
25×50 | 3300 | 8
25×50 | 3100 | 4
25×50 | 2400 | 48
25×50 | 2050 | 2
25×50 | 2040 | 2
25×50 | 2025 | 14
25×50 | 1700 | 14
25×50 | 947 | 59
25×50 | 690 | 3
25×50 | 576 | 14
25×50 | 538 | 14
25×50 | 100 | 14
25×50 | 50 | 28
50×100 | 3300 | 2
50×100 | 3100 | 1
50×100 | 2996 | 20

Масса без тента ≈ 617 кг.

# Дом 6х6 — спецификация и смета

Габарит каркаса 6.3 × 6.3 м, высота до конька 3.73 м. Сгенерировано tools/grid_house.py. Цены — средние по строймагам РФ, октябрь 2026 (см. step/5/СТОИМОСТЬ.md), ≈ — оценка.

## Блоки

Блок | Шт.
стойка | 9
лежень | 12
обвязка | 12
пролёт окно | 5
пролёт глухой | 2
пролёт дверь | 1
ферма | 5
конёк | 2
прогон | 16

## Смета

Позиция | Кол-во | Цена, ₽ | Сумма, ₽
Брус/брусок 25×50×4000 | 94 шт | ≈ 333 | 31 302
Брус/брусок 50×100×6000 | 14 шт | 955 | 13 370
Брус/брусок 100×100×3000 | 9 шт | 1180 | 10 620
Фанера ФСФ 3 мм 1220×2440 | 29 листов | ≈ 370 | 10 730
Фанера ФК 9 мм 1525×1525 (косынки) | 3 | 885 | 2 655
Арматура Ø12 (кол 1 м) | 16 м | 80 | 1 280
Болт М10×130 | 46 шт | 57 | 2 622
Болт М10×150 | 36 шт | 54 | 1 944
Болт М10×80 | 82 шт | 28 | 2 296
Гайка М10 | 53 шт | 6.6 | 350
Гайка врезная (футорка) М10 | 90 шт | 35 | 3 150
Гайка-барашек М10 | 81 шт | 17 | 1 377
Петля карточная 100 мм | 2 шт | 160 | 320
Ремень стяжной с храповиком 6 м | 4 шт | 510 | 2 040
Ручка-скоба дверная | 1 шт | 140 | 140
Тент тарпаулин ≥ 7×8 м | 1 | ≈ 5 404 | 5 404
Уголок крепёжный усиленный KUU 90×90×40 | 48 шт | 46 | 2 208
Шайба М10 увеличенная | 295 шт | 4.6 | 1 357
Шпингалет накладной | 1 шт | 93 | 93
Саморезы, клей D3, антисептик | | ≈ | 14 705
Группа | ₽
Пиломатериалы | 55 292
Фанера | 13 385
Прочее | 23 982
Крепёж | 15 304
Итого | ≈ 107 962
С запасом 10 % | ≈ 118 759

Метизы — с запасом 10 %. Пиломатериал — в магазинных длинах, раскрой из модели с пропилом 4 мм.

## Раскрой

Сечение | Длина, мм | Шт.
100×100 | 2560 | 9
25×50 | 3651 | 10
25×50 | 3300 | 16
25×50 | 3250 | 10
25×50 | 2400 | 48
25×50 | 2050 | 2
25×50 | 2040 | 2
25×50 | 1068 | 10
25×50 | 1066 | 10
25×50 | 947 | 59
25×50 | 690 | 3
25×50 | 420 | 10
25×50 | 100 | 10
25×50 | 50 | 40
50×100 | 3300 | 2
50×100 | 2996 | 24

Масса без тента ≈ 686 кг.

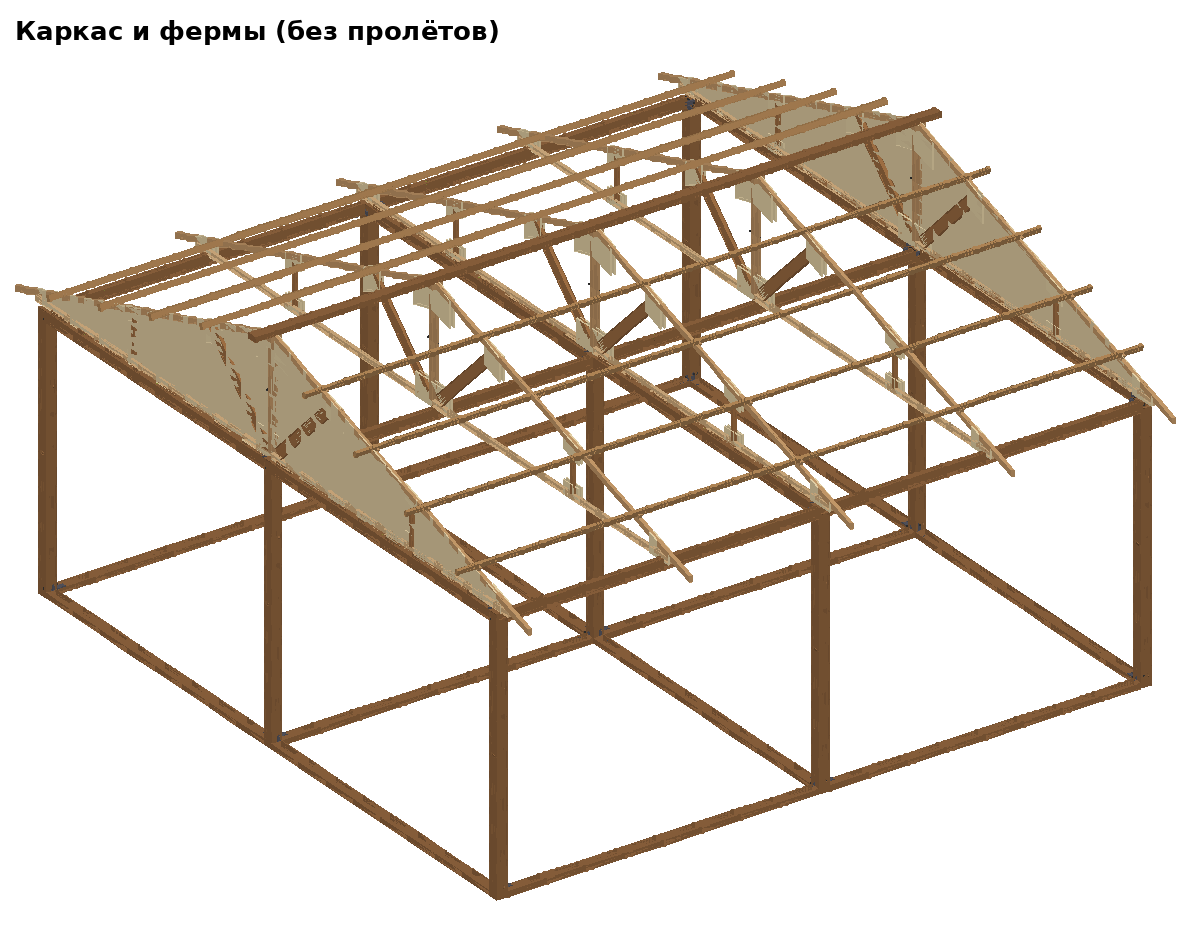
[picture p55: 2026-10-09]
step/6/6х6/img/каркас.png

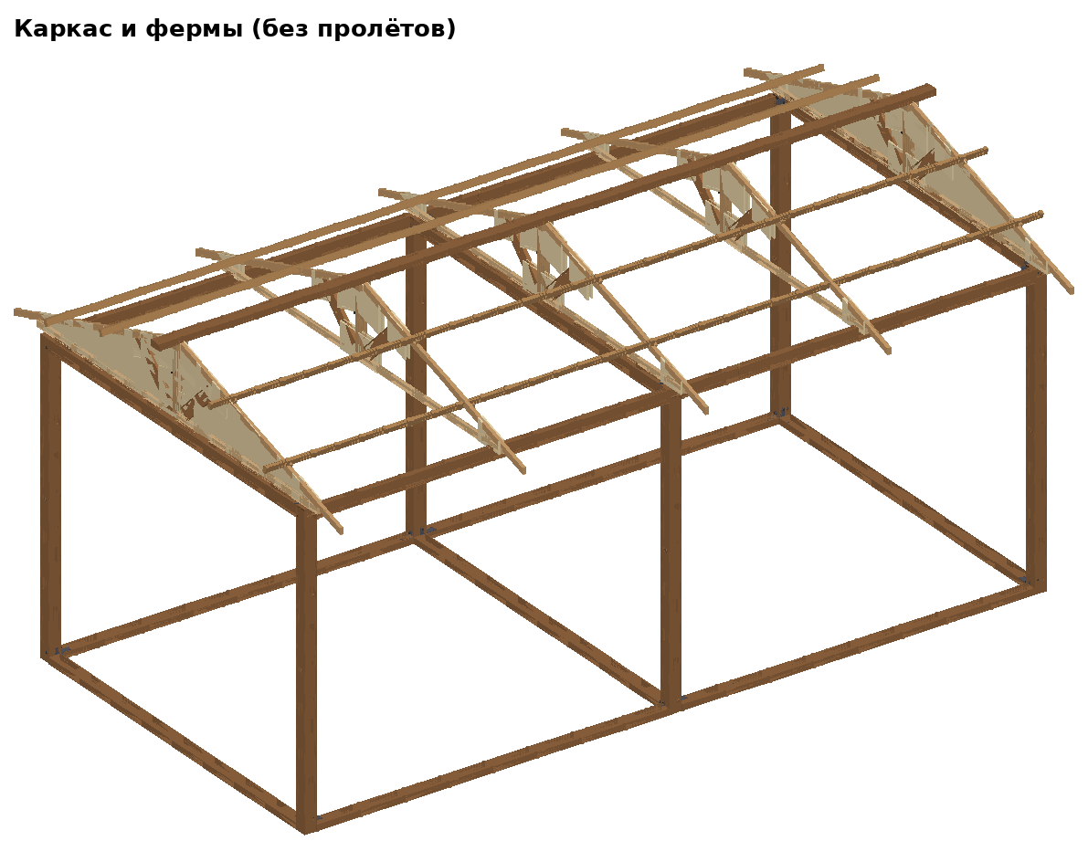
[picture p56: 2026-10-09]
step/6/3х6/img/каркас.png

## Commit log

2026-10-09 Add STEP export of version 4 for Fusion 360
    Recreate the v4 house (16 parts, 8 sub-assemblies, 122 bodies) as STEP
    files without SolidWorks: assembly tree and placements come from the
    COMPINSTANCETREE XML in the .SLDASM, part geometry from the face
    vertices stored in each .SLDPRT, including the 8 mm bolt holes.
    Parts are named by their actual dimensions.
    Claude-Session: https://claude.ai/code/session_01WZ3jooC47BZ8tQFmbRTbnu
2026-10-09 Add version 5: quick-assembly house from prefabricated blocks
    Parametric build123d model of a redesigned 3x3 house: permanent wall
    panels (blank, corner with post, window, door) and half-trusses made in
    the workshop; on site everything drops onto pins and is closed with
    lever latches, R-clips and 3 wing bolts. Adds base rails with anchors,
    plywood-sheathed panels, gusseted trusses on edge, closed gables,
    purlins and a one-piece tarp. Includes STEP files for the house and each
    block, assembly instructions with step images, and a generated cut
    list / hardware specification. Model is clash-checked and every pin is
    verified to engage its mating part.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
    [дом_v5_3х3.step, конёк.step, лежень_X.step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]
2026-10-09 Rework version 5 into frame + wall spans
    Restructure v5 to the intended assembly hierarchy: panels (blank,
    window, door) are bolted into 3-panel wall spans; on site a frame of
    base rails, four 100x100 corner posts in steel sockets and four lapped
    top beams is erected, the spans are tilted into the frame openings from
    outside against stop strips and locked with turn buttons, then the
    trusses, ridge, purlins and tarp go on top. Heel pins pass through the
    post tops and beam laps into the end trusses. Model is clash-free and
    every pin engages its mating part; instructions, specification and
    illustrations regenerated.
    Claude-Session: https: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
    [дом_v5_3х3.step, конёк.step, лежень_X.step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]
2026-10-09 v5: only off-the-shelf M10 bolts, no custom pins
    Replace glued steel pins, R-clips, steel sockets and turn buttons with
    store-bought hardware: M10 bolts of six lengths with nuts, wing nuts and
    threaded inserts, galvanised 100x100 post supports, rebar stakes and
    ratchet straps. Base rails become 50x150 boards with a bolted lap,
    spans are bolted to the corner posts, trusses are bolted through the
    top plates into inserts, the ridge sits on wooden cleats. Model is
    clash-free and every bolt is checked to pass through its parts with
    room for the nut. Instructions rewritten in plain language with a
    glossary and a bolt table.
    Claude-Session: h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
    [дом_v5_3х3.step, конёк.step, лежень_X.step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]
2026-10-09 v5: regenerate illustrations for the bolted version
    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
2026-10-09 v5: rails and top plates between posts on brackets, no stop strips
    Drop the lap joints and stop strips. Base rails (50x100) and top plates
    now sit between the corner posts and are held by galvanised 90x90x40
    angle brackets bolted through the posts; spans stand on the rails and
    are bolted to the posts and, from inside, into threaded inserts in the
    top plate. All four rails are identical. Hardware reduced to three M10
    bolt lengths (80/130/150). Clash-free, every bolt checked; instructions
    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
    [дом_v5_3х3.step, конёк.step, лежень.step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]
2026-10-09 v5: regenerate illustrations for the bracket version
    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
2026-10-09 v5: switch panel sheathing to 3 mm plywood
    Sheathing, door leaf and gable cladding are now FK 3 mm plywood (thinnest
    common store stock). Span becomes 53 mm thick, span bolt axis 28 mm from
    the outer face; house mass drops to about 285 kg. Clash and bolt checks
    pass; STEP, specification, instructions and images regenerated.
    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
    [дом_v5_3х3.step, конёк.step, лежень.step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]
2026-10-09 v5: add material cost estimate from RF store prices
    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
2026-10-09 v5: use FSF 3 mm plywood 1220x2440 (one sheet per panel)
    Switch panel sheathing to waterproof FSF 3 mm in full 1220x2440 sheets:
    each 997x2400 panel is cut from one sheet with no joint, so no extra
    crossbars are needed. Specification, instructions and cost estimate
    updated (about 45k RUB from stores, 35.5k with lumber from a yard).
    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
    [дом_v5_3х3.step, конёк.step, лежень.step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]
2026-10-09 Add version 6: modular grid system with 3x3 and 6x6 houses
    Generalise the house into a 3.1 m grid. Identical, unrotated corner,
    wall and centre posts with symmetric through-holes at direction-specific
    heights; rails and top plates on angle brackets between any two posts
    (one through bolt clamps brackets on both sides of a post); spans fit
    any perimeter opening. Roof: small trusses for 1-cell width, new large
    half-trusses for 2-cell width supported by the middle post line.
    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
    [дом_3х3.step, дом_6х6.step, лежень.step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]
2026-10-09 v6: add 3x6 and 3x9 houses and full documentation
    Top plate becomes a single reversible part (inserts on both faces;
    flipped for edges across the ridge). Add the 3x9 configuration and
    generated per-house assembly guides (plan, kit, steps, bolt counts,
    time estimate). Documentation: system overview and glossary, workshop
    instructions for every part, general site assembly, and a purchasing
    summary for 3x3, 3x6, 3x9 and 6x6. All four configurations are
    clash-free.
    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
    [дом_3х3.step, дом_3х6.step, дом_3х9.step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]
2026-10-09 Add printable PDF of the documentation; remove versions 1-4
    Build step/6/Модульные_дома.pdf (cover, system, parts, site assembly,
    assembly of 3x3/3x6/3x9/6x6, purchasing, specifications) with
    tools/make_pdf.py. Remove the SolidWorks versions 1-4, the v4 STEP
    export and the v4-only tools; the STEP writer used by v5/v6 moves to
    tools/step_io.py. README rewritten around the current version.
    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
2026-10-13 v6: прогоны плашмя на болтах, тент на резинках, анимация сборки
    Крыша:
    - прогоны 25×50 плашмя, на каждой ферме болт М10×80 в опору стропила
    (вместо лапок); добавлен карнизный прогон
    - конёк на ферме — 2 болта М10×130 сквозь бобышки и стойки полуферм
    - тент: край завёрнут под карнизный прогон, люверсы — резинками с шариком;
    стяжные ремни убраны
    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
2026-10-13 Refactor: larphouse package, Latin paths, data files, tests
    - Код из tools/ (grid_house, v5_house, v5_draw, grid_draw, grid_anim,
    check_house, make_pdf) разложен по пакету larphouse/: dims, geom, tally,
    panels, frame, roof, house, estimate, assembly, render, drawings, anim,
    check, pdf; CLI — python -m larphouse.
    - v6 больше не зависит от v5; версия 5 удалена, источники цен перенесены
    в docs/purchasing.md.
    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
2026-10-13 Frame joints: rolled steel angle 63×63×6 instead of KUU, inserts on epoxy
    - Уголок г/к 63×63×6 (отрезок 40 мм) вместо штампованного KUU 90×90×40:
    к лежню и обвязке притянут насквозь болтом М10×80 с гайкой (мастерская,
    не снимается), к стойке — как раньше, М10×130 с барашком.
    - В уголке лежня оба отверстия (26 и 48 мм над лежнем) — все лежни одинаковые;
    высоты болтов уголков лежня в стойке: X 76, Y 98.
    - Футорки М10 — на эпоксидке; в смете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
2026-10-13 Regenerate images and PDF for new frame joints
    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
